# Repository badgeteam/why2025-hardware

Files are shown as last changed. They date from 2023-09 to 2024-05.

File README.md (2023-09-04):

# mch2025-hardware
Hardware design files for the MCH2025 badge

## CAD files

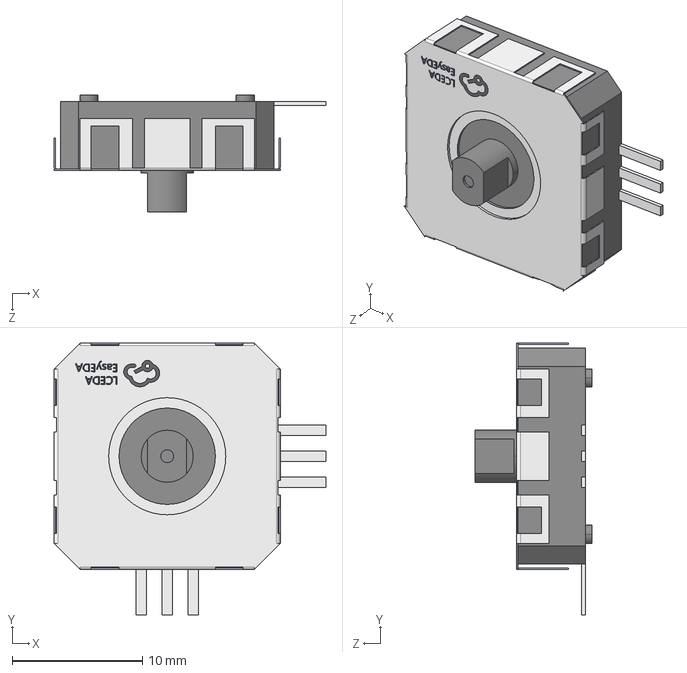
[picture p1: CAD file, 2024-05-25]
frontpanel/analog_joystick/SW-SMD_K1-1539SA-01.step
20.9 x 20.9 x 9.00 mm

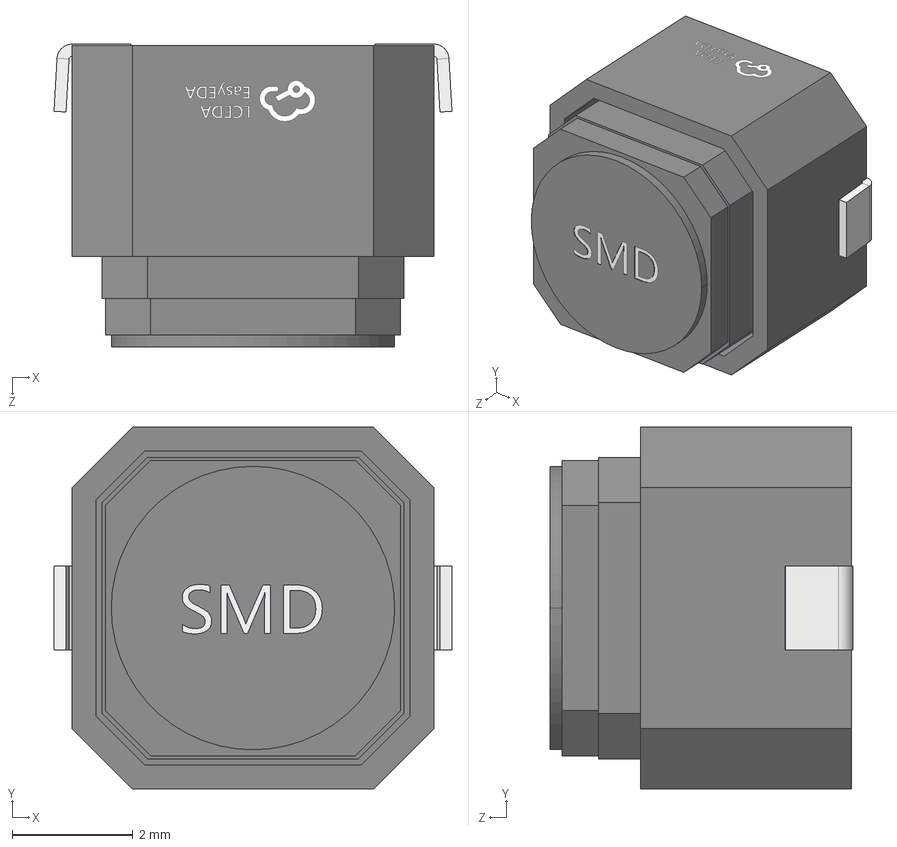
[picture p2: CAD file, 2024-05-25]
frontpanel/button_footprint/KEY-SMD_2P-L6.0-W6.0-H5.0-P6.00.step
6.60 x 6.00 x 5.02 mm

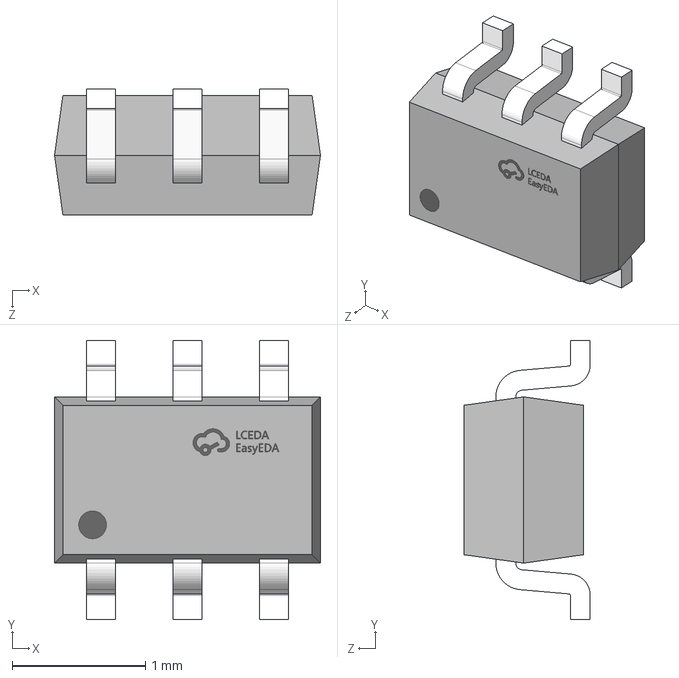
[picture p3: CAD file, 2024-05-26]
frontpanel/ideal_diode/SC-70-6_L2.0-W1.3-P0.65-LS2.1-BL.step
2.00 x 2.10 x 0.951 mm

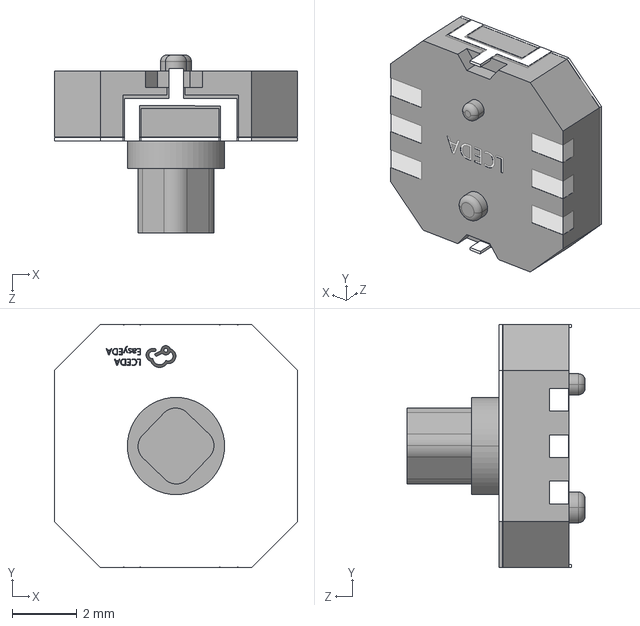
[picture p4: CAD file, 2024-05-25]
frontpanel/joystick_footprint/SW-SMD_SKRHABE010.step
7.50 x 7.50 x 5.50 mm

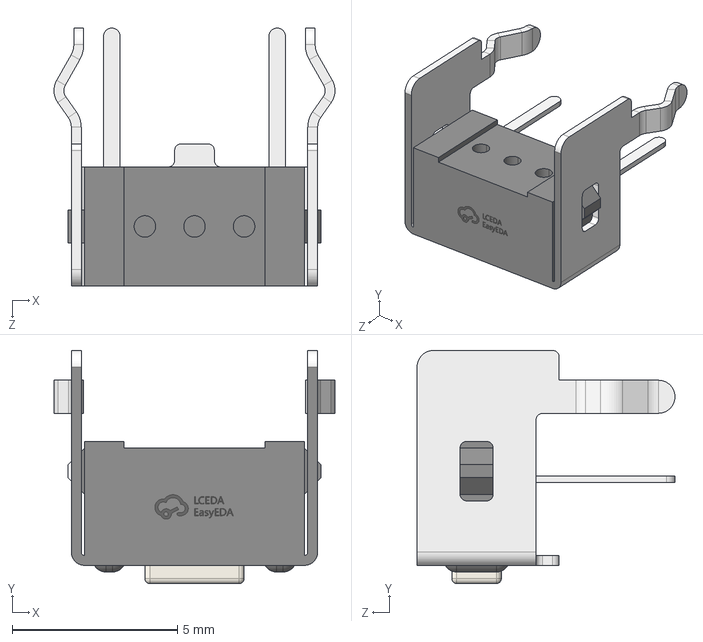
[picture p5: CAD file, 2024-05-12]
frontpanel/shoulderbutton/KEY-TH_4P-L7.5-W4.3-H4.3-LS7.0-P5.0.step
8.50 x 7.05 x 7.80 mm

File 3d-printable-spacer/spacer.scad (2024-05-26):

height = 2;

translate([0,0,height]) translate([0,0,height/2]) linear_extrude(height = height, center = true, convexity = 10, twist = 0, slices = 20, scale = 1.0, $fn = 16) import(file = "spacer.svg", center = true, dpi = 96);

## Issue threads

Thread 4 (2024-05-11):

P4 boot pins

renzenicolai, 2024-05-11:
- Add pullup resistors to GPIO 35 and 36
 - Add button to pull GPIO 35 to GND for entering boot mode

Closed 2024-06-15.

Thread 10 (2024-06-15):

USB device port problems

renzenicolai, 2024-06-15:
BQ25895 power negotiation is faulty and causes issues.

If we disable the power negotiation the vbus line of the usb port will always be 5v and thus it will be usable to power the usb hub directly.

- [x] Disconnect D+/D- from the BQ25895
- [x] Disconnect reset of USB hub from DSEL
- [x] Connect V5 pin of USB hub to USB_VBUS

ranzbak, 2024-07-27:
Put solder jumper in place, so the USB data lines are disconnected by default but can used when debugging.

renzenicolai, 2024-07-27:
In the end I just removed the USB port pins of the CH32. The usb serial converter idea of @ranzbak is much better so let's go with that.

Closed 2024-08-21.

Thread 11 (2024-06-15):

Power button

renzenicolai, 2024-06-15:
- [ ] Power button should pull the PWR_ON line to 3.3v, not GND

or

- [ ] Attach power button directly to QON (other side of transistor)
- [ ] Add high-resistance voltage divider to QON to feed back into CH32V203

renzenicolai, 2024-06-15:
Second solution is preferred

Closed 2024-08-21.

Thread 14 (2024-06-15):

Backlight dimming

renzenicolai, 2024-06-15:
Current approach with PWMing the enable signal isn't working great.

Research why, maybe find other methods for dimming backlight.

ranzbak, 2024-07-24:
- Suggestions: Make the connection to the 10uF capacitor thicker, to lower inductance.
- The PWM frequency is too high for the chip to follow?

They suggest something above 25kHz in the datasheet, but in the picture below it's up to 25kHz PWM.

So test with 25kHz PWM?

https://www.diodes.com/assets/Datasheets/AP3032.pdf page 10

Closed 2024-09-11.

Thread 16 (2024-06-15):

Fuses

renzenicolai, 2024-06-15:
The 2A fuses on both USB and on battery connector may need to be exchanged for a higher rated fuse as 2A is within normal operating conditions. Maybe use 3A fuses instead?

ranzbak, 2024-07-24:
I forgot what the problem was, the unrush current, or the fact that some devices can use more in general?

When the Fuses blowing results in a broken port, we might want to consider a poly fuse with a hold current of 2A.

https://www.lcsc.com/product-detail/Resettable-Fuses_BHFUSE-BSMD1206-200-6V_C883134.html

According to the datasheet the resistance is between 0.015 and 0.08Ω, which is 0.24V drop at 3A.

Closed 2024-08-21.

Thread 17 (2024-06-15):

Power switch for USB-A port and addressable LEDs

renzenicolai, 2024-06-15:
Add a power switch to turn off the USB-A port in standby mode. Disabling the booster in the PMIC does not result in 0 volt on the 5v pin of the USB connector but instead leaves VSYS on that line. It should be completely turned off.

Also a power switch would allow for setting a current limit.

ranzbak, 2024-07-24:
We can put in a p-channel FET, it'll be a small drop in voltage.

Something like this part ? https://www.lcsc.com/product-detail/MOSFETs_HXY-MOSFET-HXY2305AI_C3033391.html

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

Closed 2024-08-22.

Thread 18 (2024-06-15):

Connector of LCD

renzenicolai, 2024-06-15:
Current connector is too wide, replace with smaller replacement connector and adjust footprint.

Correct connector: DF37NB-24DS-0.4V(51)

https://www.digikey.nl/en/products/detail/hirose-electric-co-ltd/DF37NB-24DS-0-4V-51/2230603

ranzbak, 2024-07-22:
https://github.com/badgeteam/why2025-hardware/pull/32

renzenicolai, 2024-07-23:
To-do: verify that new connector is in the correct physical location.

ranzbak, 2024-07-23:
We need to do that with a real prototype I guess :-).

Closed 2024-07-27.

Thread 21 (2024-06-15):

Change footprint of P4 to match production version

renzenicolai, 2024-06-15:
Also make the pins accessible from the side of the chip, for fixing faulty connections by hand.

renzenicolai, 2024-07-14:
- [ ] Acquire up-to-date datasheet
- [ ] Acquire new chips (send to Allnet)

Closed 2024-08-21.

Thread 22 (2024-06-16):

Discuss and choose size of backplate screw holes

renzenicolai, 2024-06-16:
Prototype 1 has M2 holes in the mainboard. These could be replaced by 1.6mm holes to attach a base the same way as the frontpanel, we could look into using solderable nuts or we could find a way to allow for attaching a case from the front, screwing the M2 bolt into the plastic of the case.

This all needs more research.

Closed 2024-08-22.

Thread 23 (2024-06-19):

Speaker gets hot

renzenicolai, 2024-06-19:
Needs research.

One idea is that we may even be able to get away without the amplifier.

- [ ] Test how loud the speaker is when directly connected to the DAC.
- [ ] Test if HPCOM can be used to control speaker on/off.
- [ ] Test if transistor can be used to switch low side of speaker (add diode?).

ranzbak, 2024-07-15:
Please check out : https://github.com/badgeteam/why2025-hardware/pull/29

Closed 2024-08-21.

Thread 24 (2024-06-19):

Camera pinout mirrored

renzenicolai, 2024-06-19:
Currenct connector is bottom contact.

- [ ] Switch to top contact connector

ranzbak, 2024-07-14:
What you are trying to say is that the pins 1 -> 22 needs to be 22->1 ?

Closed 2024-07-27.

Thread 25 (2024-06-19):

Unstable power rail / USB device port connection

renzenicolai, 2024-06-19:
Needs some more testing and research, the VSYS rail seems very unstable.

renzenicolai, 2024-07-14:
Turns out you can configure the current taken from the usb device port on the PMIC. We did that and now it's stable.

ranzbak, 2024-07-22:
Close this one in that case?

renzenicolai, 2024-07-22:
Nah, needs some more playing around with. For example the USB-A port can still cause the P4 do go into brownout so there is more stuff wrong here. I think it's mainly to do with the voltage on the VSYS rail still. Maybe we should look for a DC-DC for the 3.3v rail that can handle lower input voltages.

renzenicolai, 2024-07-27:
Check that the DC-DC has a low enough minimum input voltage to be able to use the whole battery.

Closed 2024-08-21.

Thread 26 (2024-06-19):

Disconnect PMIC from D+ / D- of device port

renzenicolai, 2024-06-19:
Negotiation is bugged (see chip errata) and causes issues. Also if we don't connect this VBUS is always 5v, which is nice because then we can power the USB hub IC directly from VBUS.

renzenicolai, 2024-06-21:
Disconnected D+ and D- from PMIC, disconnected RESET of USB hub from PMIC and connected 5V pin of USB hub to VBUS.

Note: the USB hub has a built-in pull-up resistor on the RESET line.

Closed 2024-06-21.

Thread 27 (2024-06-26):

Battery

renzenicolai, 2024-06-26:
- Check if we can find an 18650 battery holder with a footprint that fits in the keyboard matrix area
 - Maybe move the keyboard matrix wiring to an inner layer, we don't need the 3.3v power layer on the lower half of the board anyway.

ranzbak, 2024-07-22:
The battery at the bottom, wouldn't that be more stable?
Also we might want to tape the battery to the prototype and see where it holds best.
Also with the battery at the bottom it might even stand up by it self. (bonus)

Closed 2024-08-22.

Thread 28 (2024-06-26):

Turn on backlight by default

renzenicolai, 2024-06-26:
When the CH32V203 isn't active the display backlight should be on at full brightness.

ranzbak, 2024-07-15:
Given that the pb3 will be high impedance after reset, pull the pin up using the 100k resistor to VCC?
@Renze, do you know if the pin is in high impedance after reset, or when the ch32v203cxt6 is disabled, I couldn't find in the datasheet.

ranzbak, 2024-07-27:
Done

Closed 2024-07-27.

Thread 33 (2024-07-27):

Check protection circuit

renzenicolai, 2024-07-27:

ranzbak, 2024-07-27:
The rail to in v-in is ~1.5V for the LM339, when supplied with 3.3V, the max is 1.8V that can be compared.
So a rail to rail sulution is needed.

LCSC nummer: C4944986
Not too expensive: https://www.lcsc.com/product-detail/Operational-Amplifier_UMW-Youtai-Semiconductor-Co-Ltd-LMV324IDR_C4944986.html
Datasheet: https://www.lcsc.com/datasheet/lcsc_datasheet_2312211124_UMW-Youtai-Semiconductor-Co---Ltd--LMV324IDR_C4944986.pdf

ranzbak, 2024-07-29:
The 1V reference was pulled down to 1V.
Looked at voltage references to provide the 1V, they are pretty expensive.
When looking into the problem further we are trying to solve, protecting the chips from over voltage limiting the voltage is enough.
Given that the p4 at max can deliver 100mA current, a Zener that clamps the voltage is sufficient to protect the IC's involved.

Long story short, replaced the VPSRAM, VMIPI, VFLASH rail protection with zener diodes.
VESPHP is unprotected as the voltage is set by a resistor devider, en de EN_DCDC P4 can already disable the U3 vcore regulator if it's unhappy.

ranzbak, 2024-07-29:
https://github.com/badgeteam/why2025-hardware/pull/39

Closed 2024-08-21.

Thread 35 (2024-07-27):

Add USB to serial converter for programming P4

renzenicolai, 2024-07-27:

renzenicolai, 2024-07-27:
Maybe also connect it to P4 reset & boot pins via the special circuit found on most ESP32 devboards (see P4 devkit schematic)

Closed 2024-08-21.

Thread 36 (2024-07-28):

Add Bosch sensors

renzenicolai, 2024-07-28:

JayVisschedijk, 2024-07-28:
Design symbol, footprint, test board for sponsored Bosch sensors

JayVisschedijk, 2024-07-28:
How many sensors are we talking about? And do we already know which ones specifically?

renzenicolai, 2024-07-28:
Position sensor BHI360 and gas sensor BME690 :smile:

JayVisschedijk, 2024-07-28:
For the BHI360 symbol and footprint:
https://www.snapeda.com/parts/BHI360/Bosch/view-part/

About the BME690 I can't find enough info on their site, did we receive inside information we can use to create a symbol and footprint?

renzenicolai, 2024-07-29:
BHI360 needs 1.8v IO voltage. That's a bit annoying because we'd need to add a regulator and a level shifter for the I2C bus.

Closed 2024-08-22.

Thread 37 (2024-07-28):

Hexpansion

renzenicolai, 2024-07-28:
Maybe we can fit this on there somewhere?

https://www.lcsc.com/product-detail/Card-Edge-Connectors_HCTL-HC-SFP-20P_C2897291.html

https://tildagon.badge.emfcamp.org/
https://tildagon.badge.emfcamp.org/hexpansions/creating-hexpansions/

renzenicolai, 2024-07-28:
Had a play with the two holes and SFP connnector on our board and I can't find any space to put it. Alternative could be to make a backplate that adds hexpansion ports, let's go with that.

Closed 2024-08-21.

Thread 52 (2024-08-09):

Move PMIC closer to battery terminal

renzenicolai, 2024-08-09:
VBAT on the PMIC drops too much.

Closed 2024-08-21.

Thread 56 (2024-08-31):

LED level shifter

renzenicolai, 2024-08-31:
Choose a different buffer, this one is just as much out of spec as the LEDs themselves.

renzenicolai, 2024-08-31:
https://www.lcsc.com/product-detail/Buffer-Driver-Transceiver_Nexperia-74LVC1G17GW-125_C426705.html

Pincompatible, but with correct voltages.

Closed 2024-09-11.

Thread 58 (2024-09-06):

Do we need changes to the spacer between the PCB's to account for the LORA antenna?

ranzbak, 2024-09-06:

renzenicolai, 2024-09-12:
The spacer will be (re)designed by Yvo to take into account all the little bits of metal in the way.

Closed 2024-09-12.

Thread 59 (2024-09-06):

VESPHP now is very close to 1.20V which is the max voltage, would 1,12 V be better?

ranzbak, 2024-09-06:
Replacing R40 with a 430K resistor would put the set voltage at 1,12V.

In the ESP32 P4 sheet (V0.4), page 62 bottom of the page for reference.

arturo182, 2024-09-08:
Surprisingly, the official Espressif EV Board also uses 2x499K:

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

From https://docs.espressif.com/projects/esp-dev-kits/en/latest/_static/esp32-p4-function-ev-board/schematics/esp32-p4-function-ev-board-schematics.pdf

This of course is:

$$0.6V * (1 + \frac{499K}{499K}) = 1.2V$$

My guess would be this is because the ESP32-P4 uses the `FB_DCDC` pin to adjust the voltage as needed so the default of 1.2V as a starting point is not a problem for them?

renzenicolai, 2024-09-11:
Yeah, I checked and the rev 0.1 version of the development board still has it like this in the schematic, let's copy what Espressif does 😄

Closed 2024-09-11.

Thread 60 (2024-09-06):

CH334R can operate without crystal, option ?

ranzbak, 2024-09-06:
In the datasheet, chapter 6.2:

6.2 Crystal-free Application, Bus-powered

renzenicolai, 2024-09-11:
I'm not sure the CH334R can be ran without crystal. However it is easy enough to test this by removing the crystal and shorting a specific signal pin to ground. I can try testing this on one of the non-working boards tomorrow.

renzenicolai, 2024-09-12:
Tested, doesn't work with the version of the CH334R we have.

arturo182, 2024-09-12:
The datasheet is a bit confusing on this, like it's a specially ordered version?
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

Closed 2024-09-12.

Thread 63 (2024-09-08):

Camera connector needs two gpios, not one.

renzenicolai, 2024-09-08:
https://www.raspberrypi.com/documentation/computers/raspberry-pi.html#raspberry-pi-zero
https://www.arducam.com/raspberry-pi-camera-pinout/

Closed 2024-09-11.

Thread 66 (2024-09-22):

Bringup of WHY2025 prototype 2

renzenicolai, 2024-09-22:
Power:
- [x] Check for short circuit on VBUS rail
- [x] Check for short circuit on 3.3v rail
- [x] Power device via USB without battery attached
- [x] Check 3.3v rail voltage
- [x] Check 2.5v standby rail voltage
- [x] Check VSYS rail voltage
- [x] Check 1.8v rail
- [x] Check battery connector voltage
- [x] Check powering badge from battery
- [x] Check charging of battery
- [x] Measure power usage

Basic device bringup:
- [x] Check that USB hub works
- [x] Check that C6 shows up via USB
- [x] Check that USB serial converter shows up via USB
- [x] Access P4 using esptool.py via the USB-serial chip (works after swapping rx/tx)
- [x] Flash firmware to P4 using esptool.py (via usb-serial)
- [x] Flash firmware to C6 using esptool.py (via native USB)

In- and output interfaces:
- [x] Check display
- [x] Check SD card reader
- [x] Check keyboard buttons
- [x] Check boot button
- [x] Check power button
- [ ] Check I3C functionality
- [x] Check powering USB-A connected device on USB power
- [x] Check powering USB-A connected device on battery power
- [x] Check USB-A host port
- [ ] Check that camera works
- [x] Test JTAG interface
- [x] Test GPIOs on external expansion header
- [x] Test GPIOs on internal expansion header
- [x] Check display backlight
- [x] Check keyboard backlight
- [x] Check PWM dimming of display backlight
- [x] Check PWM dimming of keyboard backlight

On-board communication:
- [x] Check SDIO communication between P4 and C6
- [x] Check that CH32V203 can be programmed by P4
- [x] Check I2C communication on internal I2C bus
- [x] Check i2C communication on power management I2C bus
- [x] Check power button press emulation for CH32V203

renzenicolai, 2024-10-06:
In need of firmware to test:
 - Camera (a simple camera to screen firmware would be super useful)
 - USB-A port (a simple USB host example would be super useful)

renzenicolai, 2024-11-01:
Unable to test camera port at this time, skipping test.

renzenicolai, 2024-11-01:
To be continued in https://github.com/badgeteam/why2025-hardware/issues/95

Closed 2024-11-01.

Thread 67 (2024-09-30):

esp32p4.kicad_sch lists wrong part number for U8

michaesc, 2024-09-30:
## Context

The schematic (and layout) claims that the LCSC part number C22387510 corresponds with a part labeled flash, probably the external storage used by the P4.

## Problem

The LCSC database has no entry for the part number C22387510, so this is possibly an error or a incorrect entry.

## Solution

If the part U8 is a real part sold by LCSC, then the correct part number should be recorded in the schematic.

michaesc, 2024-09-30:
The U8 is not really a flash storage part, and the LCSC part number is correct. The reason that LCSC fails to find it today is due to a early entry for the ESP32-P4 part that is not avialable yet.

Closed 2024-09-30.

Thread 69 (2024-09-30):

Add pull-up resistor to GPIO34

renzenicolai, 2024-09-30:
For using the JTAG interface GPIO34 (E2 on the internal expansion port) can be used to select between USB jtag and the JTAG pins on the external expansion port.

Add a pull-up resistor to E2 (GPIO34) to select USB jtag by default on boards where this fuse has been burned.

 - burn JTAG_SEL_ENABLE to 1
 - pull E2 (GPIO34) low
 - reset ESP32-P4

Maybe we could add a footprint for a 10-pin JTAG header too somewhere?

renzenicolai, 2024-09-30:
Extra ideas:
 - Add testpoint to P4 reset pin next to the RX and TX pins
 - Add solder jumper for shorting E2 to ground

ranzbak, 2024-10-04:
Pullup resistor 51K added to GPIO34.

Leaving the ticket open for a bit to see if there is space for a 10 pin JTAG header.

renzenicolai, 2024-10-06:
Continued in #82

Closed 2024-10-06.

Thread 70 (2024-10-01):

Trace under impedance resistors USB line move

ranzbak, 2024-10-01:
On the board, from the USB hub to the C6, the Lora int line runs under the two impedance match resistors.

R17 and R18.

The trace should be rerouted to around the USB signal.

This is needed because the signal being between the resistors and the ground plain, breaks the ground reference for the diff pair signal.

ranzbak, 2024-10-04:
C6 interrupt line moved.

Closed 2024-10-04.

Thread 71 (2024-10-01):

ESP32-C6 USB interface problems

renzenicolai, 2024-10-01:

renzenicolai, 2024-10-06:
Workaround: add 1.5k resistor between C6 EN pin and D+

renzenicolai, 2024-10-06:
Workaround implemented in board design.

ranzbak, 2024-11-01:
For now we leave the workaround resistor in, as the solution is stable.
If Espressif comes with the real solution we can implement that.

Closed 2024-11-01.

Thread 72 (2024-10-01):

Screwhole bottom center needs to be moved down a bit

renzenicolai, 2024-10-01:

renzenicolai, 2024-10-01:
2mm

ranzbak, 2024-10-04:
Done moved hole down 2 mm, 'Protype 2' silkscreen now does not fit anymore.

Moved it to the Prototype silkscreen to the right.

Closed 2024-10-04.

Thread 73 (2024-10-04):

VBUS to connect <-> pmic trace not wide enough

ranzbak, 2024-10-04:
Given that the badge needs to be powered from USB-C even when no battery is present, the 0.45mm from the USB-C connector to the PMIC is not wide enough.

Suggest 1.2mm(+?) wide track to the PMIC to keep the impedance and voltage drop as low as possible between the USB-C port and the PMIC.

After the PMIC the trace can continue narrower as the current will be lower in that segment.

ranzbak, 2024-10-04:
Lagest part of the USB-C connector to the PMIC is 1.2mm wide, which should result in a lower voltage drop.

Closed 2024-10-04.

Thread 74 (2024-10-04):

Add P4 reset to the expansion header

Orange-Murker, 2024-10-04:

ranzbak, 2024-10-04:
What pin do we disconnect from the expansion header to make space?

renzenicolai, 2024-10-05:
none, of we can add a 10 pin jtag header that would be amazing (like mentioned in #69)

if not then we could just add either a small extra header footprint or extend the side exp. header by two pins

renzenicolai, 2024-10-06:
Continued in #82

renzenicolai, 2024-10-06:
Might still be useful to add an extra 1x02 to the external expansion port, containing JTAG detect and P4 reset

renzenicolai, 2024-11-01:
Solved by assigning GPIO34 as SAO IO 2 to allow selecting JTAG mode and exposing the P4 reset on one of the PMOD power pins.

Closed 2024-11-01.

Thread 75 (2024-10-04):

Add extra capacitors to the backlight driver on VSYS

ranzbak, 2024-10-04:
On the V1 back light driver PWM cause display corruption.

Add extra capacitance to decouple the backlight driver from the VSYS bus.

ranzbak, 2024-10-04:
Added C89 10 u at the VSYS near to the backlight driver.

renzenicolai, 2024-10-16:
Closing this, continue in #84

Closed 2024-10-16.

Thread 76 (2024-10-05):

Swap camera GPIO and addressable LEDs between C6 and CH32

renzenicolai, 2024-10-05:
It makes much more sense to control the LEDs via the CH32.

Idea is to have the C6 control the camera GPIO and have the CH32 control the LEDs instead.

renzenicolai, 2024-10-06:
Two extra pins needed on CH32:
 - 1: swap LED_DATA on C6 and CAMERA on CH32
 - 2: attach LED_ENABLE to BOOT pin of C6 (which is attached to the CH32) and move the LORA_RESET to the C6 pin that was LED_ENABLE

Closed 2024-11-01.

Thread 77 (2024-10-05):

Add PMID SW diode for better stability and efficiency of the PMIC

ranzbak, 2024-10-05:
SW to PMID diode Help to improve the efficiency. Recommend for applications with greater than 2.4A boost mode ouput.

From this document : https://e2e.ti.com/cfs-file/__key/communityserver-discussions-components-files/196/BQ25895_5F00_SchematicChecklist-V1p1.pdf

Since we see VBatt / VSYS interactions, and have problems at high current, we might want to add this diode.

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

ranzbak, 2024-10-05:
In commit d410a64c0f7fcd8e44ddb87f60cdcf2cb8bcdb74 the Diode has been added, this should at least make the OTG power more reliable.

renzenicolai, 2024-10-06:
Seems fixed.

Closed 2024-10-06.

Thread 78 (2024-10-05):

SAO pinout mirrored

renzenicolai, 2024-10-05:
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

Somehow I always manage to screw this one up.

renzenicolai, 2024-10-06:
Fixed.

Closed 2024-10-06.

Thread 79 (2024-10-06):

CH334R does not have enough capacitance on 3v3

ranzbak, 2024-10-06:
The current schematic puts 100n + 1u on pin 13 of U4.

According to the datasheet page 27 this should be 100n + 10u

In the description below the schematic it's stated that in case of stability, this can be increased to 22uF.

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

ranzbak, 2024-10-06:
Change the 1u to 10u, add another unpopulated 10u footprint next to the crystal in case it's needed.

renzenicolai, 2024-10-06:
Changed to 10u, added another footprint for a 10u, also added an extra 1u on VSYS

renzenicolai, 2024-10-16:
Extra capacitors have been added, so this ticket can be closed.

Closed 2024-10-16.

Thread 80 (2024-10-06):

Last piece of the USB bus host to C6 is not routed correctly

ranzbak, 2024-10-06:
The lines between the resistors and the C6 should be routed like the rest of the diff pairs.

Not a low hanging could have.

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

renzenicolai, 2024-10-06:
Fixed.

Closed 2024-10-06.

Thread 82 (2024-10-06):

Add 10 pin JTAG connector

renzenicolai, 2024-10-06:
As per suggestions in

#69 #74

ranzbak, 2024-10-18:
Added 2 extra pins to the SAO/PMOD connector.

The two extra pins are do not populate, as this keeps the current SOA/PMOD connector clean.

ranzbak, 2024-11-01:
Solved by moving JTAG to the CATT header.

Closed 2024-11-01.

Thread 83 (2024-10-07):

Thermically decouple Bosh sensor with keep out zones

ranzbak, 2024-10-07:
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

On both sides a keep out zone can interrupt the copper layers.

ranzbak, 2024-10-18:
Fixed in last push, all floods now restricted to the area around the I2C bus, to minimize temperature coupling.

Closed 2024-10-18.

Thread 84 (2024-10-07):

Backlight driver pretty noisy on the power rail VSYS

ranzbak, 2024-10-07:
Thanks to Renze :

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

This basically happens when the backlight is dimmed using PWM on the controller pin.

Several things can be done all with their own downsides :

- Add more capacity close to the display backlight controller
- Add a ferrite core before the capacitors, to reject the noise there
- Determine if the noise is problematic, if not leave it as is
- The datasheet describes an alternate method for diming, investigate that.

ranzbak, 2024-10-18:
After using the scope to see if the difference in current drawn from the battery / USB power supply caused problematic rippling on the power rail voltage, we concluded, that the ripple (<70mV) is within the voltage ripple tolerance of the IC's used on the board.
So this is a no-fix.

Closed 2024-11-01.

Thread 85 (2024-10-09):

LORA SMA header too wide

ranzbak, 2024-10-09:
Testing an SMA connector at the SMA footprint, I found the current footprint to be too wide.

Replace the too wide footprint with the other narrower footprint.

ranzbak, 2024-10-10:
The footprint : Connector_Coaxial:SMA_Samtec_SMA-J-P-H-ST-EM1_EdgeMount

Fits the SMA connectors

7mm wide at the base.

ranzbak, 2024-10-10:
Commit pushed, footprint changed.

Closed 2024-10-10.

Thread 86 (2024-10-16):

Bosch environmental sensor: switch to BME688

renzenicolai, 2024-10-16:
Switch Bosch sensor to https://jlcpcb.com/partdetail/BoschSensortec-BME688/C3664478

ranzbak, 2024-10-18:
This IC does not have a Gyroscope/accelerometer, is this feature going to be dropped?

geekyjoyce72, 2024-10-18:
That would be the separate BHI360 chip

ranzbak, 2024-10-18:
Thanks, replace the BME680 with the BME688 on the design, pushed result, please close after verification.

renzenicolai, 2024-11-01:
Note: design has two Bosch sensors:

A BHI360 for position sensing

and the BME688 for environmental sensing. The BME680 is pin-compatible with the BME688.

Closed 2024-11-04.

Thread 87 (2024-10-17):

Voltage Buck/boost converter still needed?

ranzbak, 2024-10-17:
At this moment, there is a VSYS coming out of the PMIC that follows the battery voltage.

According to the datasheet, the PMIC can keep the VSYS at a configured voltage.

As it stands, we cannot enable this feature,  even when 3.75V is set the VSYS still follows the VBAT.

At this moment we 'fixed' this by using the TPS63020, which is $0.4221 for 100+ units on LCSC.

If we can get the VSYS minimal voltage working, we can switch to a buck converter like on prototype one :
TLV62595DMQR at a price of : $0.3604

Which would save given me make 4500 units: 277,65 euro

Worth it to spend time and effort, to get the PMIC configured?

ranzbak, 2024-10-18:
Had a short discussion with Renze about this.

Given :

- VSYS after many hours of configuring the PMIC still doesn't regulate correctly
- Dips in VSYS were observed in the Prototype 1 board, during connecting/disconnecting of USB devices

The statements above result in risk of instability in a buck only solution, and a commitment for more engineering hours to solve the VSYS problem.
The two reasons above are enough to just buy of the problem with a buck-boost converter at 277 euro.

Closed 2024-10-18.

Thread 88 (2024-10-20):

Swap E2 and SAO IO2

renzenicolai, 2024-10-20:
E2 (GPIO34) en SAO IO2 (GPIO0) omwisselen op de P4 zodat we krijgen: E2=GPIO0, SAO IO2=GPIO34

ranzbak, 2024-10-20:
Fixed in commit 5833a04e83a3e18b5ff4a887d21beb78078f4aec, Pin 13 of the connector can now double as P4 reset.

ranzbak, 2024-10-20:
Close when verified please.

Closed 2024-11-01.

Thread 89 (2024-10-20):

I2C bus lockup when enabling C6

renzenicolai, 2024-10-20:
Sometimes the coprocessor stops responding for a bit when enabling the C6, exact origin of the problem is unknown, logic analyzer testing needed.

ranzbak, 2024-10-27:
Coprocessor = ch32 I presume?

Is this during the startup sequence (In other words how is the problem reproduced)?

ranzbak, 2024-10-27:
Question :
bsp_platform_init:26
The maximum_speed is net set, could this be related?

renzenicolai, 2024-11-01:
Workaround: bus recovers quickly after C6 causes weird behaviour. Solved by allowing bus errors to occur and properly recovering from them.

Closed 2024-11-01.

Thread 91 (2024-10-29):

Battery connector current limit

renzenicolai, 2024-10-29:
Add polyfuse? 2A?
Maybe also add power switch with current limit to USB-A port, at 1A?

renzenicolai, 2024-10-29:
https://www.lcsc.com/product-detail/Power-Distribution-Switches_WCH-Jiangsu-Qin-Heng-CH217K_C7462749.html

Interesting chip, could also replace the power switch currently used for switching LED power

renzenicolai, 2024-10-29:
After discussion we reached the following conclusion:

- [ ] Limit output current on the USB-A port to 1A, that should be enough for any device except for big external harddisks and phones that try to charge
- [ ] Limit charge current setting range to 1A (this can easily be done in software), default charge current will be 500mA

renzenicolai, 2024-11-01:
https://github.com/badgeteam/why2025-hardware/issues/94

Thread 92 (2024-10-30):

Ch32 RTC pulse too short to wake up badge from sleep

ranzbak, 2024-10-30:
@renzenicolai managed to get the RTC (Real time clock) working, allowing from alarms to be set.
When the alarms trigger, the PC13 pin pulses, to wake up the badge, this pulse is 3 us.
Problem is that the PMIC needs ~2 seconds to wake up.

Make a solution to produce a PMIC wake up, long enough.

ranzbak, 2024-10-30:
Solution proposed:

Have an SR latch (Set reset latch)

Where the :
- Set is connected to the CH32 PC13 pin, that will set the latch when the badge is in sleep.
- Reset is connected to the 3v3 rail (because easy routing) and resets the latch when the power rail comes up.

In the situation that the PC13 triggers during the badge being awake, the latch will be in error condition for 30us, which is not long enough to switch the badge off or do anything, so this is a don't care condition.

The SR-latch is built using a dual NOR gate IC, and powered by the 2.5V rail that stays active when the badge is in deep sleep.

The implementation is placed at the bottom right of the 'Coprocessor' schematic.

Please close issue when reviewed.

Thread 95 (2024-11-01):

Bringup of WHY2025 prototype 3

renzenicolai, 2024-11-01:
- [ ] Test I3C
- [ ] Test camera
- [ ] Test RTC wakeup
- [ ] Test power consumption when off
- [ ] Test power consumption when on

Closed 2024-12-16.

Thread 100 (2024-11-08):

Space behind the screw holes for the extension board

ranzbak, 2024-11-08:
The two holes to connect the extension board left and right of the C6 need space in the spacer to hold the screws, are these spaces present in the design ?

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

renzenicolai, 2024-11-10:
There are nuts in the spacer for receiving a bolt attached through a housing from the back.

ranzbak, 2024-11-10:
Perfect, that closes this issue.

Closed 2024-11-10.

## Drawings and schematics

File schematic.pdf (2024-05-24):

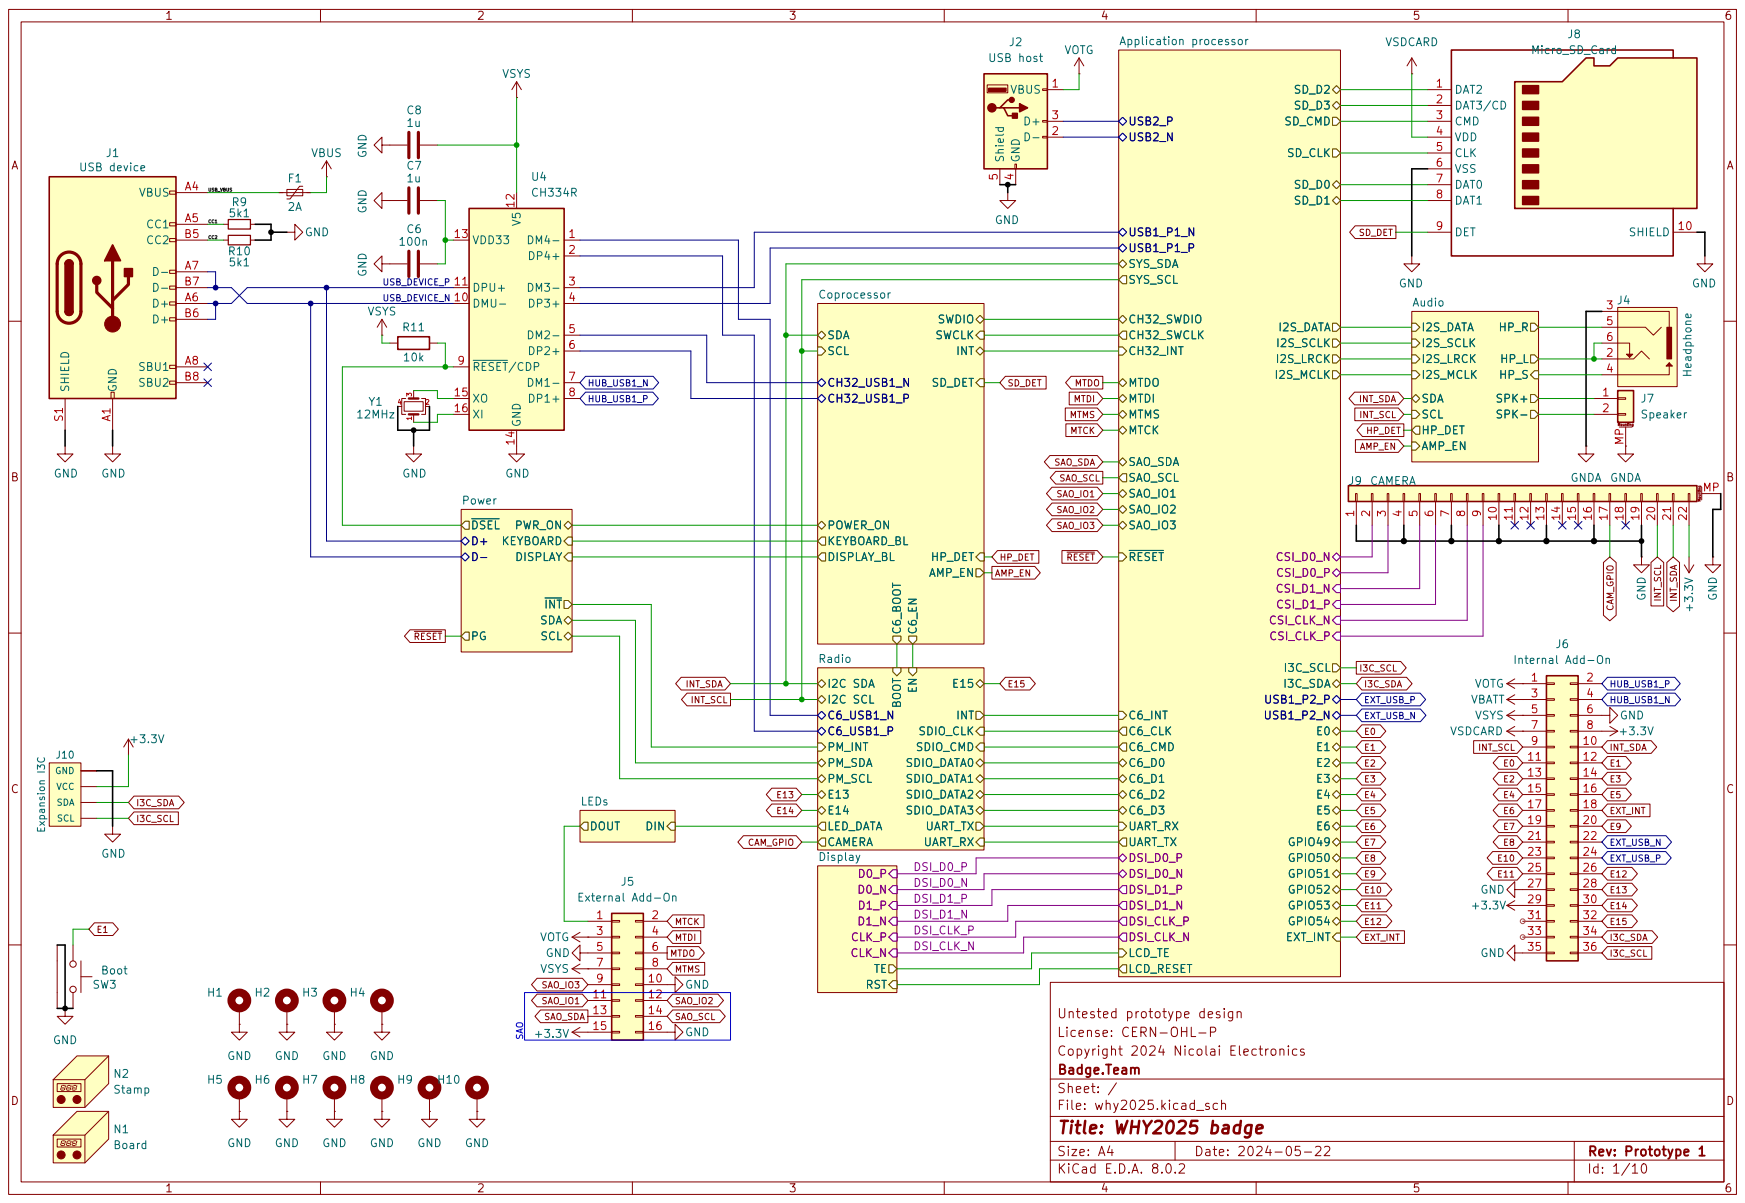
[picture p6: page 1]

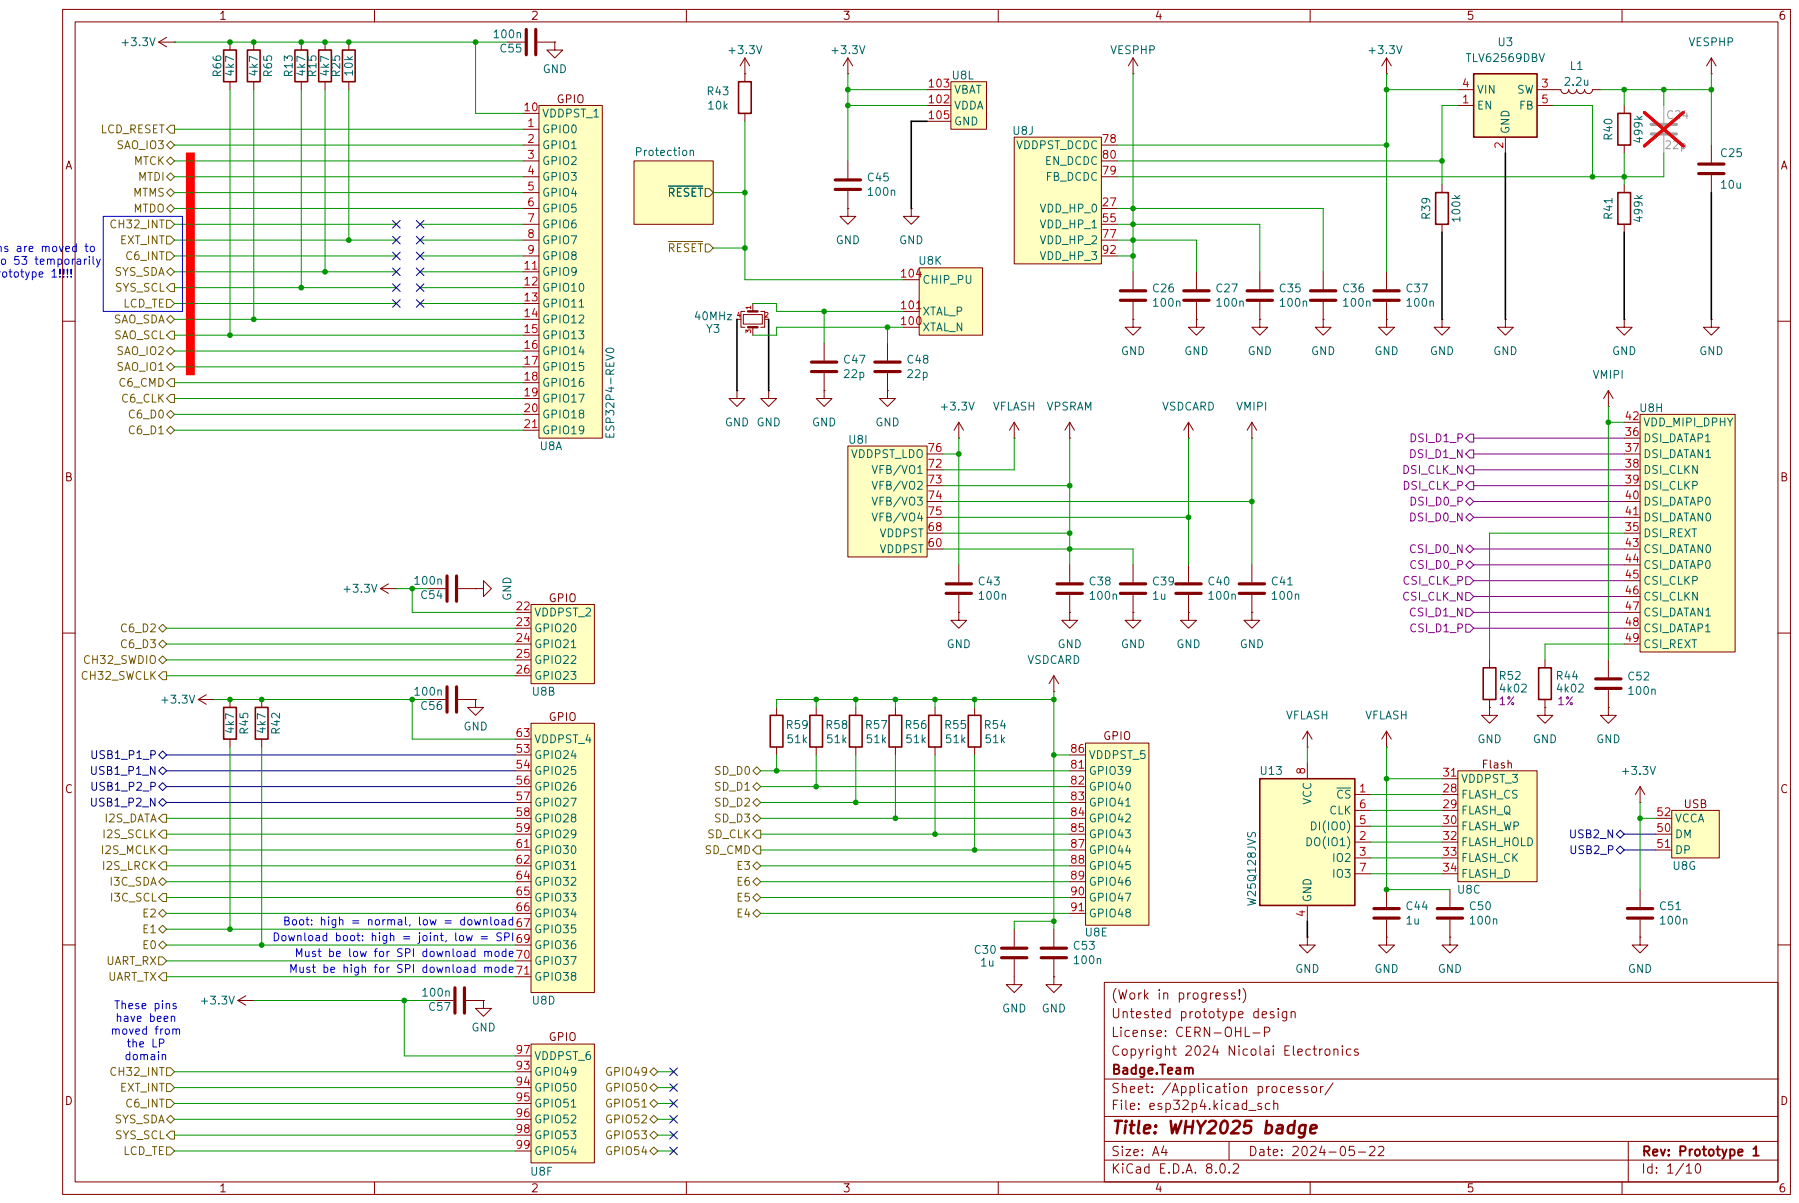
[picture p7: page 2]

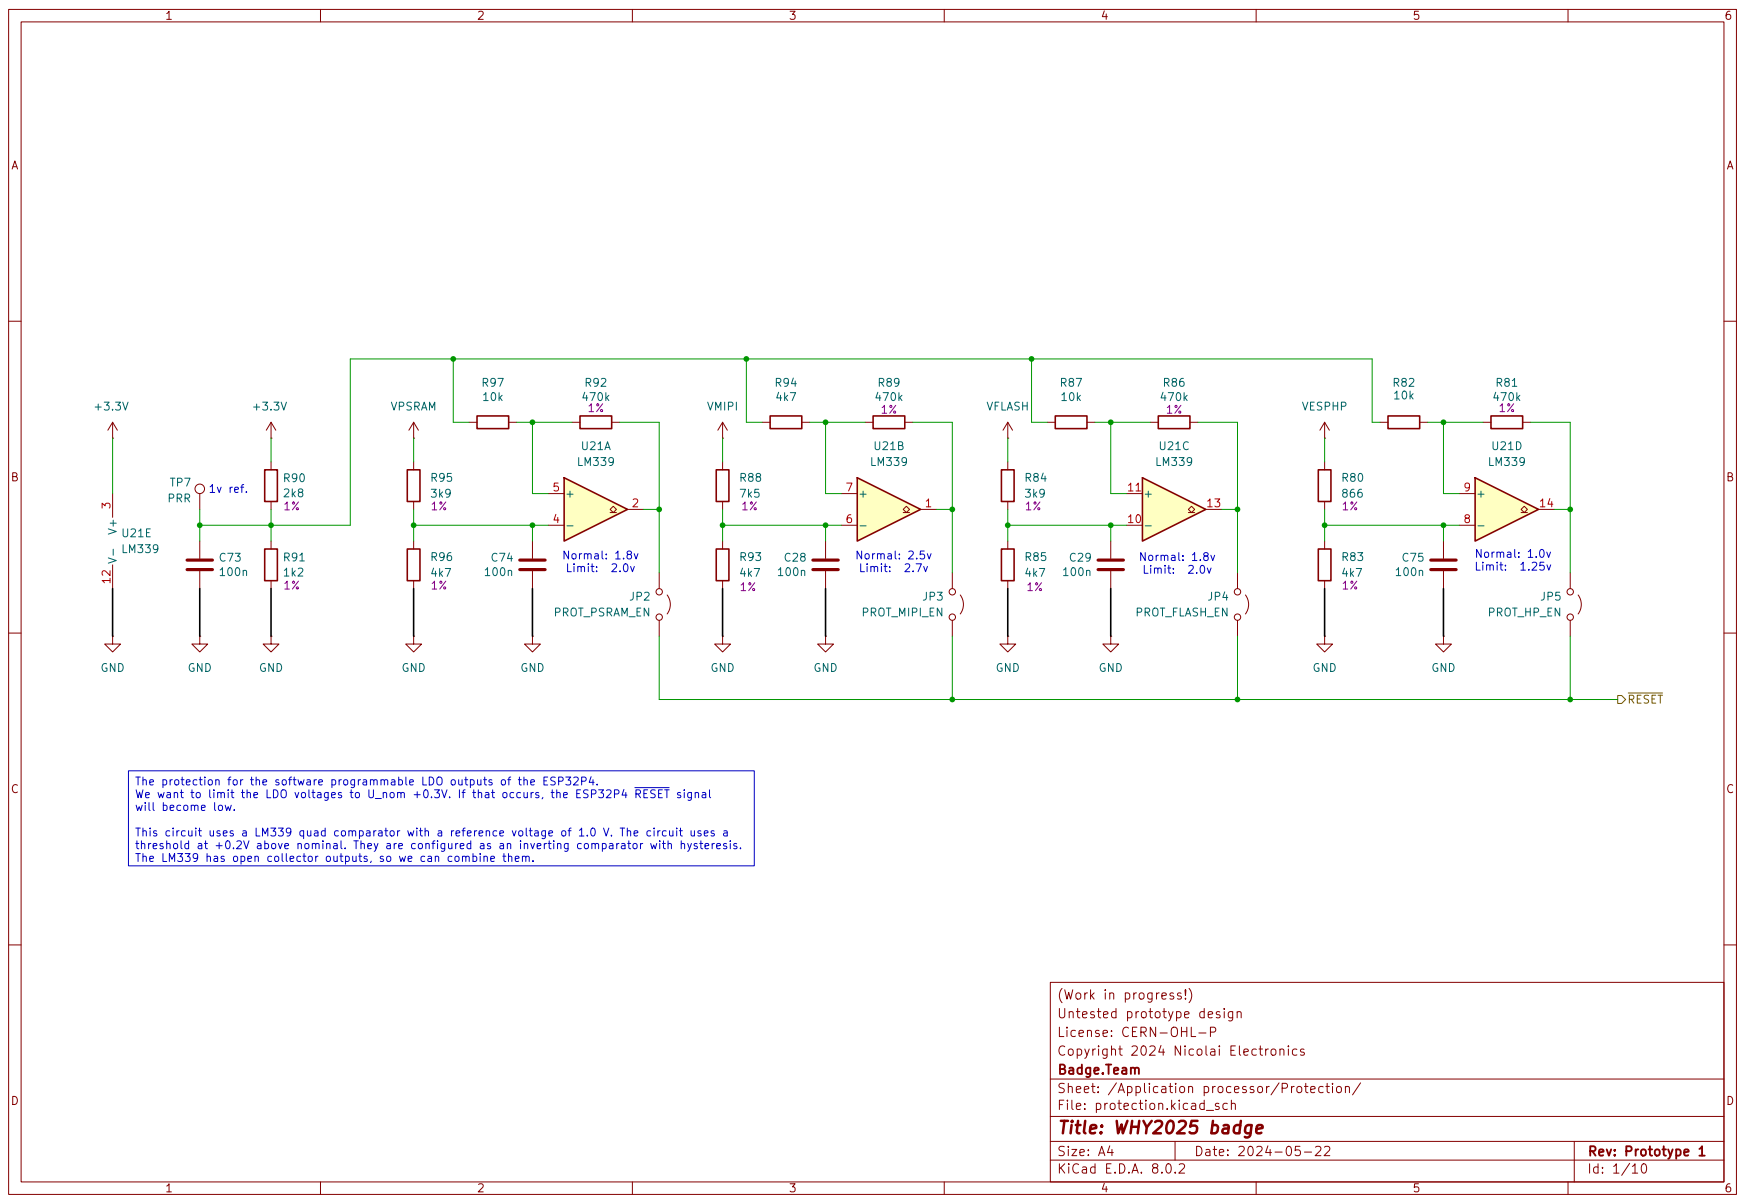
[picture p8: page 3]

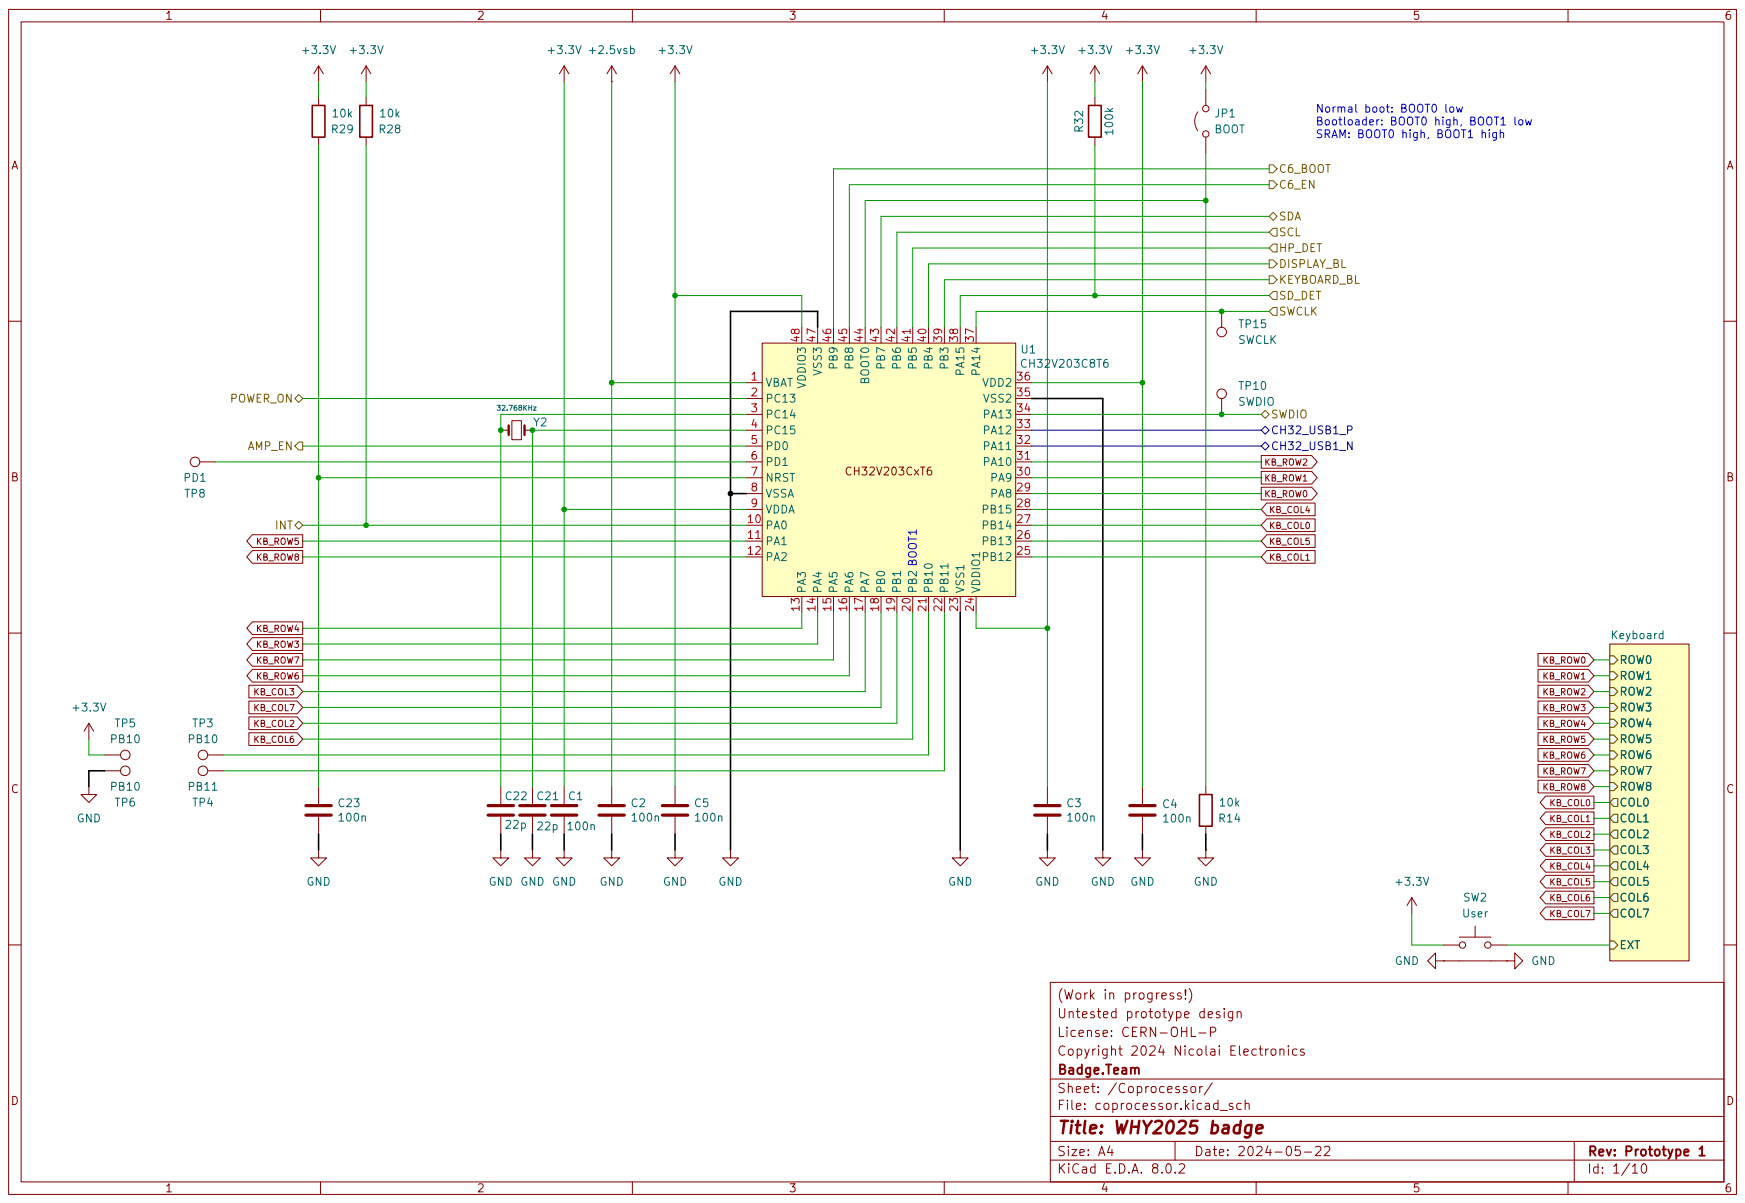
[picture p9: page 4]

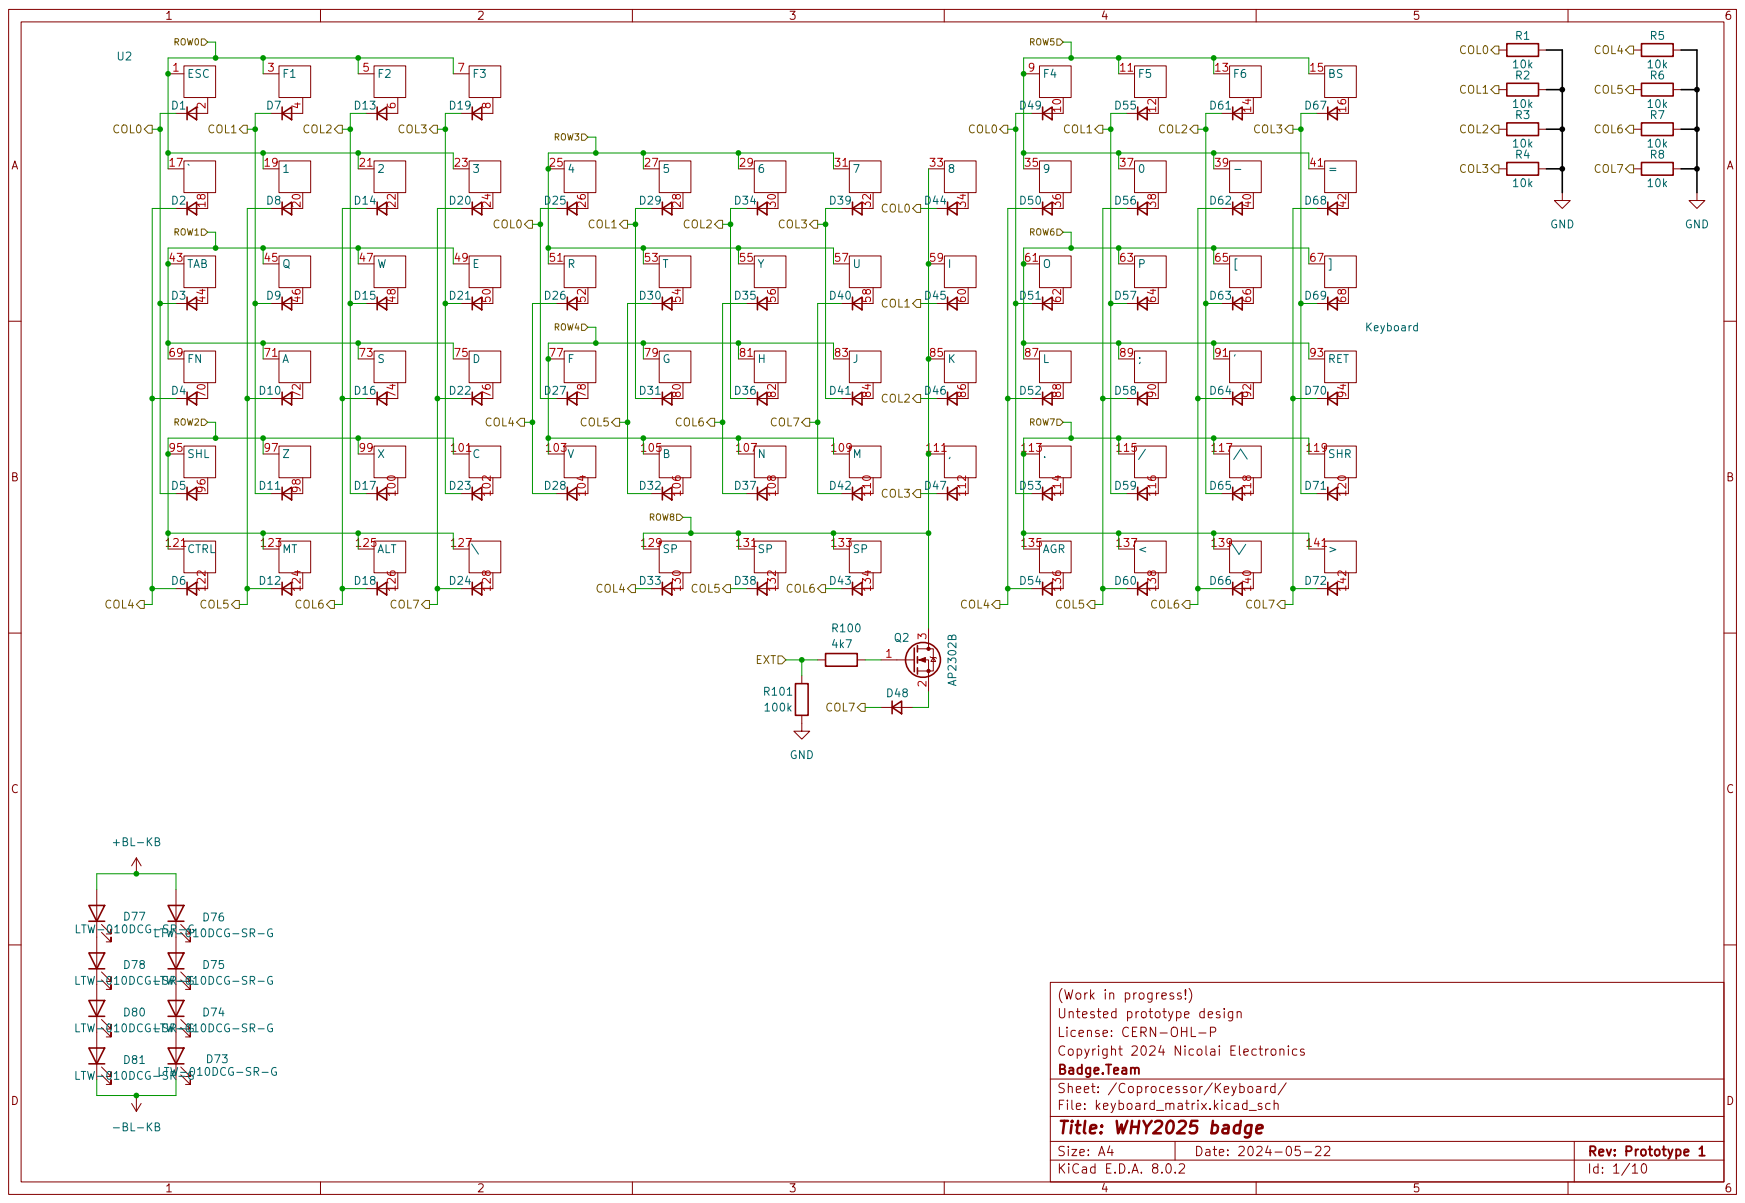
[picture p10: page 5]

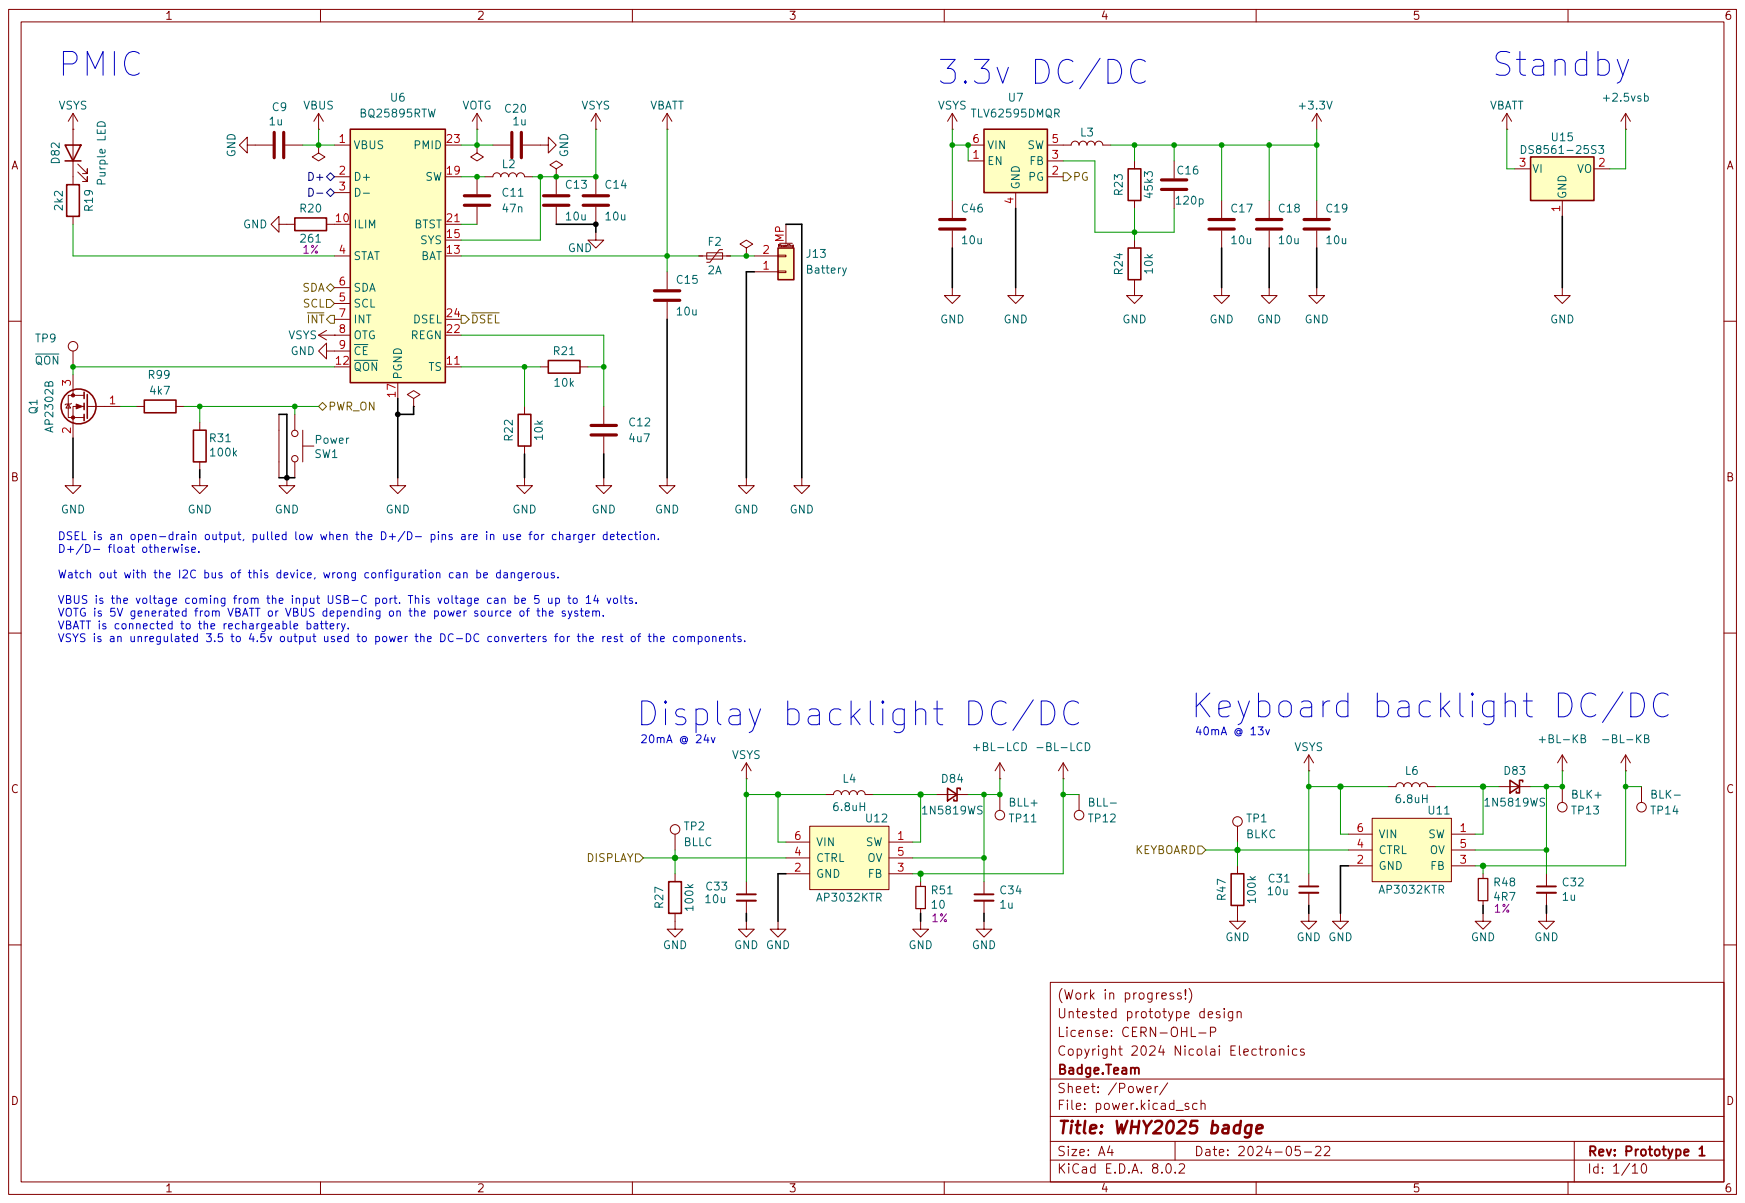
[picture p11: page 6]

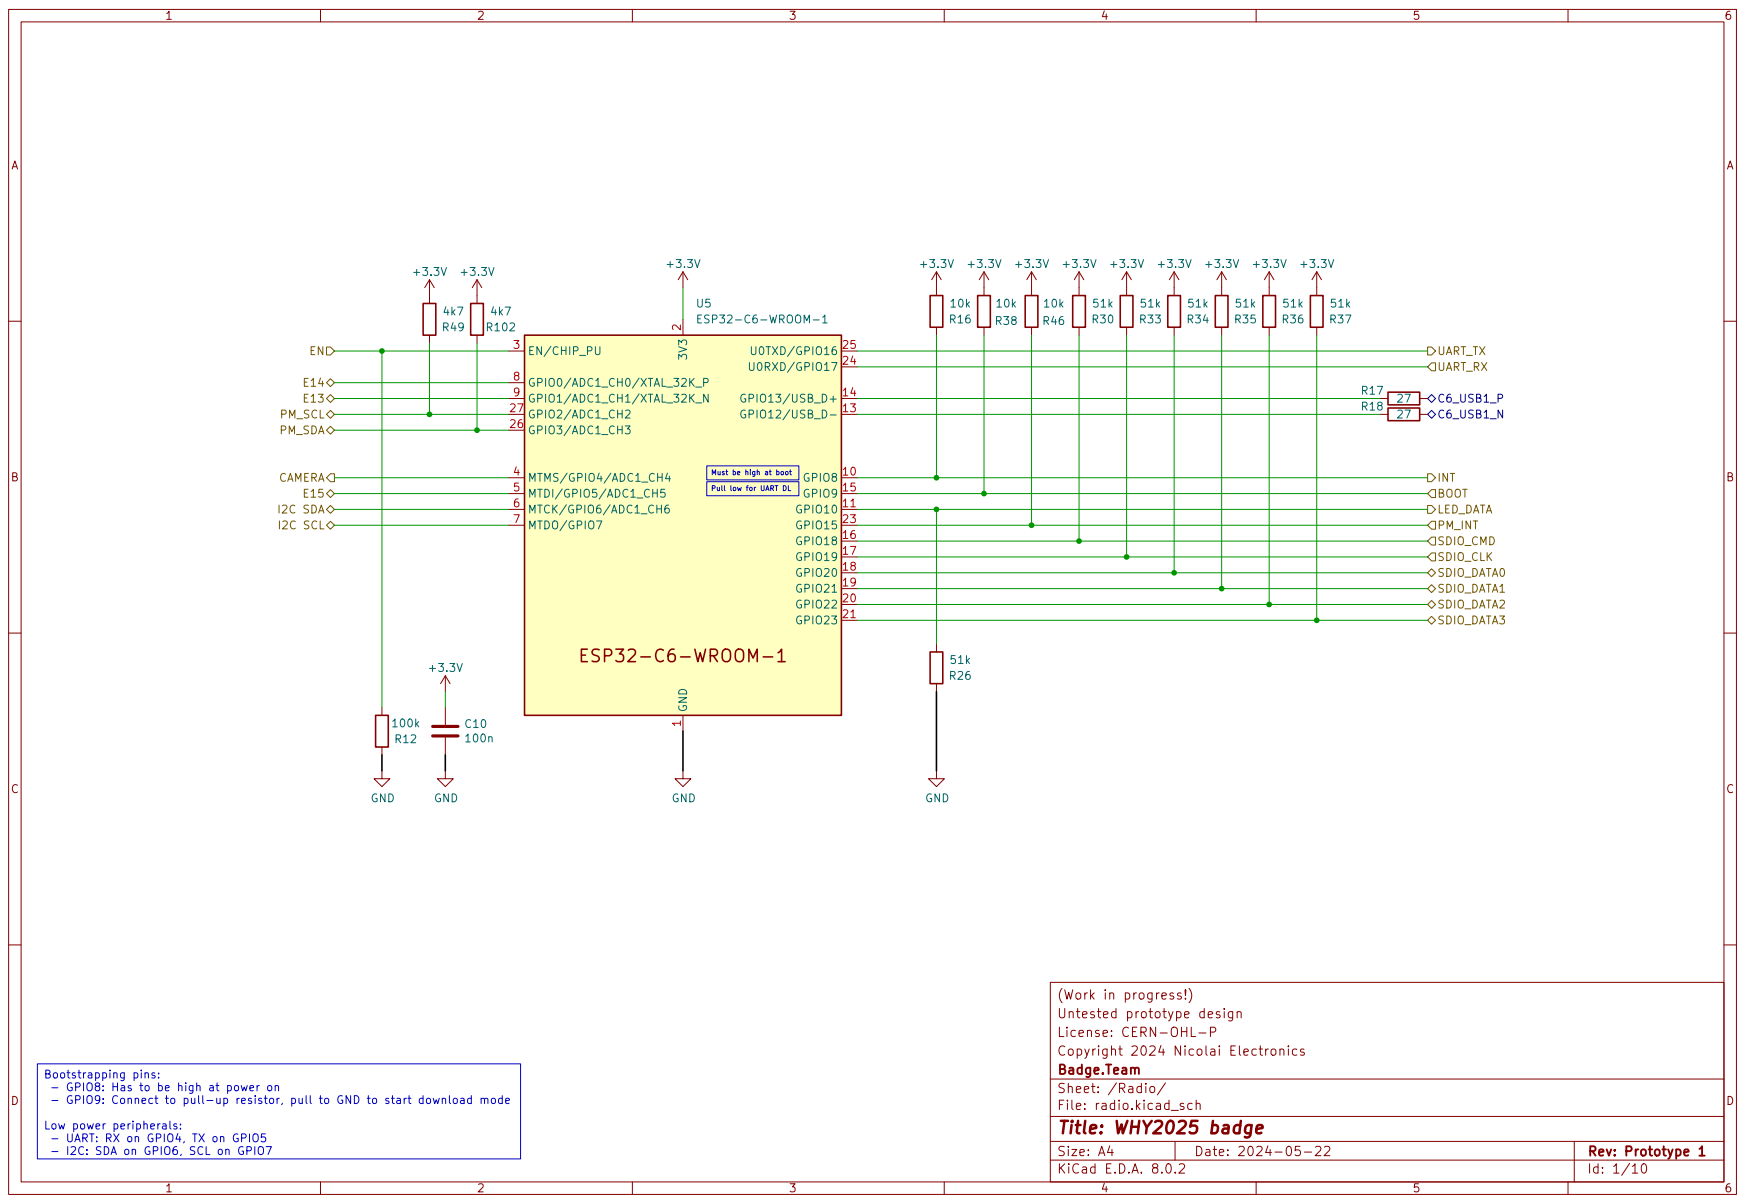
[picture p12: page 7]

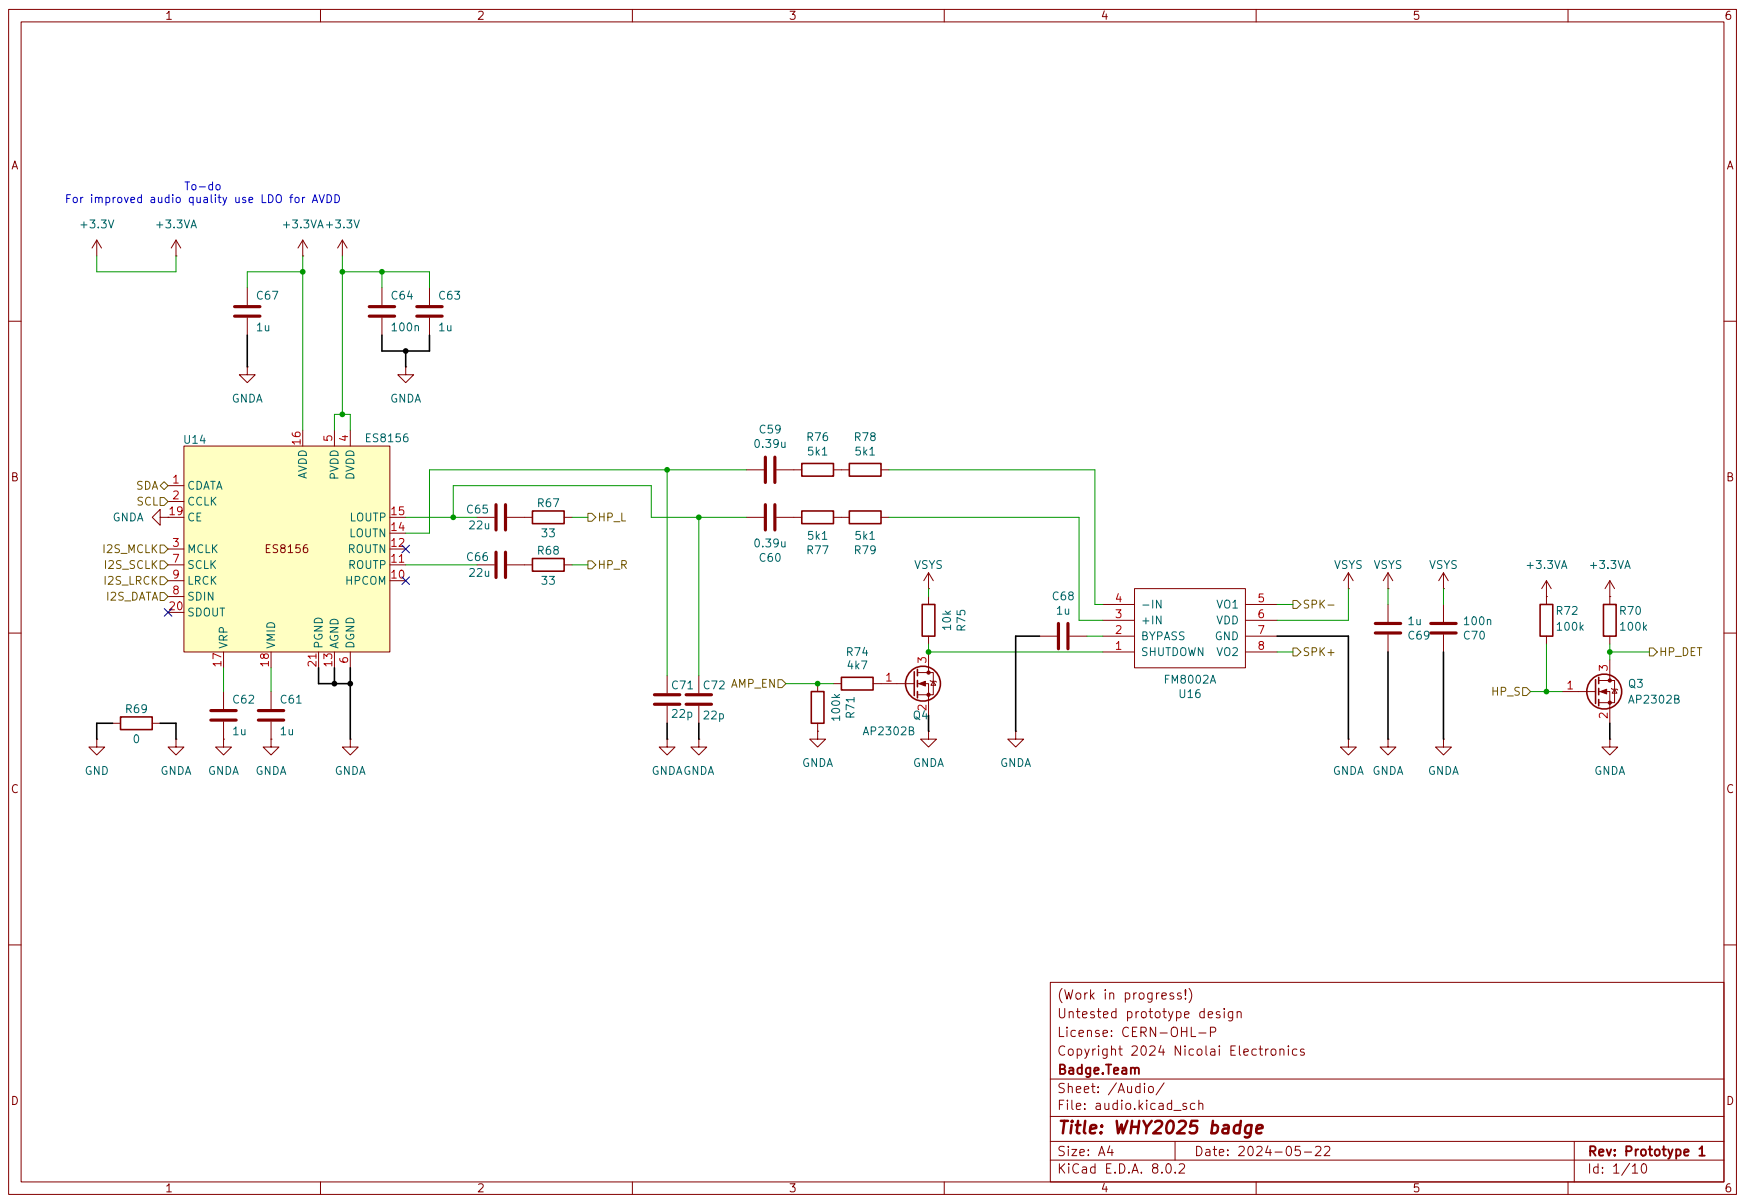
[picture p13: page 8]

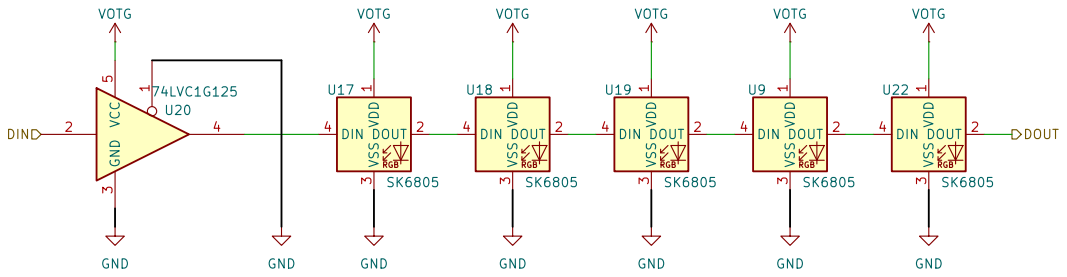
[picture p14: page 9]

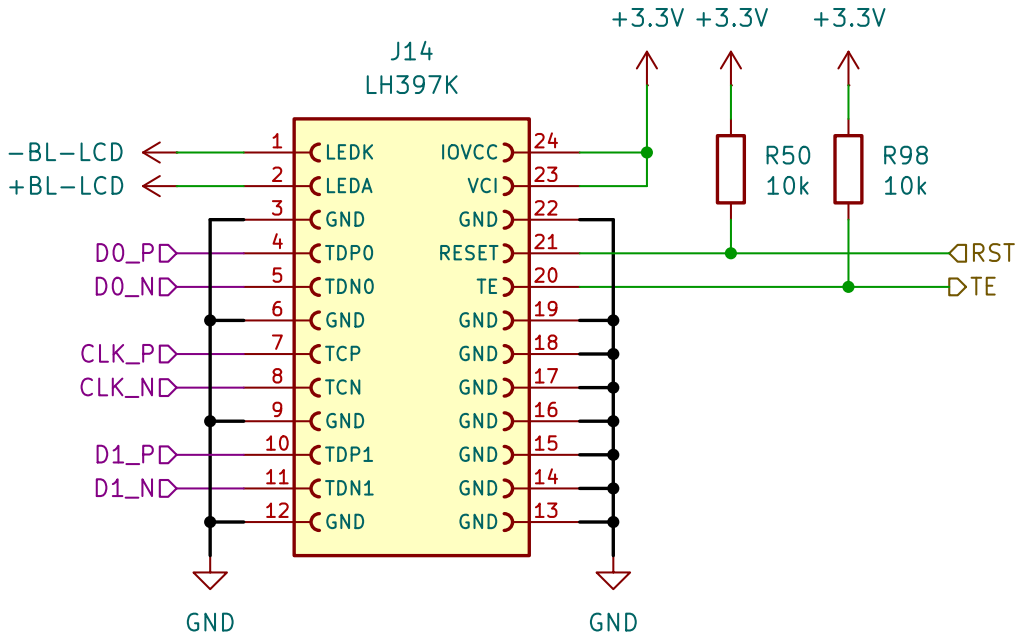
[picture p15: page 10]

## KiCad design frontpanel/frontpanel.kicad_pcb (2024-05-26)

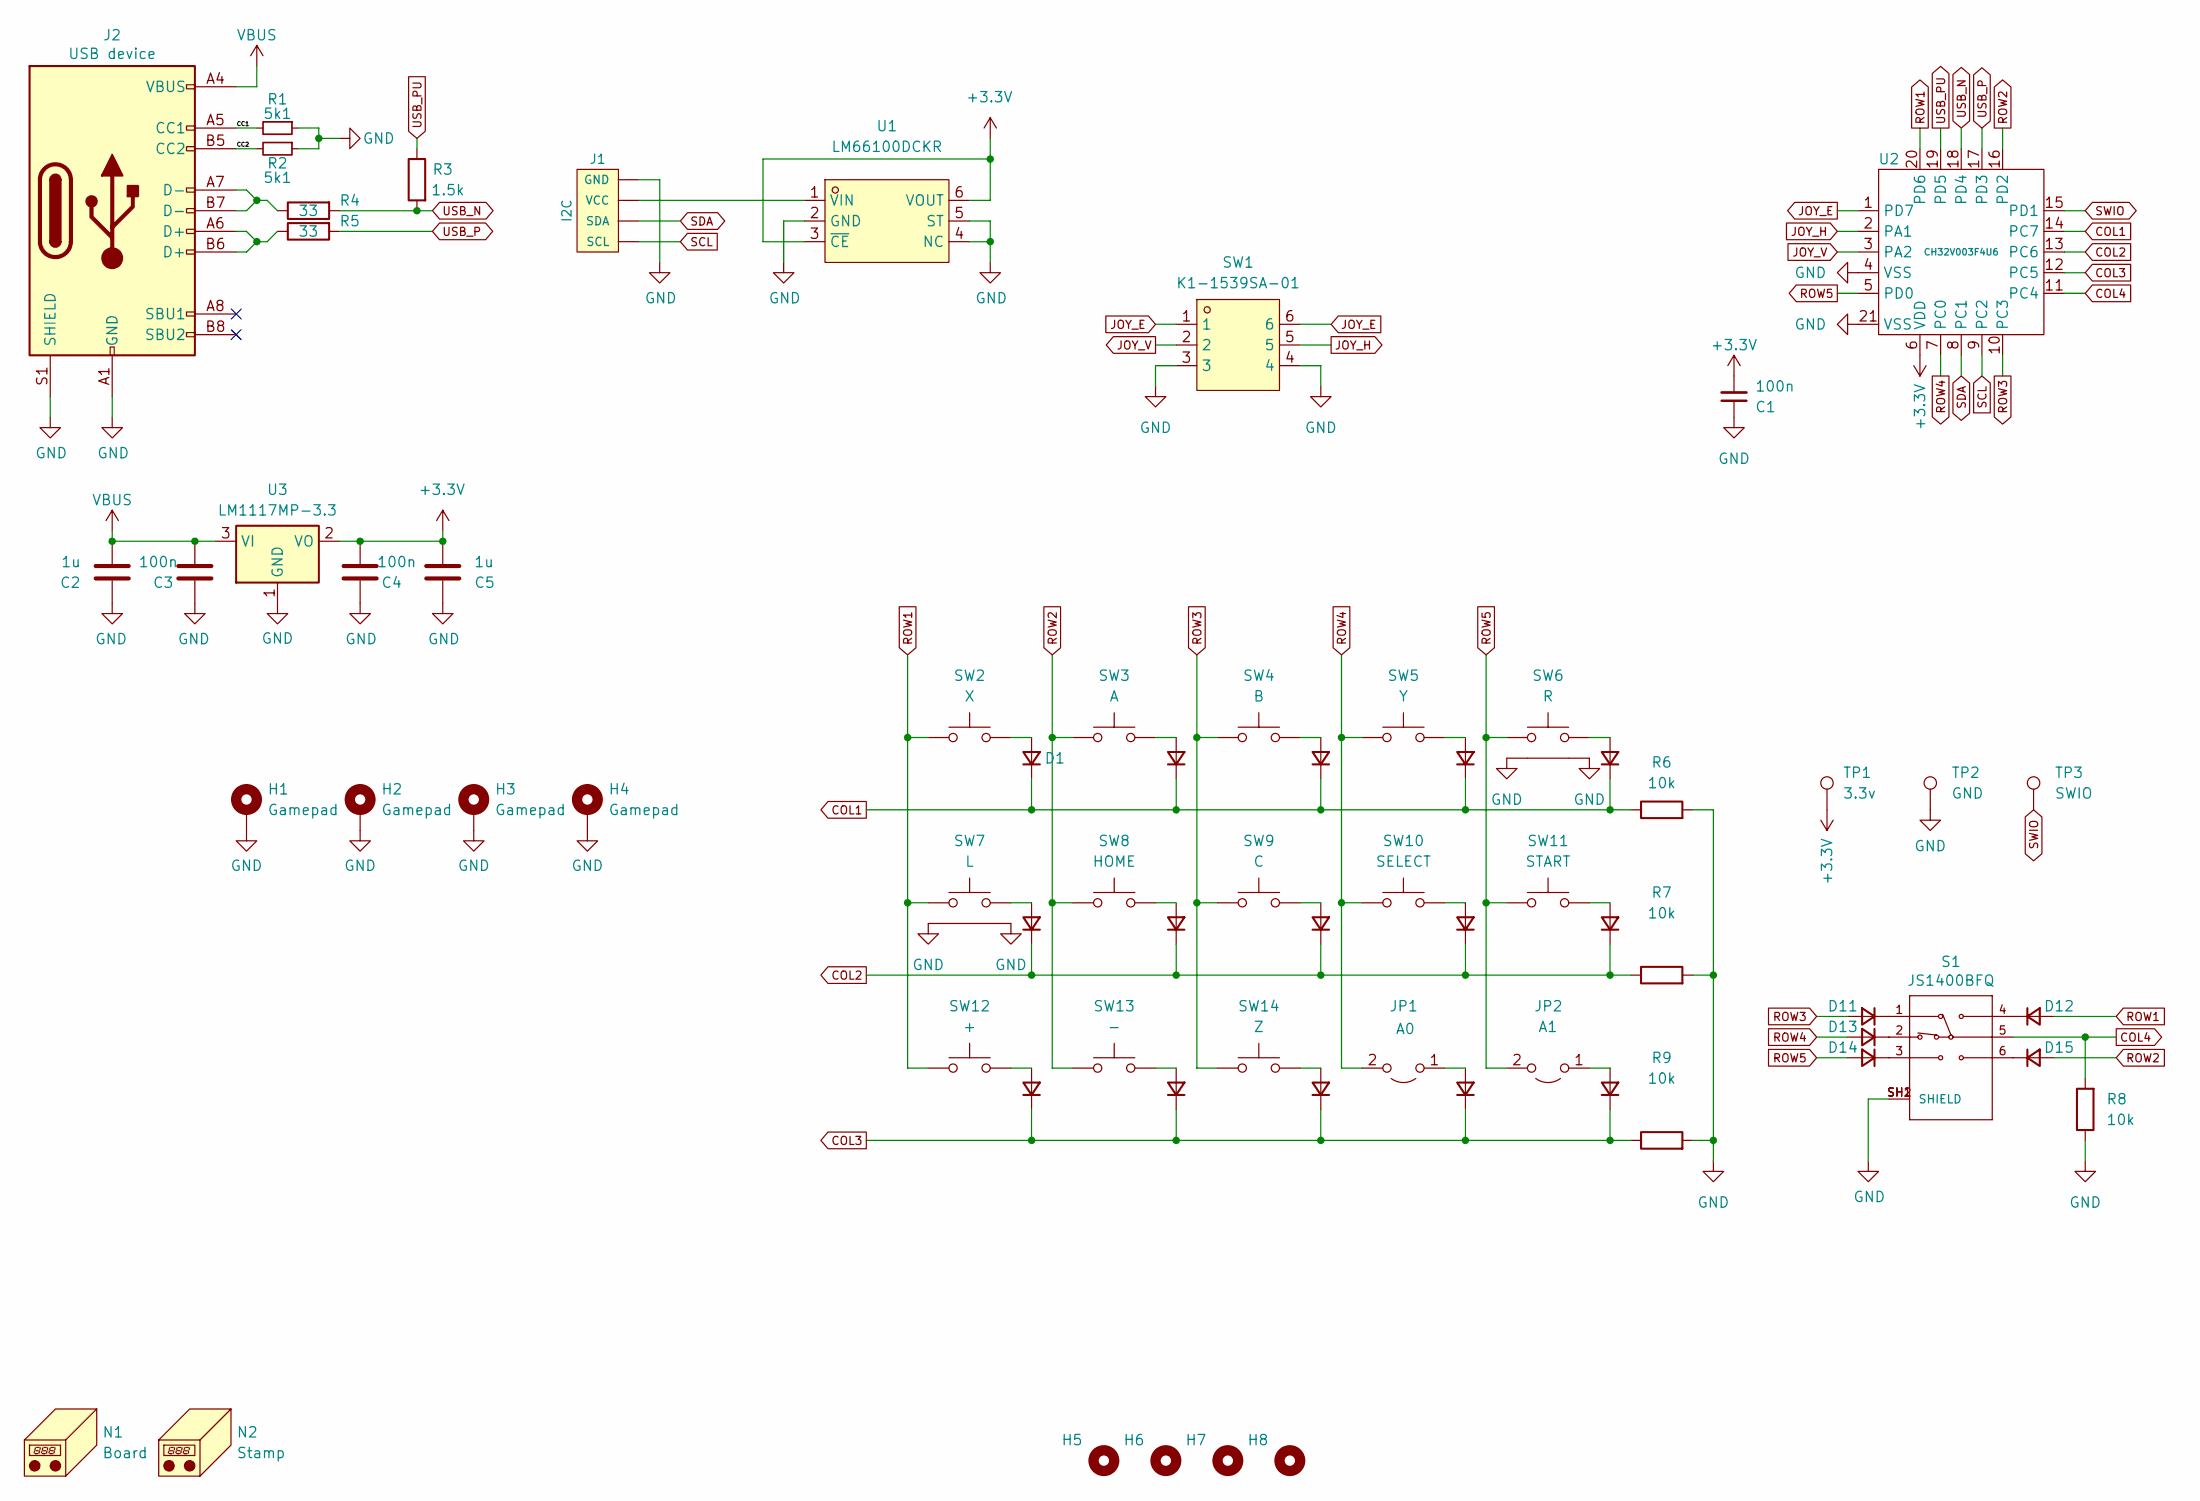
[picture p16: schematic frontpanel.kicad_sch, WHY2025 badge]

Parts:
C1, C3, C4: 100n; C_0402_1005Metric; LCSC C1525
C2, C5: 1u; C_0402_1005Metric; LCSC C88945
D1, D2, D3, D4, D5, D6, D7, D8, D9, D10, D11, D12, D13, D14, D15, D16, D17, D18, D19, D20: LL4148; D_SOD-323; LCSC C2843305
H1, H2, H3, H4: Gamepad; mountinghole_1.6mm
H5, H6, H7, H8: Mounting hole; MountingHole_2.1mm
J1: I2C; 1X04_1MM_RA_GND; LCSC C160404
J2: USB device; USB_C_Receptacle_HRO_TYPE-C-31-M-12; LCSC C165948
JP1: A0; SolderJumper-2_P1.3mm_Open_TrianglePad1.0x1.5mm
JP2: A1; SolderJumper-2_P1.3mm_Open_TrianglePad1.0x1.5mm
N1: Board; proto1_kicad_frontpanel
N2: Stamp; stamp
R1, R2: 5k1; R_0402_1005Metric; LCSC C25905
R3: 1.5k; R_0402_1005Metric; LCSC C25867
R4, R5: 33; R_0402_1005Metric; LCSC C25105
R6, R7, R8, R9: 10k; R_0402_1005Metric; LCSC C60490
S1: JS1400BFQ; SW_JS1400BFQ; LCSC C139794
SW1: K1-1539SA-01; SW-SMD_K1-1539SA-01; LCSC C128932
SW2: X; KEY-SMD_2P-L6.0-W6.0-P6.00; LCSC C115348
SW3: A; KEY-SMD_2P-L6.0-W6.0-P6.00; LCSC C115348
SW4: B; KEY-SMD_2P-L6.0-W6.0-P6.00; LCSC C115348
SW5: Y; KEY-SMD_2P-L6.0-W6.0-P6.00; LCSC C115348
SW6: R; KEY-TH_TC-1101V-C-A-W; LCSC C318992
SW7: L; KEY-TH_TC-1101V-C-A-W; LCSC C318992
SW8: HOME; KEY-SMD_2P-L6.0-W6.0-P6.00; LCSC C115348
SW9: C; KEY-SMD_2P-L6.0-W6.0-P6.00; LCSC C115348
SW10: SELECT; KEY-SMD_2P-L6.0-W6.0-P6.00; LCSC C115348
SW11: START; KEY-SMD_2P-L6.0-W6.0-P6.00; LCSC C115348
SW12: +; KEY-SMD_2P-L6.0-W6.0-P6.00; LCSC C115348
SW13: -; KEY-SMD_2P-L6.0-W6.0-P6.00; LCSC C115348
SW14: Z; KEY-SMD_2P-L6.0-W6.0-P6.00; LCSC C115348
TP1: 3.3v; TestPoint_Pad_D1.5mm
TP2: GND; TestPoint_Pad_D1.5mm
TP3: SWIO; TestPoint_Pad_D1.5mm
U1: LM66100DCKR; SC-70-6_L2.0-W1.3-P0.65-LS2.1-BL; LCSC Part C2869734
U2: CH32V003F4U6; QFN-20-1EP_3x3mm_P0.4mm_EP1.65x1.65mm; LCSC C5299908
U3: LM1117MP-3.3; SOT-223-3_TabPin2; LCSC C498153

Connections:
+3.3V: C1.2, C4.1, C5.1, TP1.1, U1.3 (~CE), U1.6 (VOUT), U2.6 (VDD), U3.2 (VO)
/CC1: J2.A5 (CC1), R1.2
/CC2: J2.B5 (CC2), R2.2
COL1: D1.1 (K), D2.1 (K), D3.1 (K), D4.1 (K), D5.1 (K), R6.1, U2.14 (PC7)
COL2: D6.1 (K), D7.1 (K), D8.1 (K), D9.1 (K), D10.1 (K), R7.1, U2.13 (PC6)
COL3: D16.1 (K), D17.1 (K), D18.1 (K), D19.1 (K), D20.1 (K), R9.1, U2.12 (PC5)
COL4: R8.2, S1.5, U2.11 (PC4)
GND: C1.1, C2.2, C3.2, C4.2, C5.2, H1.1, H2.1, H3.1, H4.1, J1.1 (GND), J1.5, J1.6, J2.A1 (GND), J2.A12 (GND), J2.B1 (GND), J2.B12 (GND), J2.S1 (SHIELD), R1.1, R2.1, R6.2, R7.2, R8.1, R9.2, S1.SH1 (SHIELD), S1.SH2 (SHIELD), SW1.3, SW1.4, SW6.3, SW6.4, SW7.3, SW7.4, TP2.1, U1.2 (GND), U1.4 (NC), U1.5 (ST), U2.4 (VSS), U2.21 (VSS), U3.1 (GND)
JOY_E: SW1.1, SW1.6, U2.1 (PD7)
JOY_H: SW1.5, U2.2 (PA1)
JOY_V: SW1.2, U2.3 (PA2)
unnamed: D1.2 (A), SW2.2
unnamed: D2.2 (A), SW3.2
unnamed: D3.2 (A), SW4.2
unnamed: D4.2 (A), SW5.2
unnamed: D5.2 (A), SW6.2
unnamed: D6.2 (A), SW7.2
unnamed: D7.2 (A), SW8.2
unnamed: D8.2 (A), SW9.2
unnamed: D9.2 (A), SW10.2
unnamed: D10.2 (A), SW11.2
unnamed: D11.1 (K), S1.1
unnamed: D12.1 (K), S1.4
unnamed: D13.1 (K), S1.2
unnamed: D14.1 (K), S1.3
unnamed: D15.1 (K), S1.6
unnamed: D16.2 (A), SW12.2
unnamed: D17.2 (A), SW13.2
unnamed: D18.2 (A), SW14.2
unnamed: D19.2 (A), JP1.1 (A)
unnamed: D20.2 (A), JP2.1 (A)
unnamed: J1.2 (VCC), U1.1 (VIN)
unnamed: J2.A6 (D+), J2.B6 (D+), R5.1
unnamed: J2.A7 (D-), J2.B7 (D-), R4.1
ROW1: D12.2 (A), SW2.1, SW7.1, SW12.1, U2.20 (PD6)
ROW2: D15.2 (A), SW3.1, SW8.1, SW13.1, U2.16 (PD2)
ROW3: D11.2 (A), SW4.1, SW9.1, SW14.1, U2.10 (PC3)
ROW4: D13.2 (A), JP1.2 (B), SW5.1, SW10.1, U2.7 (PC0)
ROW5: D14.2 (A), JP2.2 (B), SW6.1, SW11.1, U2.5 (PD0)
SCL: J1.4 (SCL), U2.9 (PC2)
SDA: J1.3 (SDA), U2.8 (PC1)
SWIO: TP3.1, U2.15 (PD1)
USB_N: R3.2, R4.2, U2.18 (PD4)
USB_P: R5.2, U2.17 (PD3)
USB_PU: R3.1, U2.19 (PD5)
VBUS: C2.1, C3.1, J2.A4 (VBUS), J2.A9 (VBUS), J2.B4 (VBUS), J2.B9 (VBUS), U3.3 (VI)

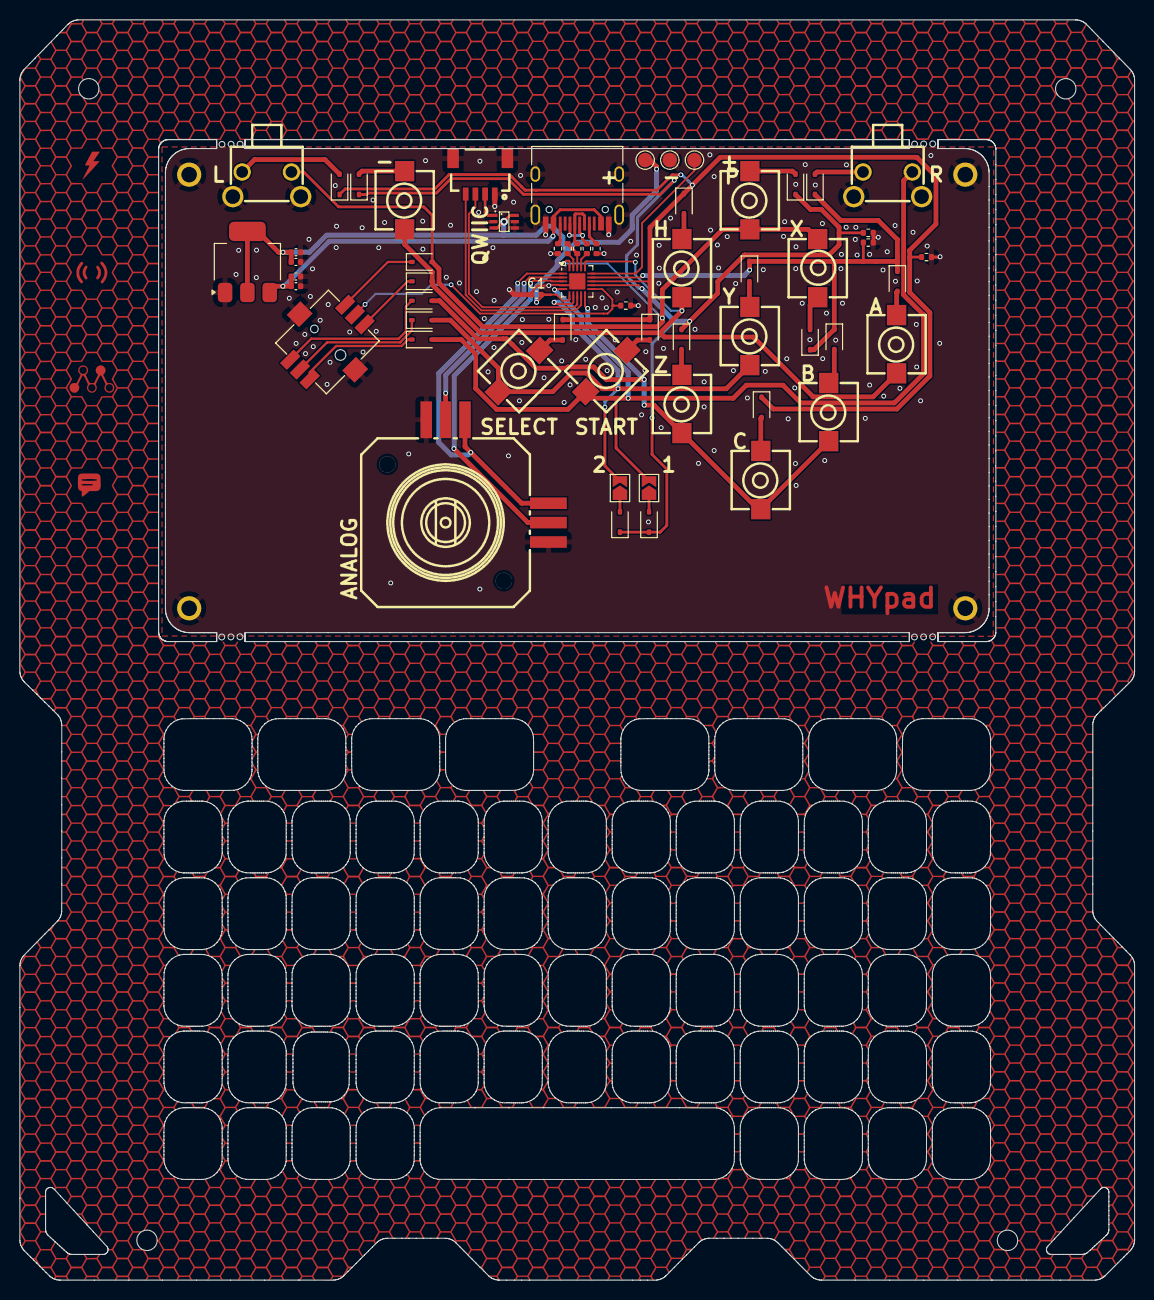
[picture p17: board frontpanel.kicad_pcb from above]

Board: 2 copper layers, 114.9 x 129.9 mm, 69 parts (1 on the bottom side), 46 nets.

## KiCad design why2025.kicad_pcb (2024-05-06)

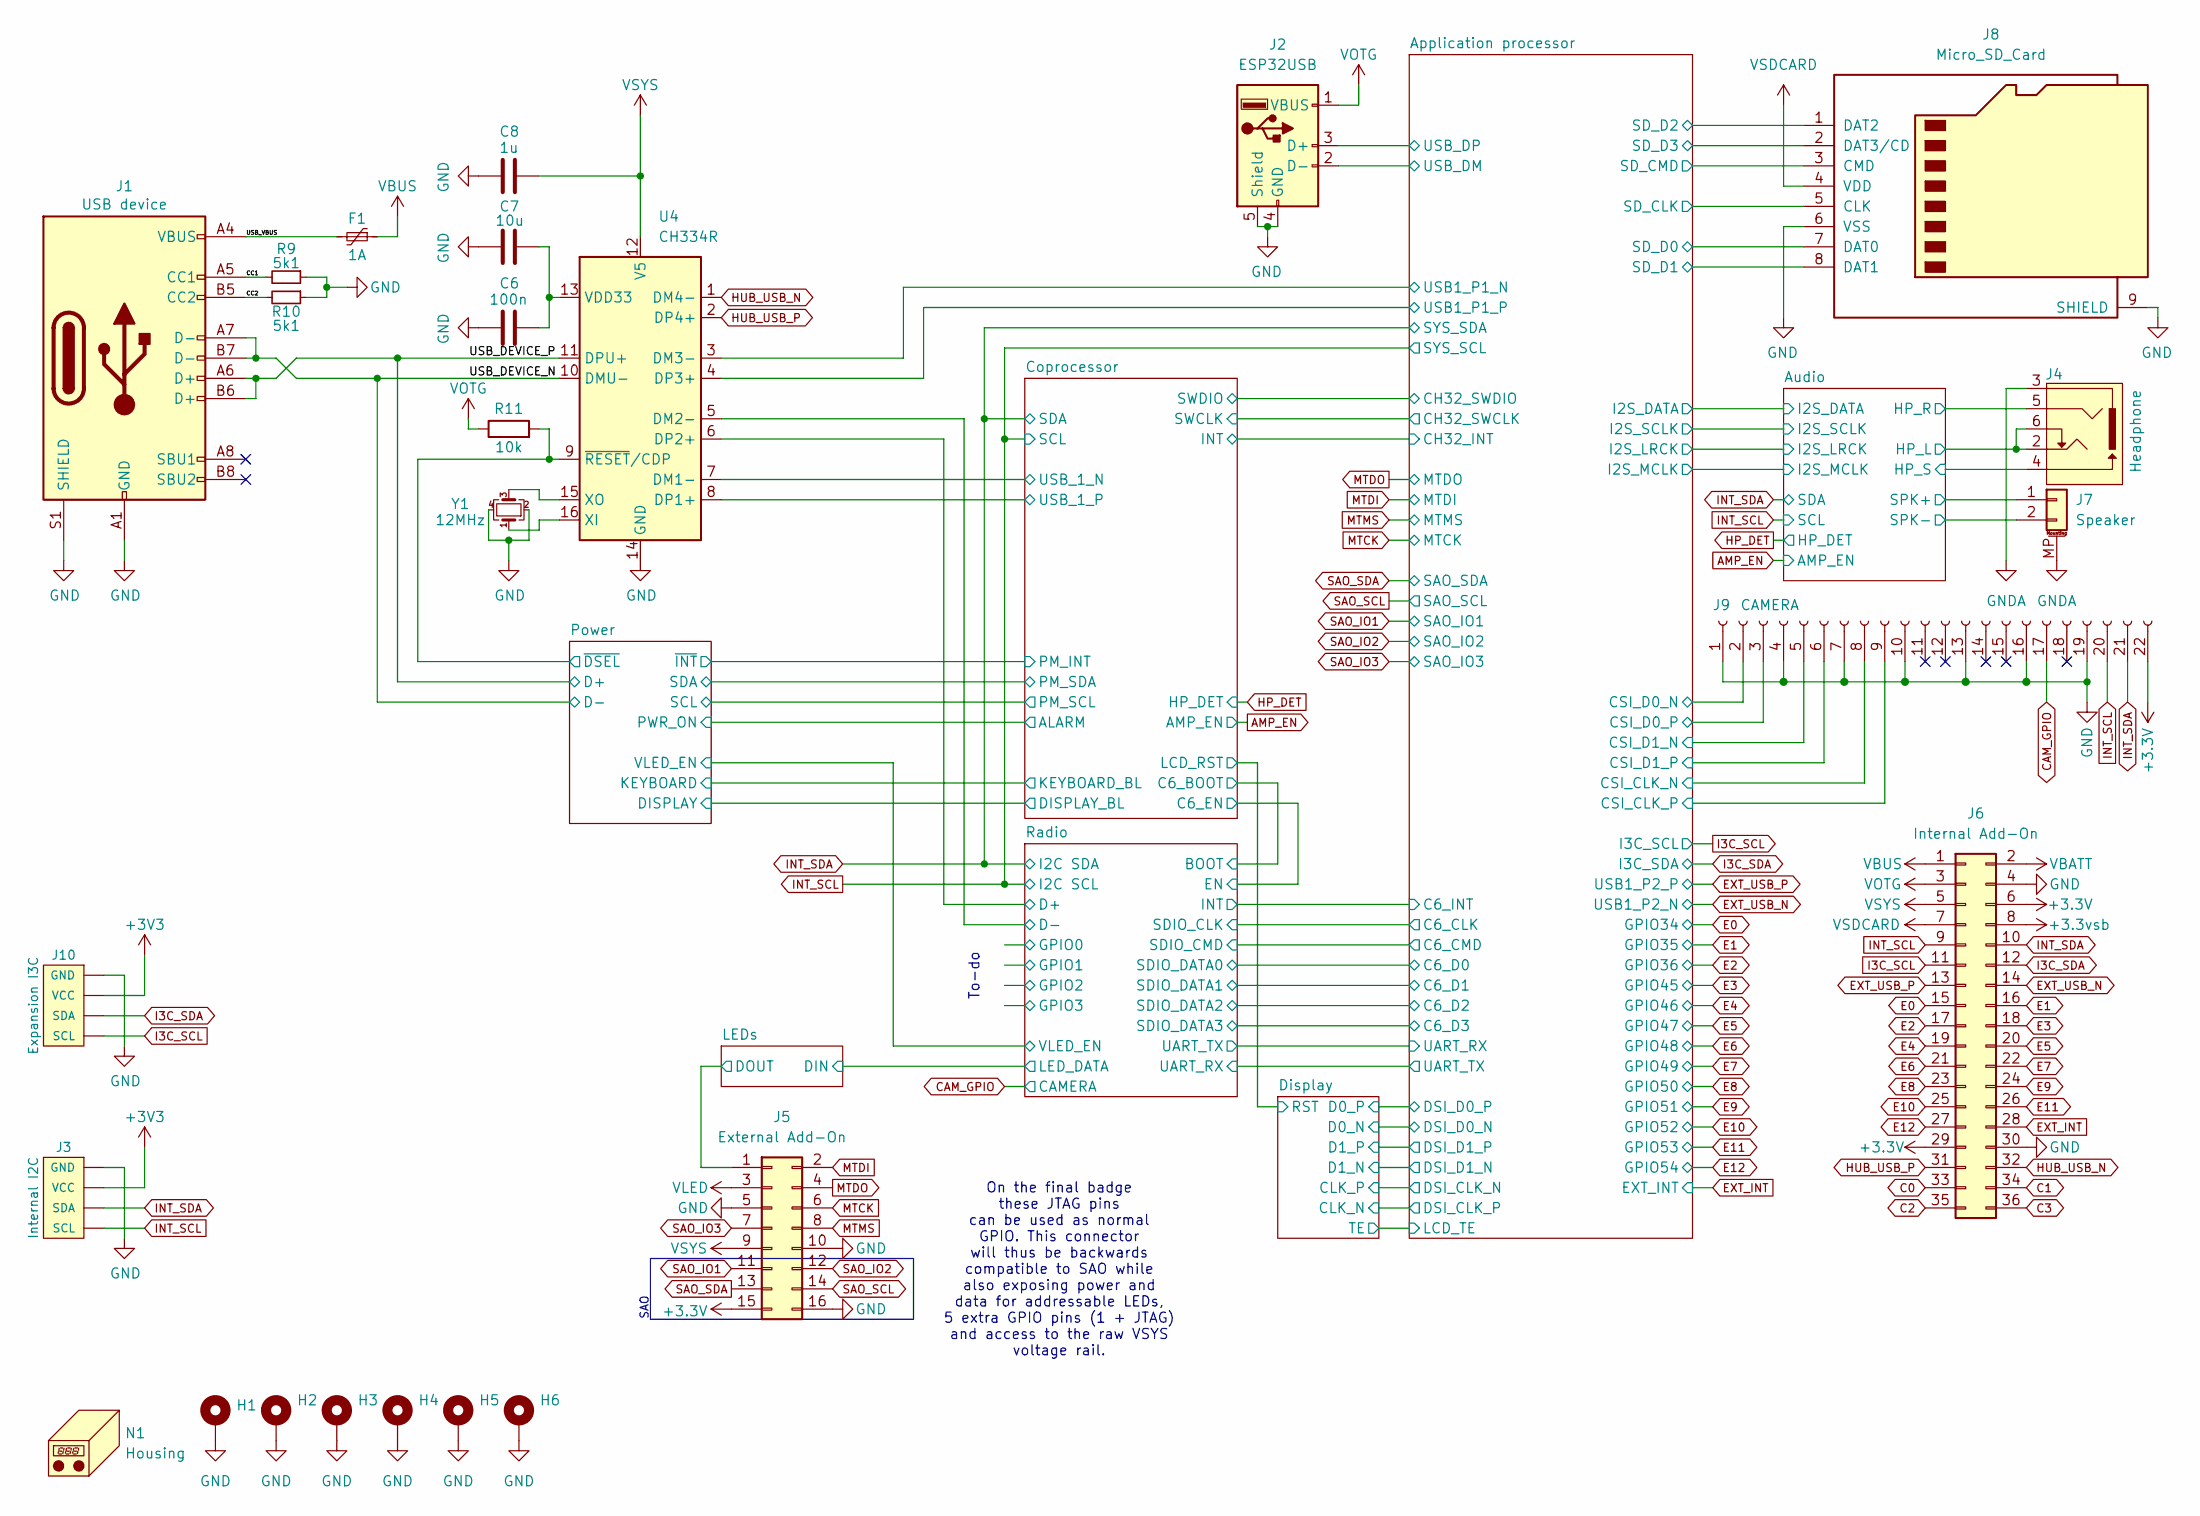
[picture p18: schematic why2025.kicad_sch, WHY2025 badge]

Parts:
C6: 100n; C_0402_1005Metric; Minimal voltage rating 10; Voltage rating 50; LCSC C307331
C7: 10u; C_1206_3216Metric
C8: 1u; C_0603_1608Metric
F1: 1A; Fuse_0805_2012Metric; LCSC C269107
H1, H2, H3, H4, H5, H6: MountingHole_2.2mm_M2_Pad_Via; LCSC C2928171
J1: USB device; USB_C_Receptacle_HRO_TYPE-C-31-M-12; LCSC C165948
J2: ESP32USB; USB-A-TH_JTJ-USB-A-F-10.0-010
J3: Internal I2C; 1X04_1MM_RA_GND; LCSC C160404
J4: Headphone
J5: External Add-On; PinSocket_2x08_P2.54mm_Horizontal
J6: Internal Add-On; PinSocket_2x18_P2.54mm_Vertical_SMD
J7: Speaker; Molex_PicoBlade_53261-0271_1x02-1MP_P1.25mm_Horizontal; LCSC C189700
J8: Micro_SD_Card; SD_Card-micro_socket_A
J9: CAMERA; Hirose_FH12-22S-0.5SH_1x22-1MP_P0.50mm_Horizontal; Part Description 22 Position FFC, FPC Connector Contacts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
J10: Expansion I3C; 1X04_1MM_RA_GND; LCSC C160404
N1: Housing; proto1_kicad
R9, R10: 5k1; R_0402_1005Metric; LCSC C25905
R11: 10k; R_0402_1005Metric
U4: CH334R; QSOP-16_3.9x4.9mm_P0.635mm; LCSC C4154405
Y1: 12MHz; Crystal_SMD_3225-4Pin_3.2x2.5mm; LCSC C133337

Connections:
+3.3V: J5.15, J6.6, J6.29, J9.22; also elsewhere on the board
+3.3vsb: J6.8
+3V3: J3.2 (VCC), J10.2 (VCC)
/Application processor/SD_CLK: J8.5 (CLK); also elsewhere on the board
/Application processor/SD_CMD: J8.3 (CMD); also elsewhere on the board
/Application processor/SD_D0: J8.7 (DAT0); also elsewhere on the board
/Application processor/SD_D1: J8.8 (DAT1); also elsewhere on the board
/Application processor/SD_D2: J8.1 (DAT2); also elsewhere on the board
/Application processor/SD_D3: J8.2 (DAT3/CD); also elsewhere on the board
/Application processor/USB1_P1_N: U4.3 (DM3-); also elsewhere on the board
/Application processor/USB1_P1_P: U4.4 (DP3+); also elsewhere on the board
/Application processor/USB_DM: J2.2 (D-); also elsewhere on the board
/Application processor/USB_DP: J2.3 (D+); also elsewhere on the board
/Audio/SPK+: J7.1; also elsewhere on the board
/Audio/SPK-: J7.2; also elsewhere on the board
/CC1: J1.A5 (CC1), R9.2
/CC2: J1.B5 (CC2), R10.2
/Coprocessor/USB_1_N: U4.7 (DM1-); also elsewhere on the board
/Coprocessor/USB_1_P: U4.8 (DP1+); also elsewhere on the board
/LEDs/DOUT: J5.1
/Power/~DSEL: R11.2, U4.9 (~RESET/CDP); also elsewhere on the board
/Radio/D+: U4.6 (DP2+); also elsewhere on the board
/Radio/D-: U4.5 (DM2-); also elsewhere on the board
/USB_DEVICE_N: J1.A7 (D-), J1.B7 (D-), U4.10 (DMU-); also elsewhere on the board
/USB_DEVICE_P: J1.A6 (D+), J1.B6 (D+), U4.11 (DPU+); also elsewhere on the board
/USB_VBUS: F1.2, J1.A4 (VBUS), J1.A9 (VBUS), J1.B4 (VBUS), J1.B9 (VBUS)
C0: J6.33
C1: J6.34
C2: J6.35
C3: J6.36
E0: J6.15; also elsewhere on the board
E1: J6.16; also elsewhere on the board
E2: J6.17; also elsewhere on the board
E3: J6.18; also elsewhere on the board
E4: J6.19; also elsewhere on the board
E5: J6.20; also elsewhere on the board
E6: J6.21; also elsewhere on the board
E7: J6.22; also elsewhere on the board
E8: J6.23; also elsewhere on the board
E11: J3.4 (SCL), J6.9, J6.26, J9.20; also elsewhere on the board
E12: J6.27; also elsewhere on the board
EXT_INT: J6.24, J6.28; also elsewhere on the board
EXT_USB_N: J6.14; also elsewhere on the board
EXT_USB_P: J6.13; also elsewhere on the board
GND: C6.2, C7.2, C8.2, H1.1, H2.1, H3.1, H4.1, H5.1, H6.1, J1.A1 (GND), J1.A12 (GND), J1.B1 (GND), J1.B12 (GND), J1.S1 (SHIELD), J2.4 (GND), J2.5 (Shield), J3.1 (GND), J3.5, J3.6, J5.5, J5.10, J5.16, J6.4, J6.30, J8.6 (VSS), J8.9 (SHIELD), J9.1, J9.4, J9.7, J9.10, J9.13, J9.16, J9.19, J10.1 (GND), J10.5, J10.6, R9.1, R10.1, U4.14 (GND), Y1.2, Y1.4; also elsewhere on the board
GNDA: J4.3, J7.MP (MountPin); also elsewhere on the board
HUB_USB_N: J6.32, U4.1 (DM4-)
HUB_USB_P: J6.31, U4.2 (DP4+)
I3C_SCL: J6.11, J10.4 (SCL); also elsewhere on the board
I3C_SDA: J6.12, J10.3 (SDA); also elsewhere on the board
INT_SDA: J3.3 (SDA), J6.10, J6.25, J9.21; also elsewhere on the board
MTCK: J5.6; also elsewhere on the board
MTDI: J5.2; also elsewhere on the board
MTDO: J5.4; also elsewhere on the board
MTMS: J5.8; also elsewhere on the board
unnamed: J4.2, J4.6
unnamed: C6.1, C7.1, U4.13 (VDD33)
unnamed: U4.16 (XI), Y1.1
unnamed: U4.15 (XO), Y1.3
SAO_IO1: J5.11; also elsewhere on the board
SAO_IO2: J5.12; also elsewhere on the board
SAO_IO3: J5.7; also elsewhere on the board
SAO_SCL: J5.14; also elsewhere on the board
SAO_SDA: J5.13; also elsewhere on the board
VBATT: J6.2; also elsewhere on the board
VBUS: F1.1, J6.1; also elsewhere on the board
VLED: J5.3; also elsewhere on the board
VOTG: J2.1 (VBUS), J6.3, R11.1; also elsewhere on the board
VSDCARD: J6.7, J8.4 (VDD); also elsewhere on the board
VSYS: C8.1, J5.9, J6.5, U4.12 (V5); also elsewhere on the board

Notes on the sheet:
On the final badge these JTAG pins can be used as normal GPIO. This connector will thus be backwards compatible to SAO while also exposing power and data for addressable LEDs, 5 extra GPIO pins (1 + JTAG) and access to the raw VSYS voltage rail.
SAO
To-do

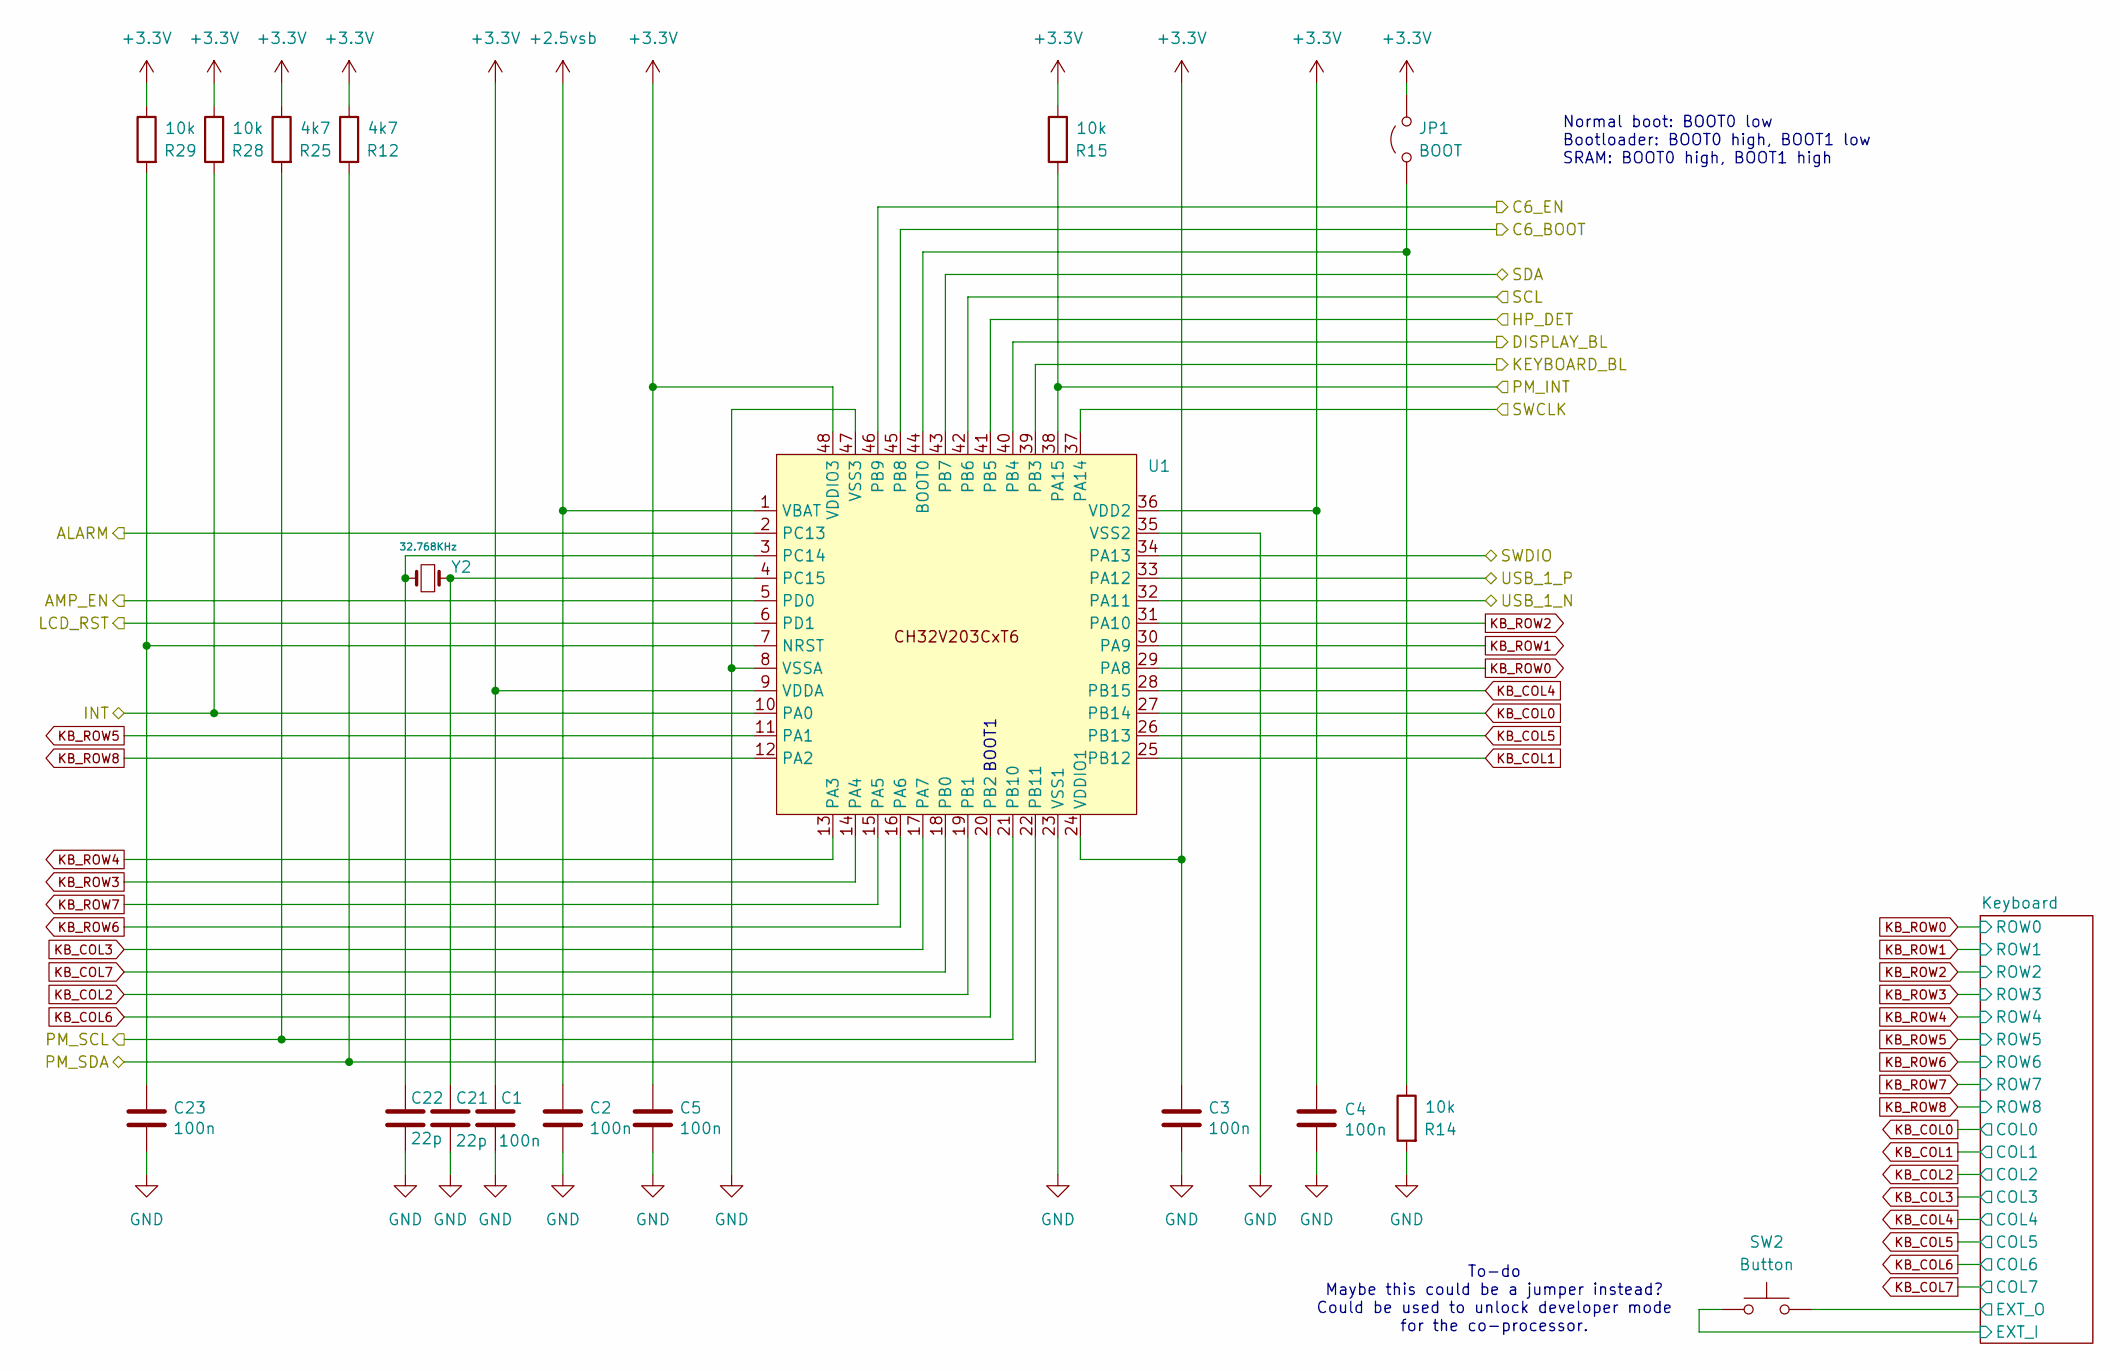
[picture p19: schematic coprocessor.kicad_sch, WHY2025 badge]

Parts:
C1, C2, C3, C4, C5, C23: 100n; C_0402_1005Metric; LCSC C307331
C21, C22: 22p; C_0402_1005Metric
JP1: BOOT; SolderJumper-2_P1.3mm_Open_RoundedPad1.0x1.5mm
R12, R25: 4k7; R_0402_1005Metric
R14, R15, R28, R29: 10k; R_0402_1005Metric; LCSC C25744
SW2: Button; SW_SPST_PTS645
U1: LQFP-48_7x7mm_P0.5mm
Y2: 32.768KHz; Crystal_SMD_3215-2Pin_3.2x1.5mm; LCSC C95361

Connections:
+2.5vsb: C2.1, U1.1 (VBAT); also elsewhere on the board
+3.3V: C1.1, C3.1, C4.1, C5.1, JP1.2 (B), R12.1, R15.1, R25.1, R28.1, R29.1, U1.9 (VDDA), U1.24 (VDDIO1), U1.36 (VDD2), U1.48 (VDDIO3); also elsewhere on the board
/Application processor/CH32_SWCLK: U1.37 (PA14); also elsewhere on the board
/Application processor/CH32_SWDIO: U1.34 (PA13); also elsewhere on the board
/Coprocessor/ALARM: U1.2 (PC13); also elsewhere on the board
/Coprocessor/C6_BOOT: U1.45 (PB8); also elsewhere on the board
/Coprocessor/C6_EN: U1.46 (PB9); also elsewhere on the board
/Coprocessor/DISPLAY_BL: U1.40 (PB4); also elsewhere on the board
/Coprocessor/KEYBOARD_BL: U1.39 (PB3); also elsewhere on the board
/Coprocessor/Keyboard/EXT_I: SW2.1; also elsewhere on the board
/Coprocessor/LCD_RST: U1.6 (PD1); also elsewhere on the board
/Coprocessor/PM_INT: R15.2, U1.38 (PA15); also elsewhere on the board
/Coprocessor/PM_SCL: R25.2, U1.21 (PB10); also elsewhere on the board
/Coprocessor/PM_SDA: R12.2, U1.22 (PB11); also elsewhere on the board
/Coprocessor/USB_1_N: U1.32 (PA11); also elsewhere on the board
/Coprocessor/USB_1_P: U1.33 (PA12); also elsewhere on the board
AMP_EN: U1.5 (PD0)
E7: R28.2, U1.10 (PA0); also elsewhere on the board
E11: U1.42 (PB6); also elsewhere on the board
GND: C1.2, C2.2, C3.2, C4.2, C5.2, C21.2, C22.2, C23.2, R14.2, U1.8 (VSSA), U1.23 (VSS1), U1.35 (VSS2), U1.47 (VSS3); also elsewhere on the board
HP_DET: U1.41 (PB5); also elsewhere on the board
INT_SDA: U1.43 (PB7); also elsewhere on the board
KB_COL0: U1.27 (PB14); also elsewhere on the board
KB_COL1: U1.25 (PB12); also elsewhere on the board
KB_COL2: U1.19 (PB1); also elsewhere on the board
KB_COL3: U1.17 (PA7); also elsewhere on the board
KB_COL4: U1.28 (PB15); also elsewhere on the board
KB_COL5: U1.26 (PB13); also elsewhere on the board
KB_COL6: U1.20 (PB2); also elsewhere on the board
KB_COL7: U1.18 (PB0); also elsewhere on the board
KB_ROW0: U1.29 (PA8); also elsewhere on the board
KB_ROW1: U1.30 (PA9); also elsewhere on the board
KB_ROW2: U1.31 (PA10); also elsewhere on the board
KB_ROW3: U1.14 (PA4); also elsewhere on the board
KB_ROW4: U1.13 (PA3); also elsewhere on the board
KB_ROW5: U1.11 (PA1); also elsewhere on the board
KB_ROW6: U1.16 (PA6); also elsewhere on the board
KB_ROW7: U1.15 (PA5); also elsewhere on the board
KB_ROW8: SW2.2, U1.12 (PA2); also elsewhere on the board
unnamed: JP1.1 (A), R14.1, U1.44 (BOOT0)
unnamed: C23.1, R29.2, U1.7 (NRST)
unnamed: C22.1, U1.3 (PC14), Y2.2
unnamed: C21.1, U1.4 (PC15), Y2.1

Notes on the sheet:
Normal boot: BOOT0 low Bootloader: BOOT0 high, BOOT1 low SRAM: BOOT0 high, BOOT1 high
BOOT1
To-do Maybe this could be a jumper instead? Could be used to unlock developer mode for the co-processor.

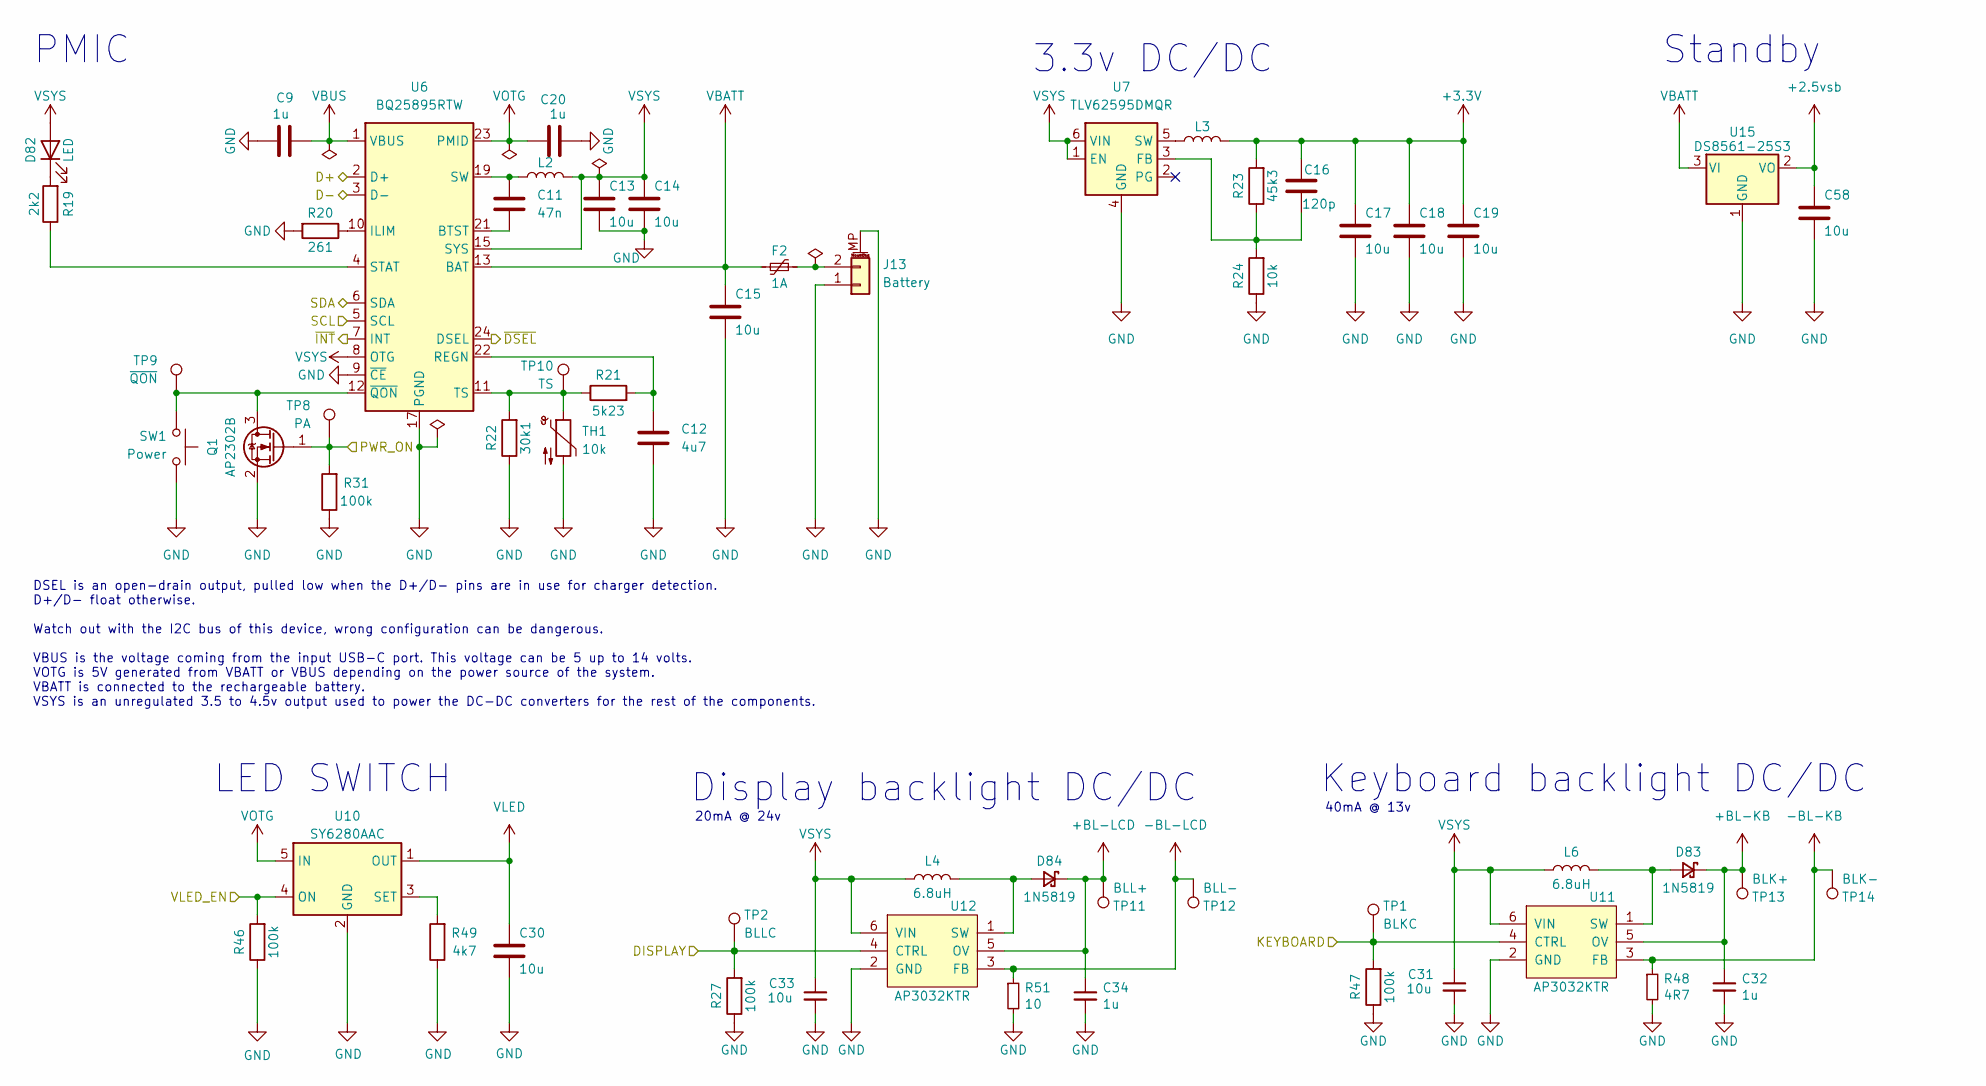
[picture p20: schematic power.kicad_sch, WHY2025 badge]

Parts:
C9, C20, C32, C34: 1u; C_0603_1608Metric
C11: 47n; C_0603_1608Metric
C12: 4u7; C_0603_1608Metric
C13, C14, C15, C17, C18, C19, C30, C31, C33, C58: 10u; C_1206_3216Metric
C16: 120p; C_0603_1608Metric
D82: LED; LED_0603_1608Metric
D83, D84: 1N5819; D_SOD-323; LCSC C369937
F2: 1A; Fuse_0805_2012Metric; LCSC C269107
J13: Battery; JST_S2B-ZR-SM4A-TF(LF)(SN); LCSC C265329
L2: YHNR4020-2R2M; L_Wurth_WE-LQSH-4020
L3: FTC252010SR47MBCA; L_Wurth_WE-LQSH-2512
L4, L6: 6.8uH; L_1008_2520Metric; LCSC C2041474
Q1: AP2302B; SOT-23; LCSC C406812
R19: 2k2; R_0402_1005Metric
R20: 261; R_0402_1005Metric
R21: 5k23; R_0402_1005Metric
R22: 30k1; R_0402_1005Metric
R23: 45k3; R_0402_1005Metric
R24: 10k; R_0402_1005Metric
R27, R46, R47: 100k; R_0402_1005Metric
R31: 100k; R_0402_1005Metric; LCSC C25741
R48: 4R7; R_0402_1005Metric
R49: 4k7; R_0402_1005Metric; LCSC C25900
R51: 10; R_0402_1005Metric
SW1: Power; SW_SPST_PTS645
TH1: 10k; R_0402_1005Metric
TP1: BLKC; TestPoint_Pad_D1.0mm
TP2: BLLC; TestPoint_Pad_D1.0mm
TP8: PA; TestPoint_Pad_D1.0mm
TP9: ~{QON}; TestPoint_Pad_D1.0mm
TP10: TS; TestPoint_Pad_D1.0mm
TP11: BLL+; TestPoint_Pad_D1.0mm
TP12: BLL-; TestPoint_Pad_D1.0mm
TP13: BLK+; TestPoint_Pad_D1.0mm
TP14: BLK-; TestPoint_Pad_D1.0mm
U6: BQ25895RTW; Texas_S-PWQFN-N24_EP2.7x2.7mm_ThermalVias
U7: TLV62595DMQR; Texas_VSON-HR-6_1.5x1.5mm_P0.5mm
U10: SY6280AAC; SOT-23-5; LCSC C55136
U11, U12: AP3032KTR; SOT-23-6; LCSC C264086
U15: DS8561-25S3; SOT-23; LCSC C5795630

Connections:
+2.5vsb: C58.1, U15.2 (VO); also elsewhere on the board
+3.3V: C16.1, C17.1, C18.1, C19.1, L3.2, R23.2; also elsewhere on the board
+BL-KB: C32.1, D83.1 (K), TP13.1, U11.5 (OV); also elsewhere on the board
+BL-LCD: C34.1, D84.1 (K), TP11.1, U12.5 (OV); also elsewhere on the board
-BL-KB: R48.1, TP14.1, U11.3 (FB); also elsewhere on the board
-BL-LCD: R51.1, TP12.1, U12.3 (FB); also elsewhere on the board
/Coprocessor/ALARM: Q1.1 (G), R31.2, TP8.1; also elsewhere on the board
/Coprocessor/DISPLAY_BL: R27.2, TP2.1, U12.4 (CTRL); also elsewhere on the board
/Coprocessor/KEYBOARD_BL: R47.2, TP1.1, U11.4 (CTRL); also elsewhere on the board
/Coprocessor/PM_INT: U6.7 (INT); also elsewhere on the board
/Coprocessor/PM_SCL: U6.5 (SCL); also elsewhere on the board
/Coprocessor/PM_SDA: U6.6 (SDA); also elsewhere on the board
/Power/VLED_EN: R46.2, U10.4 (ON); also elsewhere on the board
/Power/~DSEL: U6.24 (DSEL); also elsewhere on the board
/USB_DEVICE_N: U6.3 (D-); also elsewhere on the board
/USB_DEVICE_P: U6.2 (D+); also elsewhere on the board
GND: C9.2, C12.2, C13.2, C14.2, C15.2, C17.2, C18.2, C19.2, C20.2, C30.2, C31.2, C32.2, C33.2, C34.2, C58.2, J13.1, J13.MP (MountPin), Q1.2 (S), R20.2, R22.1, R24.1, R27.1, R31.1, R46.1, R47.1, R48.2, R49.1, R51.2, SW1.1, TH1.2, U6.9 (~CE), U6.17 (PGND), U6.18 (PGND), U6.25 (PGND), U7.4 (GND), U10.2 (GND), U11.2 (GND), U12.2 (GND), U15.1 (GND); also elsewhere on the board
unnamed: C11.1, L2.1, U6.19 (SW), U6.20 (SW)
unnamed: D82.1 (K), R19.2
unnamed: D83.2 (A), L6.2, U11.1 (SW)
unnamed: D84.2 (A), L4.2, U12.1 (SW)
unnamed: F2.1, J13.2
unnamed: Q1.3 (D), SW1.2, TP9.1, U6.12 (~QON)
unnamed: C11.2, U6.21 (BTST)
unnamed: R20.1, U6.10 (ILIM)
unnamed: C12.1, R21.2, U6.22 (REGN)
unnamed: R19.1, U6.4 (STAT)
unnamed: R21.1, R22.2, TH1.1, TP10.1, U6.11 (TS)
unnamed: C16.2, R23.1, R24.2, U7.3 (FB)
unnamed: L3.1, U7.5 (SW)
unnamed: R49.2, U10.3 (SET)
VBATT: C15.1, F2.2, U6.13 (BAT), U6.14 (BAT), U15.3 (VI); also elsewhere on the board
VBUS: C9.1, U6.1 (VBUS); also elsewhere on the board
VLED: C30.1, U10.1 (OUT); also elsewhere on the board
VOTG: C20.1, U6.23 (PMID), U10.5 (IN); also elsewhere on the board
VSYS: C13.1, C14.1, C31.1, C33.1, D82.2 (A), L2.2, L4.1, L6.1, U6.8 (OTG), U6.15 (SYS), U6.16 (SYS), U7.1 (EN), U7.6 (VIN), U11.6 (VIN), U12.6 (VIN); also elsewhere on the board

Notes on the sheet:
Standby
3.3v DC/DC
20mA @ 24v
PMIC
LED SWITCH
Display backlight DC/DC
Keyboard backlight DC/DC
40mA @ 13v
DSEL is an open-drain output, pulled low when the D+/D- pins are in use for charger detection. D+/D- float otherwise. Watch out with the I2C bus of this device, wrong configuration can be dangerous. VBUS is the voltage coming from the input USB-C port. This voltage can be 5 up to 14 volts. VOTG is 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

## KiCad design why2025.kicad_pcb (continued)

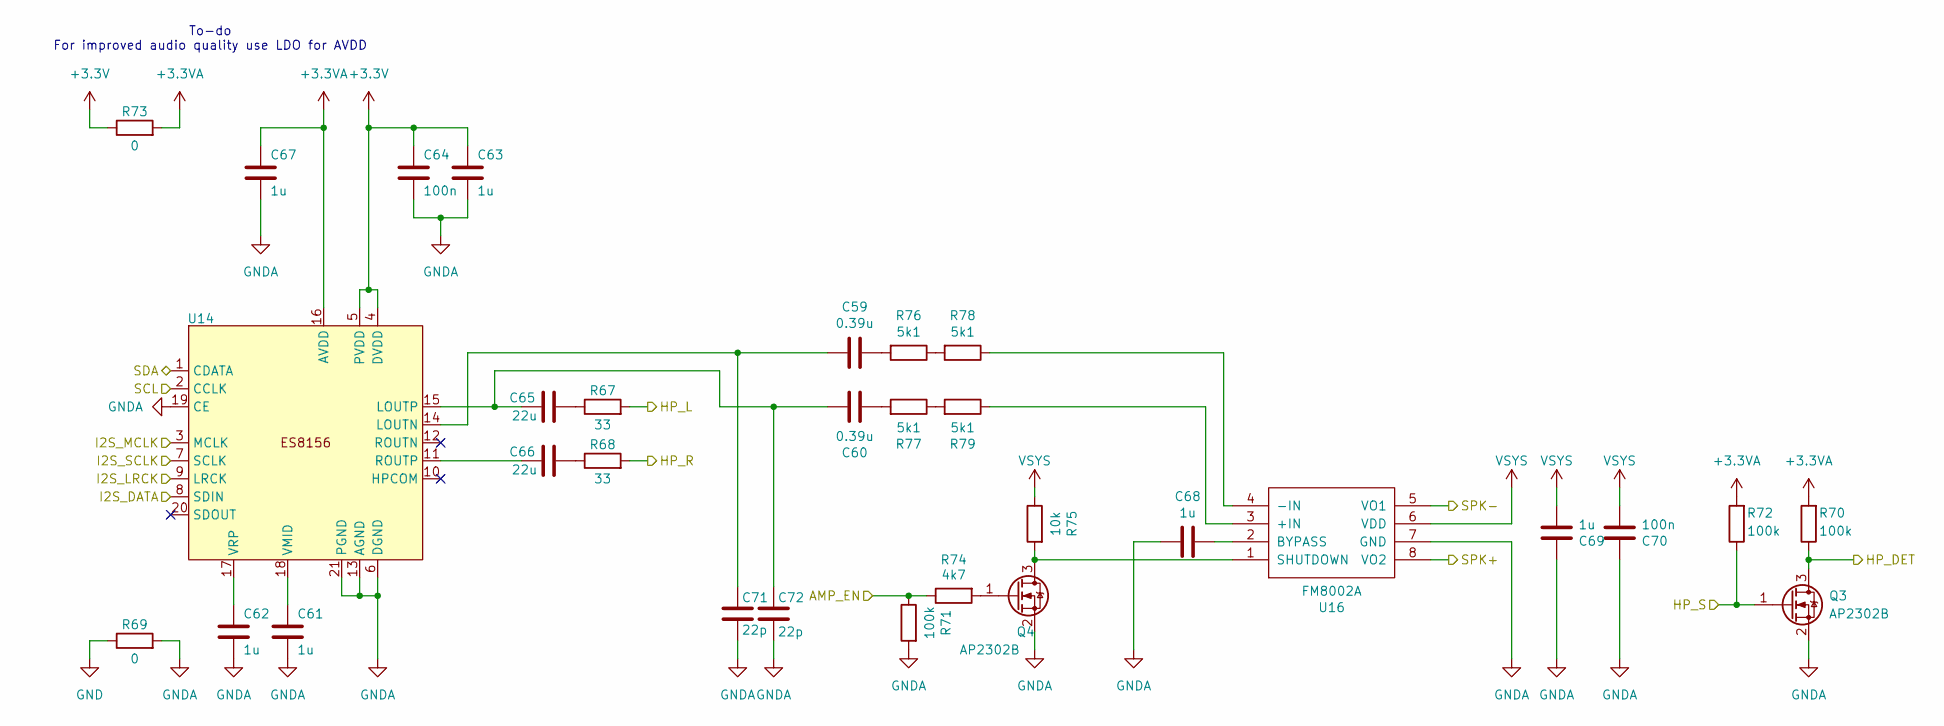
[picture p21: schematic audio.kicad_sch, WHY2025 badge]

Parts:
C59, C60: 0.39u; C_0603_1608Metric; LCSC C1623
C61, C62, C63, C67: 1u; C_0603_1608Metric
C64: 100n; C_0402_1005Metric
C65, C66: 22u; C_1206_3216Metric
C68, C69: 1u; C_0603_1608Metric; LCSC C107372
C70: 100n; C_0402_1005Metric; LCSC C307331
C71, C72: 22p; C_0402_1005Metric
Q3: AP2302B; SOT-23; LCSC C406812
Q4: AP2302B; SOT-23; MPN AP2302B; LCSC C406812
R67, R68: 33; R_0402_1005Metric
R69, R73: 0; R_0402_1005Metric
R70, R72: 100k; R_0402_1005Metric
R71: 100k; R_0402_1005Metric; LCSC C25741
R74: 4k7; R_0402_1005Metric; LCSC C25900
R75: 10k; R_0402_1005Metric; LCSC C25744
R76, R77, R78, R79: 5k1; R_0402_1005Metric; LCSC C25941
U14: VQFN-20-1EP_3x3mm_P0.4mm_EP1.7x1.7mm
U16: FM8002A; SSOP-8_3.9x5.05mm_P1.27mm; LCSC C94625

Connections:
+3.3V: C63.1, C64.1, R73.1, U14.4 (DVDD), U14.5 (PVDD); also elsewhere on the board
+3.3VA: C67.1, R70.2, R72.2, R73.2, U14.16 (AVDD)
/Application processor/I2S_DATA: U14.8 (SDIN); also elsewhere on the board
/Application processor/I2S_LRCK: U14.9 (LRCK); also elsewhere on the board
/Application processor/I2S_MCLK: U14.3 (MCLK); also elsewhere on the board
/Application processor/I2S_SCLK: U14.7 (SCLK); also elsewhere on the board
/Audio/HP_L: R67.2
/Audio/HP_R: R68.2
/Audio/HP_S: Q3.1 (G), R72.1
/Audio/SPK+: U16.8 (VO2); also elsewhere on the board
/Audio/SPK-: U16.5 (VO1); also elsewhere on the board
E11: U14.2 (CCLK); also elsewhere on the board
GND: R69.1; also elsewhere on the board
GNDA: C61.2, C62.2, C63.2, C64.2, C67.2, C68.1, C69.2, C70.2, C71.2, C72.2, Q3.2 (S), Q4.2 (S), R69.2, R71.2, U14.6 (DGND), U14.13 (AGND), U14.19 (CE), U14.21 (PGND), U16.7 (GND); also elsewhere on the board
HP_DET: Q3.3 (D), R70.1; also elsewhere on the board
INT_SDA: U14.1 (CDATA); also elsewhere on the board
unnamed: C59.1, R76.2
unnamed: C60.1, R77.2
unnamed: C65.2, R67.1
unnamed: C66.2, R68.1
unnamed: Q4.3 (D), R75.2, U16.1 (SHUTDOWN)
unnamed: Q4.1 (G), R74.2
unnamed: R71.1, R74.1
unnamed: R76.1, R78.2
unnamed: R77.1, R79.2
unnamed: C59.2, C71.1, U14.14 (LOUTN)
unnamed: C60.2, C65.1, C72.1, U14.15 (LOUTP)
unnamed: C66.1, U14.11 (ROUTP)
unnamed: C61.1, U14.18 (VMID)
unnamed: C62.1, U14.17 (VRP)
unnamed: R79.1, U16.3 (+IN)
unnamed: R78.1, U16.4 (-IN)
unnamed: C68.2, U16.2 (BYPASS)
VSYS: C69.1, C70.1, R75.1, U16.6 (VDD); also elsewhere on the board

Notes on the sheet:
To-do For improved audio quality use LDO for AVDD

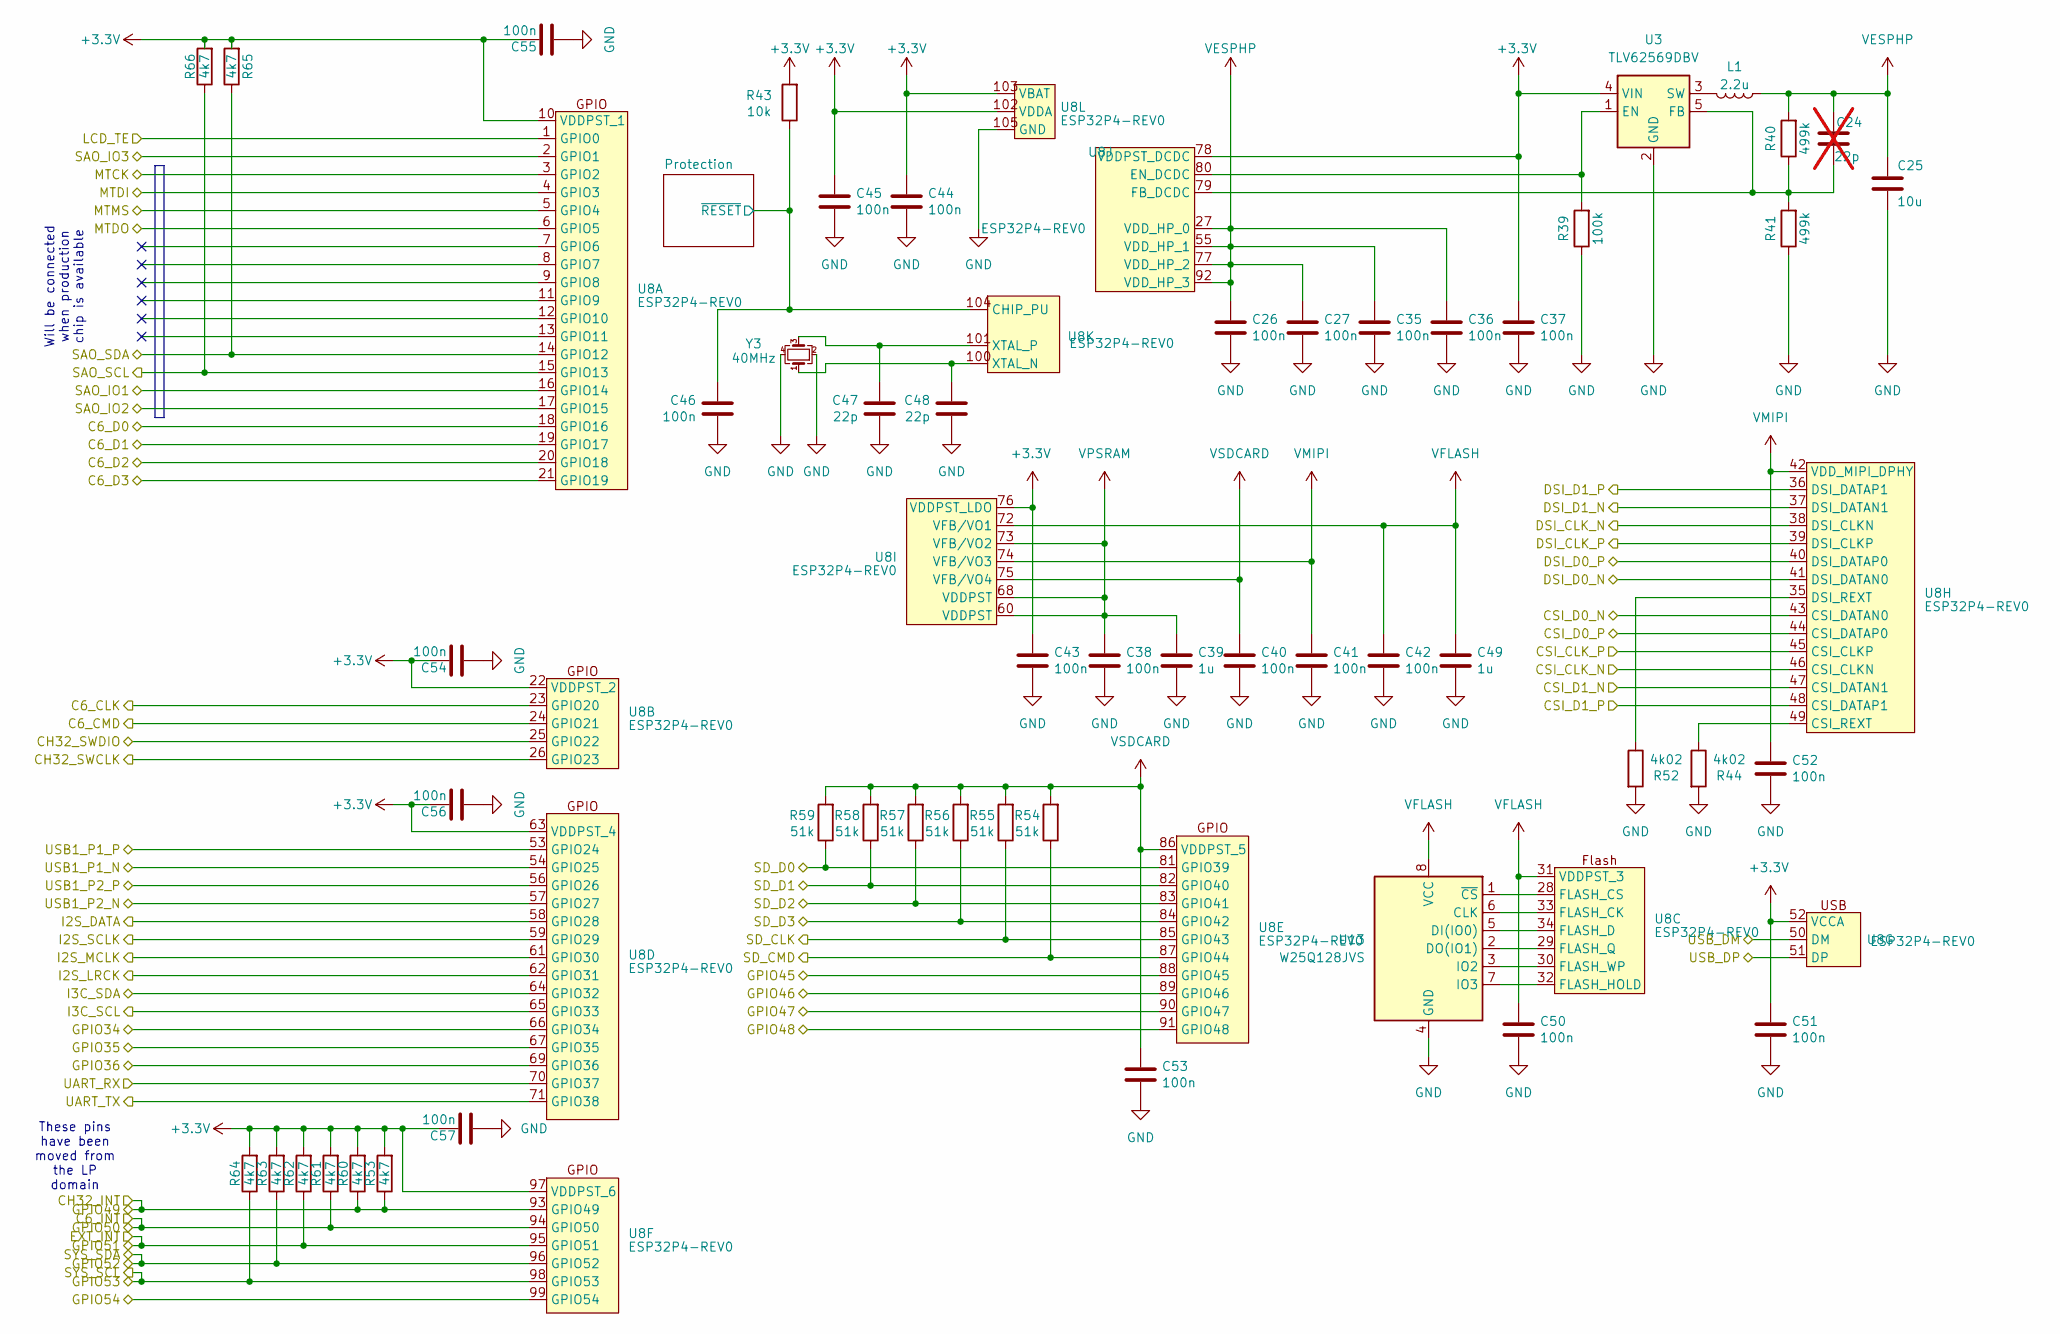
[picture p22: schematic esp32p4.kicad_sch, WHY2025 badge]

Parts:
C24: 22p; C_0402_1005Metric; not fitted
C25: 10u; C_1206_3216Metric
C26, C27, C35, C36, C37, C38, C40, C41, C42, C43, C44, C45, C46, C50, C51, C52, C53, C54, C55, C56, C57: 100n; C_0402_1005Metric; LCSC C307331
C39, C49: 1u; C_0603_1608Metric
C47, C48: 22p; C_0402_1005Metric
L1: 2.2u; Inductor_MSC20FC; LCSC C375944
R39: 100k; R_0402_1005Metric
R40, R41: 499k; R_0402_1005Metric
R43: 10k; R_0402_1005Metric
R44, R52: 4k02; R_0402_1005Metric
R53, R60, R61, R62, R63, R64, R65, R66: 4k7; R_0402_1005Metric
R54, R55, R56, R57, R58, R59: 51k; R_0402_1005Metric
U3: TLV62569DBV; SOT-23-5
U8: ESP32P4-REV0; esp32p4rev0
U13: W25Q128JVS; SOIC-8_5.23x5.23mm_P1.27mm
Y3: 40MHz; Crystal_SMD_3225-4Pin_3.2x2.5mm; LCSC C337678

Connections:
+3.3V: C37.1, C43.1, C44.1, C45.1, C51.1, C54.1, C55.1, C56.1, C57.1, R43.2, R53.2, R60.2, R61.2, R62.2, R63.2, R64.2, R65.2, R66.2, U3.4 (VIN), U8.10 (VDDPST_1), U8.22 (VDDPST_2), U8.52 (VCCA), U8.63 (VDDPST_4), U8.76 (VDDPST_LDO), U8.78 (VDDPST_DCDC), U8.97 (VDDPST_6), U8.102 (VDDA), U8.103 (VBAT); also elsewhere on the board
/Application processor/C6_CLK: U8.23 (GPIO20); also elsewhere on the board
/Application processor/C6_CMD: U8.24 (GPIO21); also elsewhere on the board
/Application processor/C6_D0: U8.18 (GPIO16); also elsewhere on the board
/Application processor/C6_D1: U8.19 (GPIO17); also elsewhere on the board
/Application processor/C6_D2: U8.20 (GPIO18); also elsewhere on the board
/Application processor/C6_D3: U8.21 (GPIO19); also elsewhere on the board
/Application processor/CH32_SWCLK: U8.26 (GPIO23); also elsewhere on the board
/Application processor/CH32_SWDIO: U8.25 (GPIO22); also elsewhere on the board
/Application processor/CSI_CLK_N: U8.46 (CSI_CLKN)
/Application processor/CSI_CLK_P: U8.45 (CSI_CLKP)
/Application processor/CSI_D0_N: U8.43 (CSI_DATAN0)
/Application processor/CSI_D0_P: U8.44 (CSI_DATAP0)
/Application processor/CSI_D1_N: U8.47 (CSI_DATAN1)
/Application processor/CSI_D1_P: U8.48 (CSI_DATAP1)
/Application processor/DSI_CLK_N: U8.38 (DSI_CLKN); also elsewhere on the board
/Application processor/DSI_CLK_P: U8.39 (DSI_CLKP); also elsewhere on the board
/Application processor/DSI_D0_N: U8.41 (DSI_DATAN0); also elsewhere on the board
/Application processor/DSI_D0_P: U8.40 (DSI_DATAP0); also elsewhere on the board
/Application processor/DSI_D1_N: U8.37 (DSI_DATAN1); also elsewhere on the board
/Application processor/DSI_D1_P: U8.36 (DSI_DATAP1); also elsewhere on the board
/Application processor/I2S_DATA: U8.58 (GPIO28); also elsewhere on the board
/Application processor/I2S_LRCK: U8.62 (GPIO31); also elsewhere on the board
/Application processor/I2S_MCLK: U8.61 (GPIO30); also elsewhere on the board
/Application processor/I2S_SCLK: U8.59 (GPIO29); also elsewhere on the board
/Application processor/LCD_TE: U8.1 (GPIO0); also elsewhere on the board
/Application processor/Protection/~RESET: C46.1, R43.1, U8.104 (CHIP_PU); also elsewhere on the board
/Application processor/SD_CLK: R55.1, U8.85 (GPIO43); also elsewhere on the board
/Application processor/SD_CMD: R54.1, U8.87 (GPIO44); also elsewhere on the board
/Application processor/SD_D0: R59.1, U8.81 (GPIO39); also elsewhere on the board
/Application processor/SD_D1: R58.1, U8.82 (GPIO40); also elsewhere on the board
/Application processor/SD_D2: R57.1, U8.83 (GPIO41); also elsewhere on the board
/Application processor/SD_D3: R56.1, U8.84 (GPIO42); also elsewhere on the board
/Application processor/UART_RX: U8.70 (GPIO37); also elsewhere on the board
/Application processor/UART_TX: U8.71 (GPIO38); also elsewhere on the board
/Application processor/USB1_P1_N: U8.54 (GPIO25); also elsewhere on the board
/Application processor/USB1_P1_P: U8.53 (GPIO24); also elsewhere on the board
/Application processor/USB_DM: U8.50 (DM); also elsewhere on the board
/Application processor/USB_DP: U8.51 (DP); also elsewhere on the board
E0: U8.66 (GPIO34); also elsewhere on the board
E1: U8.67 (GPIO35); also elsewhere on the board
E2: U8.69 (GPIO36); also elsewhere on the board
E3: U8.88 (GPIO45); also elsewhere on the board
E4: U8.89 (GPIO46); also elsewhere on the board
E5: U8.90 (GPIO47); also elsewhere on the board
E6: U8.91 (GPIO48); also elsewhere on the board
E7: R53.1, R60.1, U8.93 (GPIO49); also elsewhere on the board
E8: R61.1, U8.94 (GPIO50); also elsewhere on the board
E11: R64.1, U8.98 (GPIO53); also elsewhere on the board
E12: U8.99 (GPIO54); also elsewhere on the board
EXT_INT: R62.1, U8.95 (GPIO51); also elsewhere on the board
EXT_USB_N: U8.57 (GPIO27); also elsewhere on the board
EXT_USB_P: U8.56 (GPIO26); also elsewhere on the board
GND: C25.2, C26.2, C27.2, C35.2, C36.2, C37.2, C38.2, C39.2, C40.2, C41.2, C42.2, C43.2, C44.2, C45.2, C46.2, C47.2, C48.2, C49.2, C50.2, C51.2, C52.2, C53.2, C54.2, C55.2, C56.2, C57.2, R39.1, R41.1, R44.2, R52.2, U3.2 (GND), U8.105 (GND), U13.4 (GND), Y3.2, Y3.4; also elsewhere on the board
I3C_SCL: U8.65 (GPIO33); also elsewhere on the board
I3C_SDA: U8.64 (GPIO32); also elsewhere on the board
INT_SDA: R63.1, U8.96 (GPIO52); also elsewhere on the board
MTCK: U8.3 (GPIO2); also elsewhere on the board
MTDI: U8.4 (GPIO3); also elsewhere on the board
MTDO: U8.6 (GPIO5); also elsewhere on the board
MTMS: U8.5 (GPIO4); also elsewhere on the board
unnamed: R39.2, U3.1 (EN), U8.80 (EN_DCDC)
unnamed: C24.2, R40.1, R41.2, U3.5 (FB), U8.79 (FB_DCDC)
unnamed: L1.2, U3.3 (SW)
unnamed: R44.1, U8.49 (CSI_REXT)
unnamed: R52.1, U8.35 (DSI_REXT)
unnamed: C48.1, U8.100 (XTAL_N), Y3.1
unnamed: C47.1, U8.101 (XTAL_P), Y3.3
unnamed: U8.33 (FLASH_CK), U13.6 (CLK)
unnamed: U8.34 (FLASH_D), U13.5 (DI(IO0))
unnamed: U8.29 (FLASH_Q), U13.2 (DO(IO1))
unnamed: U8.30 (FLASH_WP), U13.3 (IO2)
unnamed: U8.32 (FLASH_HOLD), U13.7 (IO3)
unnamed: U8.28 (FLASH_CS), U13.1 (~CS)
SAO_IO1: U8.16 (GPIO14); also elsewhere on the board
SAO_IO2: U8.17 (GPIO15); also elsewhere on the board
SAO_IO3: U8.2 (GPIO1); also elsewhere on the board
SAO_SCL: R66.1, U8.15 (GPIO13); also elsewhere on the board
SAO_SDA: R65.1, U8.14 (GPIO12); also elsewhere on the board
VESPHP: C24.1, C25.1, C26.1, C27.1, C35.1, C36.1, L1.1, R40.2, U8.27 (VDD_HP_0), U8.55 (VDD_HP_1), U8.77 (VDD_HP_2), U8.92 (VDD_HP_3)
VFLASH: C42.1, C49.1, C50.1, U8.31 (VDDPST_3), U8.72 (VFB/VO1), U13.8 (VCC)
VMIPI: C41.1, C52.1, U8.42 (VDD_MIPI_DPHY), U8.74 (VFB/VO3)
VPSRAM: C38.1, C39.1, U8.60 (VDDPST), U8.68 (VDDPST), U8.73 (VFB/VO2)
VSDCARD: C40.1, C53.1, R54.2, R55.2, R56.2, R57.2, R58.2, R59.2, U8.75 (VFB/VO4), U8.86 (VDDPST_5); also elsewhere on the board

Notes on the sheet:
Will be connected when production chip is available
These pins have been moved from the LP domain

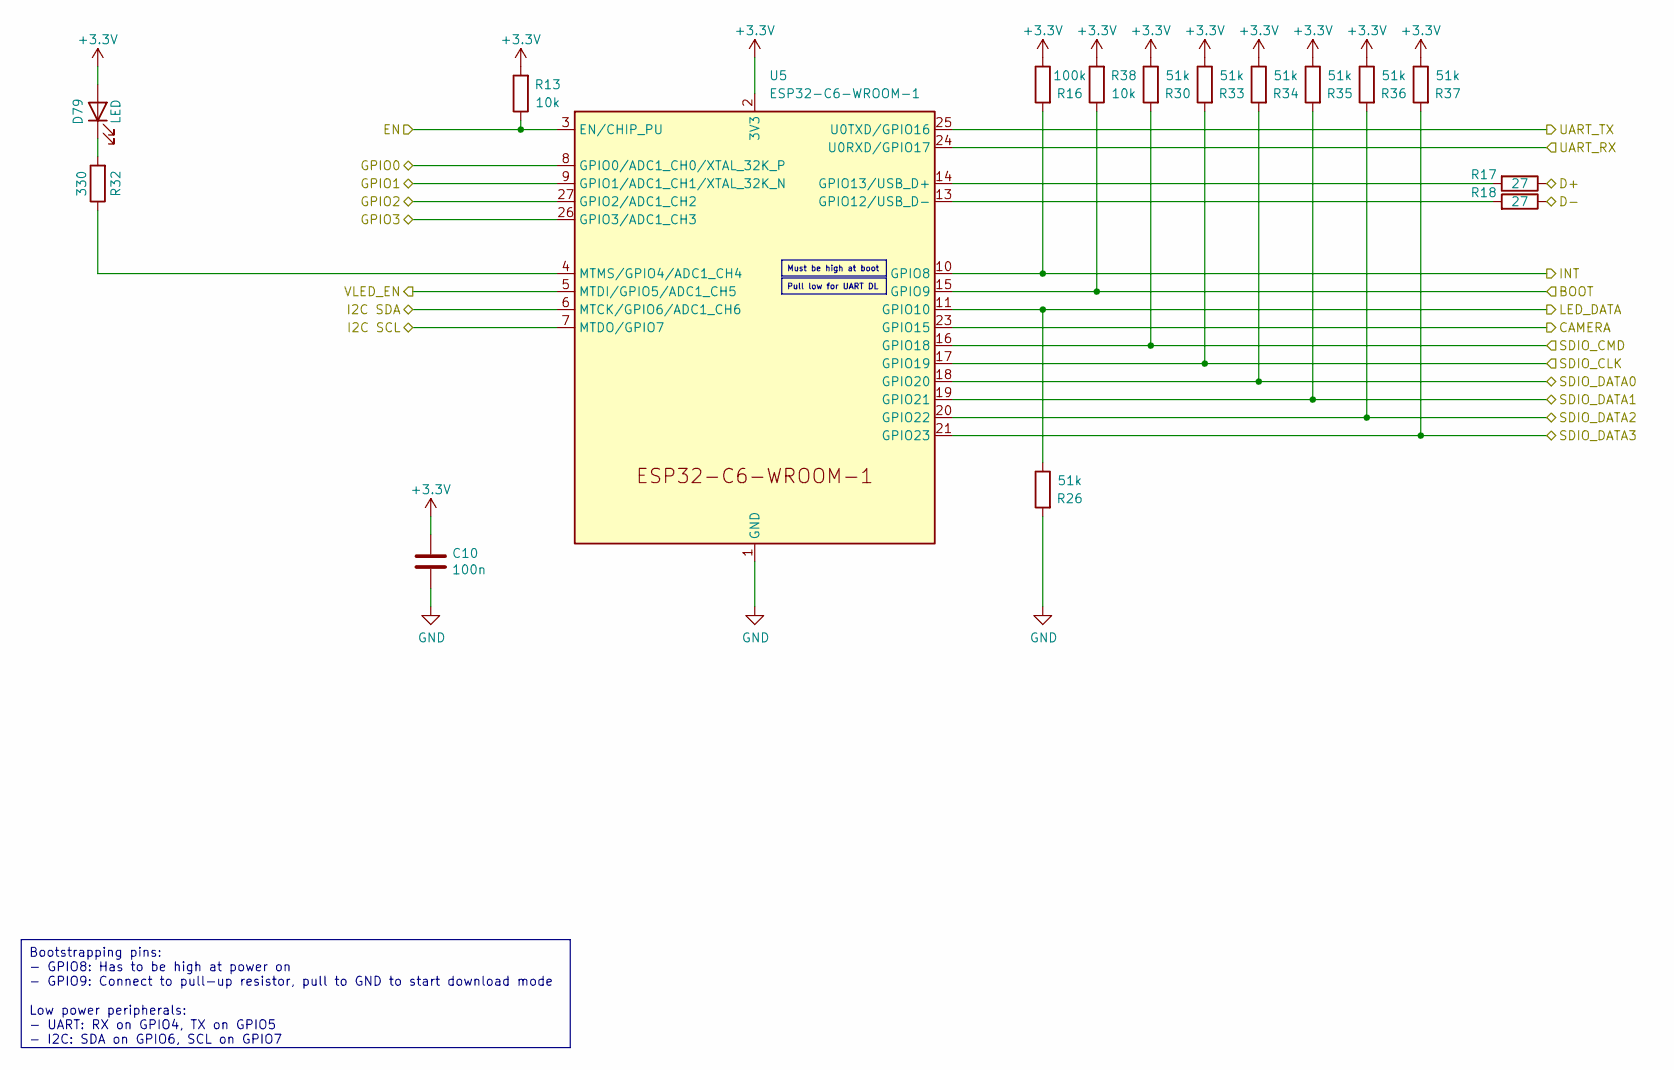
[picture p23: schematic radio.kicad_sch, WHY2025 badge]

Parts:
C10: 100n; C_0402_1005Metric; LCSC C307331
D79: LED; LED_0603_1608Metric
R13, R38: 10k; R_0402_1005Metric; LCSC C25744
R16: 100k; R_0402_1005Metric
R17, R18: 27; R_0402_1005Metric; LCSC C25156
R26, R30, R33, R34, R35, R36, R37: 51k; R_0402_1005Metric
R32: 330; R_0402_1005Metric
U5: ESP32-C6-WROOM-1

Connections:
+3.3V: C10.1, D79.2 (A), R13.2, R16.1, R30.1, R33.1, R34.1, R35.1, R36.1, R37.1, R38.2, U5.2 (3V3); also elsewhere on the board
/Application processor/C6_CLK: R33.2, U5.17 (GPIO19); also elsewhere on the board
/Application processor/C6_CMD: R30.2, U5.16 (GPIO18); also elsewhere on the board
/Application processor/C6_D0: R34.2, U5.18 (GPIO20); also elsewhere on the board
/Application processor/C6_D1: R35.2, U5.19 (GPIO21); also elsewhere on the board
/Application processor/C6_D2: R36.2, U5.20 (GPIO22); also elsewhere on the board
/Application processor/C6_D3: R37.2, U5.21 (GPIO23); also elsewhere on the board
/Application processor/UART_RX: U5.25 (U0TXD/GPIO16); also elsewhere on the board
/Application processor/UART_TX: U5.24 (U0RXD/GPIO17); also elsewhere on the board
/Coprocessor/C6_BOOT: R38.1, U5.15 (GPIO9); also elsewhere on the board
/Coprocessor/C6_EN: R13.1, U5.3 (EN/CHIP_PU); also elsewhere on the board
/LEDs/DIN: R26.1, U5.11 (GPIO10); also elsewhere on the board
/Power/VLED_EN: U5.5 (MTDI/GPIO5/ADC1_CH5); also elsewhere on the board
/Radio/D+: R17.1; also elsewhere on the board
/Radio/D-: R18.1; also elsewhere on the board
/Radio/GPIO0: U5.8 (GPIO0/ADC1_CH0/XTAL_32K_P)
/Radio/GPIO1: U5.9 (GPIO1/ADC1_CH1/XTAL_32K_N)
/Radio/GPIO2: U5.27 (GPIO2/ADC1_CH2)
/Radio/GPIO3: U5.26 (GPIO3/ADC1_CH3)
CAM_GPIO: U5.23 (GPIO15)
E8: R16.2, U5.10 (GPIO8); also elsewhere on the board
E11: U5.7 (MTDO/GPIO7); also elsewhere on the board
GND: C10.2, R26.2, U5.1 (GND), U5.12 (GPIO11), U5.28 (GND), U5.29 (GND); also elsewhere on the board
INT_SDA: U5.6 (MTCK/GPIO6/ADC1_CH6); also elsewhere on the board
unnamed: D79.1 (K), R32.2
unnamed: R18.2, U5.13 (GPIO12/USB_D-)
unnamed: R17.2, U5.14 (GPIO13/USB_D+)
unnamed: R32.1, U5.4 (MTMS/GPIO4/ADC1_CH4)

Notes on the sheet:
Pull low for UART DL
Must be high at boot
Bootstrapping pins: - GPIO8: Has to be high at power on - GPIO9: Connect to pull-up resistor, pull to GND to start download mode Low power peripherals: - UART: RX on GPIO4, TX on GPIO5 - I2C: SDA on GPIO6, SCL on GPIO7

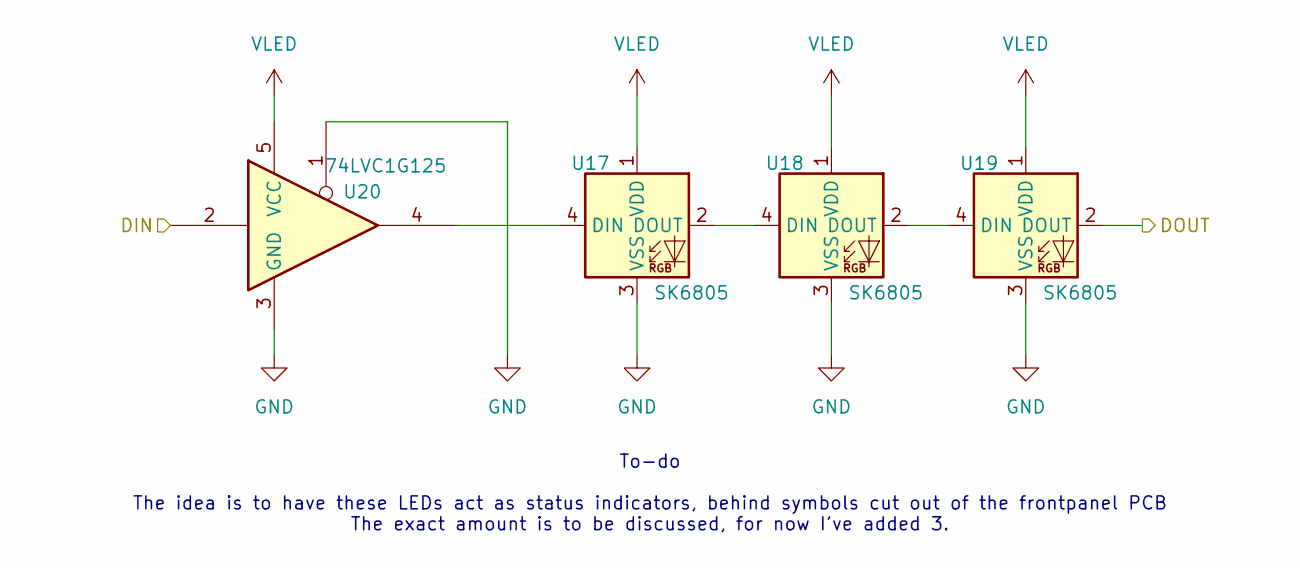
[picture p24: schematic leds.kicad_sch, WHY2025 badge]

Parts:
U17, U18, U19: SK6805; SK6805-EC20; LCSC C2890036
U20: 74LVC1G125; SOT-353_SC-70-5; LCSC C12519

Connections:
/LEDs/DIN: U20.2; also elsewhere on the board
GND: U17.3 (VSS), U18.3 (VSS), U19.3 (VSS), U20.1, U20.3 (GND); also elsewhere on the board
unnamed: U17.4 (DIN), U20.4
unnamed: U17.2 (DOUT), U18.4 (DIN)
unnamed: U18.2 (DOUT), U19.4 (DIN)
VLED: U17.1 (VDD), U18.1 (VDD), U19.1 (VDD), U20.5 (VCC); also elsewhere on the board

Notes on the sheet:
To-do The idea is to have these LEDs act as status indicators, behind symbols cut out of the frontpanel PCB The exact amount is to be discussed, for now I've added 3.

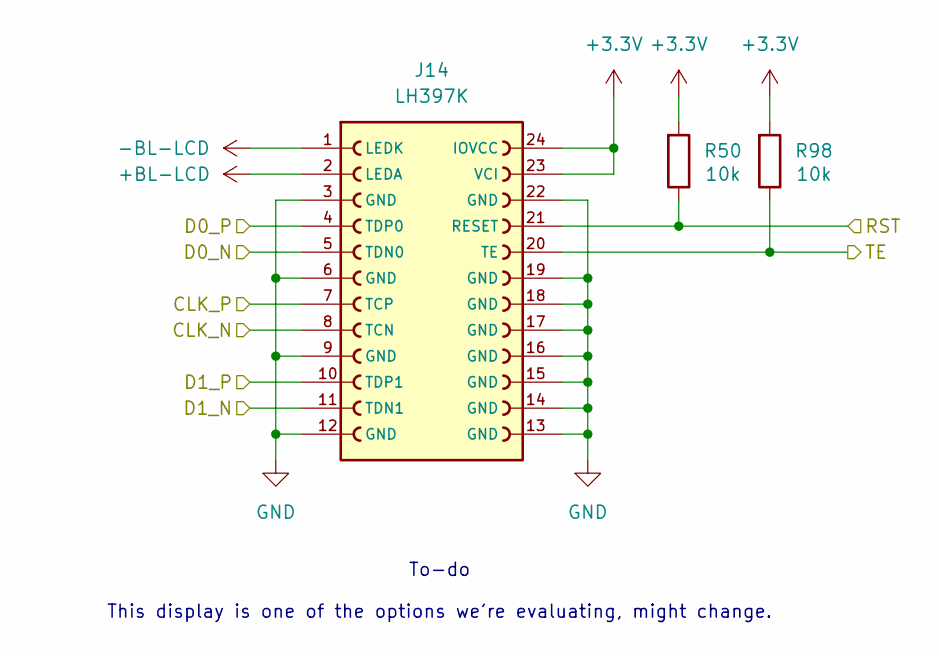
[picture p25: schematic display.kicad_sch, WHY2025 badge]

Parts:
J14: LH397K; LH397K-IC01
R50, R98: 10k; R_0402_1005Metric

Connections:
+3.3V: J14.23 (VCI), J14.24 (IOVCC), R50.2, R98.2; also elsewhere on the board
+BL-LCD: J14.2 (LEDA); also elsewhere on the board
-BL-LCD: J14.1 (LEDK); also elsewhere on the board
/Application processor/DSI_CLK_N: J14.7 (TCP); also elsewhere on the board
/Application processor/DSI_CLK_P: J14.8 (TCN); also elsewhere on the board
/Application processor/DSI_D0_N: J14.5 (TDN0); also elsewhere on the board
/Application processor/DSI_D0_P: J14.4 (TDP0); also elsewhere on the board
/Application processor/DSI_D1_N: J14.11 (TDN1); also elsewhere on the board
/Application processor/DSI_D1_P: J14.10 (TDP1); also elsewhere on the board
/Application processor/LCD_TE: J14.20 (TE), R98.1; also elsewhere on the board
/Coprocessor/LCD_RST: J14.21 (RESET), R50.1; also elsewhere on the board
GND: J14.3 (GND), J14.6 (GND), J14.9 (GND), J14.12 (GND), J14.13 (GND), J14.14 (GND), J14.15 (GND), J14.16 (GND), J14.17 (GND), J14.18 (GND), J14.19 (GND), J14.22 (GND); also elsewhere on the board

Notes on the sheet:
To-do This display is one of the options we're evaluating, might change.

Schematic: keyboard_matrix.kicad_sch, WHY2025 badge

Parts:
D1, D2, D3, D4, D5, D6, D7, D8, D9, D10, D11, D12, D13, D14, D15, D16, D17, D18, D19, D20, D21, D22, D23, D24, D25, D26, D27, D28, D29, D30, D31, D32, D33, D34, D35, D36, D37, D38, D39, D40, D41, D42, D43, D44, D45, D46, D47, D48, D49, D50, D51, D52, D53, D54, D55, D56, D57, D58, D59, D60, D61, D62, D63, D64, D65, D66, D67, D68, D69, D70, D71, D72: LL4148; D_SOD-323; LCSC C2891733
D73, D74, D75, D76, D77, D78, D80, D81: LED; LTW-010DCG-SR-G
R1, R2, R3, R4, R5, R6, R7, R8: 10k; R_0402_1005Metric; LCSC C60490
U2: keyboard_arturo182

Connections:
+BL-KB: D76.2 (A), D77.2 (A); also elsewhere on the board
-BL-KB: D73.1 (K), D81.1 (K); also elsewhere on the board
/Coprocessor/Keyboard/EXT_I: D48.2 (A); also elsewhere on the board
GND: R1.2, R2.2, R3.2, R4.2, R5.2, R6.2, R7.2, R8.2; also elsewhere on the board
KB_COL0: D1.1 (K), D3.1 (K), D5.1 (K), D25.1 (K), D27.1 (K), D44.1 (K), D49.1 (K), D51.1 (K), D53.1 (K), R1.1; also elsewhere on the board
KB_COL1: D7.1 (K), D9.1 (K), D11.1 (K), D29.1 (K), D31.1 (K), D45.1 (K), D55.1 (K), D57.1 (K), D59.1 (K), R2.1; also elsewhere on the board
KB_COL2: D13.1 (K), D15.1 (K), D17.1 (K), D34.1 (K), D36.1 (K), D46.1 (K), D61.1 (K), D63.1 (K), D65.1 (K), R3.1; also elsewhere on the board
KB_COL3: D19.1 (K), D21.1 (K), D23.1 (K), D39.1 (K), D41.1 (K), D47.1 (K), D67.1 (K), D69.1 (K), D71.1 (K), R4.1; also elsewhere on the board
KB_COL4: D2.1 (K), D4.1 (K), D6.1 (K), D26.1 (K), D28.1 (K), D33.1 (K), D50.1 (K), D52.1 (K), D54.1 (K), R5.1; also elsewhere on the board
KB_COL5: D8.1 (K), D10.1 (K), D12.1 (K), D30.1 (K), D32.1 (K), D38.1 (K), D56.1 (K), D58.1 (K), D60.1 (K), R6.1; also elsewhere on the board
KB_COL6: D14.1 (K), D16.1 (K), D18.1 (K), D35.1 (K), D37.1 (K), D43.1 (K), D62.1 (K), D64.1 (K), D66.1 (K), R7.1; also elsewhere on the board
KB_COL7: D20.1 (K), D22.1 (K), D24.1 (K), D40.1 (K), D42.1 (K), D48.1 (K), D68.1 (K), D70.1 (K), D72.1 (K), R8.1; also elsewhere on the board
KB_ROW0: U2.1 (ESC), U2.3 (F1), U2.5 (F2), U2.7 (F3), U2.17 (`), U2.19 (1), U2.21 (2), U2.23 (3); also elsewhere on the board
KB_ROW1: U2.43 (TAB), U2.45 (Q), U2.47 (W), U2.49 (E), U2.69 (FN), U2.71 (A), U2.73 (S), U2.75 (D); also elsewhere on the board
KB_ROW2: U2.95 (SHL), U2.97 (Z), U2.99 (X), U2.101 (C), U2.121 (CTRL), U2.123 (MT), U2.125 (ALT), U2.127 (\); also elsewhere on the board
KB_ROW3: U2.25 (4), U2.27 (5), U2.29 (6), U2.31 (7), U2.51 (R), U2.53 (T), U2.55 (Y), U2.57 (U); also elsewhere on the board
KB_ROW4: U2.77 (F), U2.79 (G), U2.81 (H), U2.83 (J), U2.103 (V), U2.105 (B), U2.107 (N), U2.109 (M); also elsewhere on the board
KB_ROW5: U2.9 (F4), U2.11 (F5), U2.13 (F6), U2.15 (BS), U2.35 (9), U2.37 (0), U2.39 (-), U2.41 (=); also elsewhere on the board
KB_ROW6: U2.61 (O), U2.63, U2.65 ([), U2.67 (]), U2.87 (L), U2.89 (;), U2.91 ('), U2.93 (RET); also elsewhere on the board
KB_ROW7: U2.113 (.), U2.115 (/), U2.117 (/\), U2.119 (SHR), U2.135 (AGR), U2.137 (<), U2.139 (\/), U2.141 (>); also elsewhere on the board
KB_ROW8: U2.33 (8), U2.59 (I), U2.85 (K), U2.111 (,), U2.129 (SP), U2.131 (SP), U2.133 (SP); also elsewhere on the board
unnamed: D1.2 (A), U2.2
unnamed: D2.2 (A), U2.18
unnamed: D3.2 (A), U2.44
unnamed: D4.2 (A), U2.70
unnamed: D5.2 (A), U2.96
unnamed: D6.2 (A), U2.122
unnamed: D7.2 (A), U2.4
unnamed: D8.2 (A), U2.20
unnamed: D9.2 (A), U2.46
unnamed: D10.2 (A), U2.72
unnamed: D11.2 (A), U2.98
unnamed: D12.2 (A), U2.124
unnamed: D13.2 (A), U2.6
unnamed: D14.2 (A), U2.22
unnamed: D15.2 (A), U2.48
unnamed: D16.2 (A), U2.74
unnamed: D17.2 (A), U2.100
unnamed: D18.2 (A), U2.126
unnamed: D19.2 (A), U2.8
unnamed: D20.2 (A), U2.24
unnamed: D21.2 (A), U2.50
unnamed: D22.2 (A), U2.76
unnamed: D23.2 (A), U2.102
unnamed: D24.2 (A), U2.128
unnamed: D25.2 (A), U2.26
unnamed: D26.2 (A), U2.52
unnamed: D27.2 (A), U2.78
unnamed: D28.2 (A), U2.104
unnamed: D29.2 (A), U2.28
unnamed: D30.2 (A), U2.54
unnamed: D31.2 (A), U2.80
unnamed: D32.2 (A), U2.106
unnamed: D33.2 (A), U2.130
unnamed: D34.2 (A), U2.30
unnamed: D35.2 (A), U2.56
unnamed: D36.2 (A), U2.82
unnamed: D37.2 (A), U2.108
unnamed: D38.2 (A), U2.132
unnamed: D39.2 (A), U2.32
unnamed: D40.2 (A), U2.58
unnamed: D41.2 (A), U2.84
unnamed: D42.2 (A), U2.110
unnamed: D43.2 (A), U2.134
unnamed: D44.2 (A), U2.34
unnamed: D45.2 (A), U2.60
unnamed: D46.2 (A), U2.86
unnamed: D47.2 (A), U2.112
unnamed: D49.2 (A), U2.10
unnamed: D50.2 (A), U2.36
unnamed: D51.2 (A), U2.62
unnamed: D52.2 (A), U2.88
unnamed: D53.2 (A), U2.114
unnamed: D54.2 (A), U2.136
unnamed: D55.2 (A), U2.12
unnamed: D56.2 (A), U2.38
unnamed: D57.2 (A), U2.64
unnamed: D58.2 (A), U2.90
unnamed: D59.2 (A), U2.116
unnamed: D60.2 (A), U2.138
unnamed: D61.2 (A), U2.14
unnamed: D62.2 (A), U2.40
unnamed: D63.2 (A), U2.66
unnamed: D64.2 (A), U2.92
unnamed: D65.2 (A), U2.118
unnamed: D66.2 (A), U2.140
unnamed: D67.2 (A), U2.16
unnamed: D68.2 (A), U2.42
unnamed: D69.2 (A), U2.68
unnamed: D70.2 (A), U2.94
unnamed: D71.2 (A), U2.120
unnamed: D72.2 (A), U2.142
unnamed: D73.2 (A), D74.1 (K)
unnamed: D74.2 (A), D75.1 (K)
unnamed: D75.2 (A), D76.1 (K)
unnamed: D77.1 (K), D78.2 (A)
unnamed: D78.1 (K), D80.2 (A)
unnamed: D80.1 (K), D81.2 (A)

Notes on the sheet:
Extra button can be connected between ROW8 and EXT

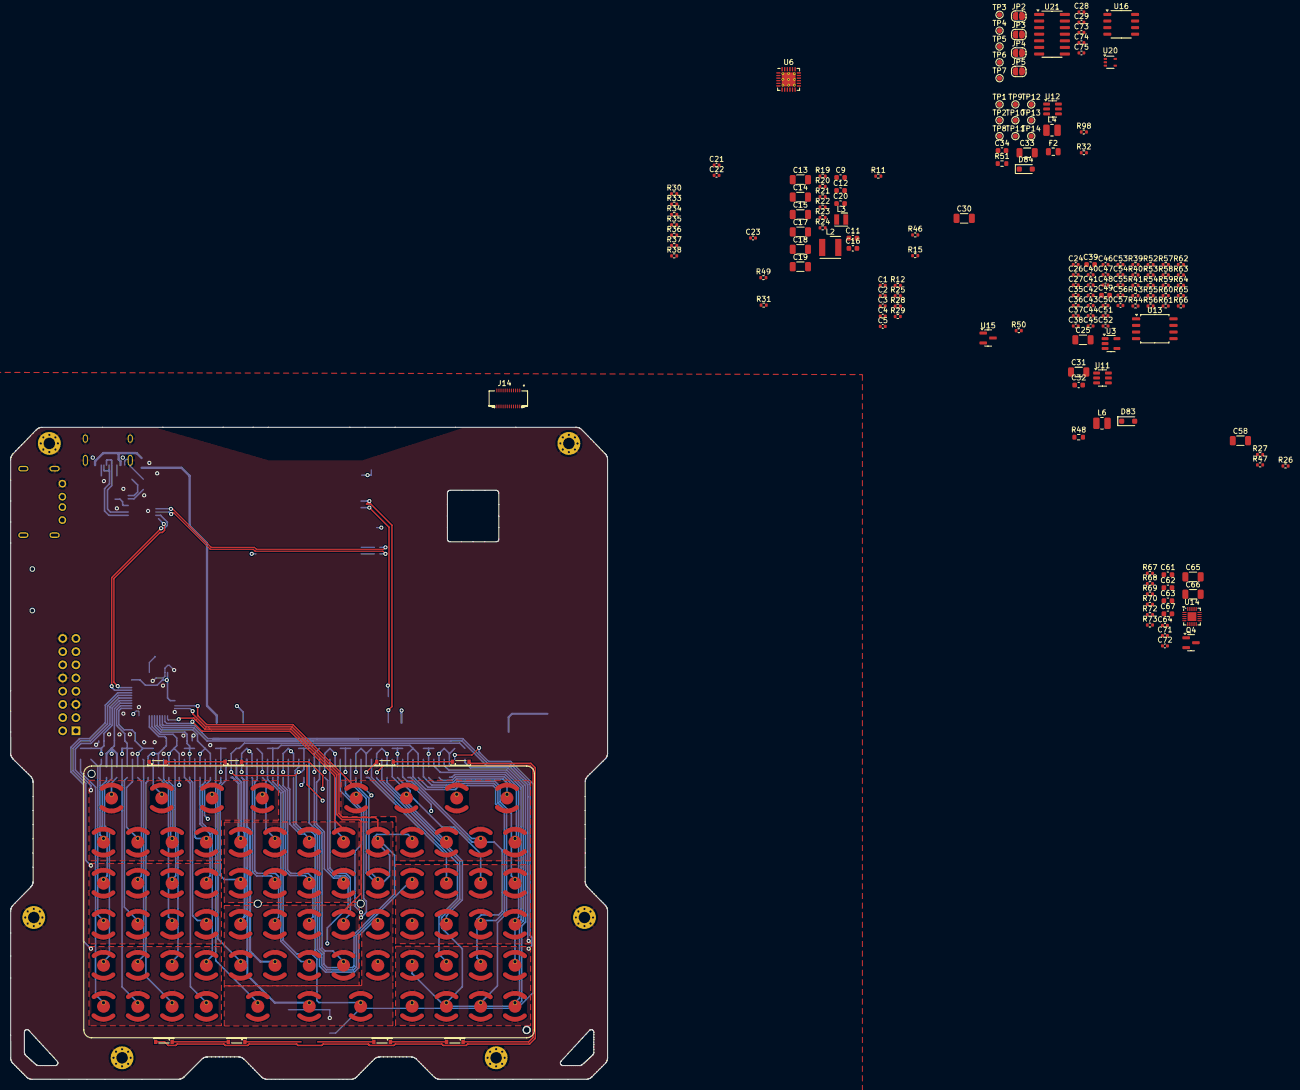
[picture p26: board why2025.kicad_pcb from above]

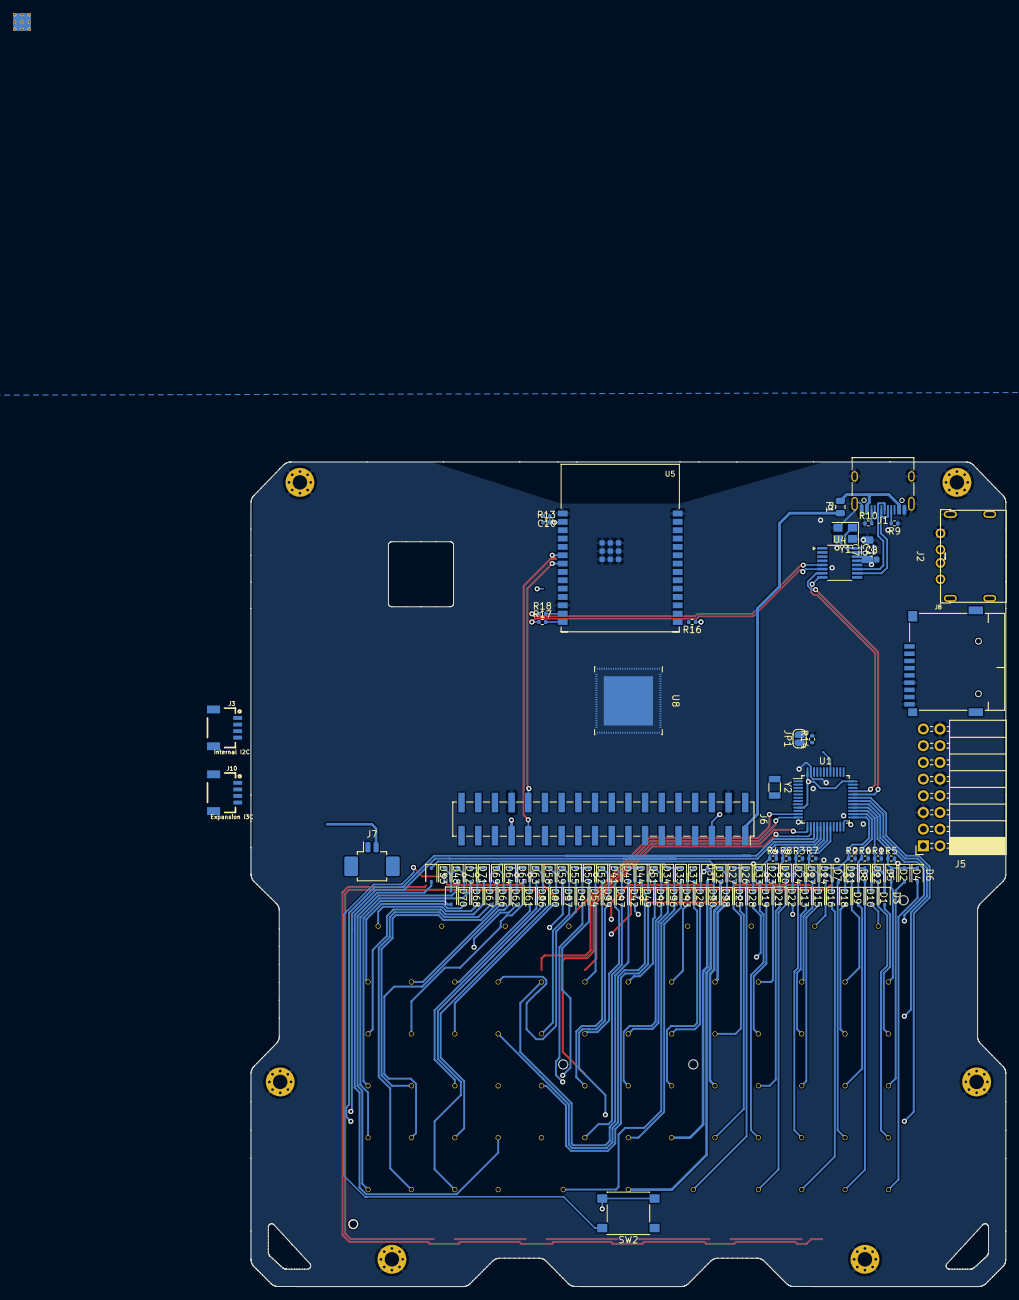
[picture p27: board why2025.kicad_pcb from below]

Board: 4 copper layers, 114.9 x 125.5 mm, 283 parts (108 on the bottom side), 248 nets.

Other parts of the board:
C28, C29, C73, C74, C75: 100n; C_0402_1005Metric
JP2, JP3, JP4, JP5: EN; SolderJumper-2_P1.3mm_Open_RoundedPad1.0x1.5mm
TP3: PR1; TestPoint_Pad_D1.0mm
TP4: PR2; TestPoint_Pad_D1.0mm
TP5: PR3; TestPoint_Pad_D1.0mm
TP6: PR4; TestPoint_Pad_D1.0mm
TP7: PRR; TestPoint_Pad_D1.0mm
U21: LM339; SOIC-14_3.9x8.7mm_P1.27mm

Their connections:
+3.3V: U21.3 (V+); also elsewhere on the board
/Application processor/Protection/~RESET: JP2.1 (A), JP3.1 (A), JP4.1 (A), JP5.1 (A); also elsewhere on the board
GND: C28.2, C29.2, C73.2, C74.2, C75.2, U21.12 (V-); also elsewhere on the board
unnamed: JP2.2 (B), TP3.1, U21.2
unnamed: JP3.2 (B), TP4.1, U21.1
unnamed: JP4.2 (B), TP5.1, U21.13
unnamed: JP5.2 (B), TP6.1, U21.14
unnamed: C74.1, U21.5 (+)
unnamed: C73.1, TP7.1, U21.4 (-), U21.6 (-), U21.8 (-), U21.10 (-)
unnamed: C28.1, U21.7 (+)
unnamed: C29.1, U21.11 (+)
unnamed: C75.1, U21.9 (+)

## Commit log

2024-03-13 Keyboard matrix
    [why2025.kicad_pcb, why2025.kicad_sch]
2024-03-13 Add library folder, add symbols, add footprint for keyboard by Jay
2024-03-15 Keyboard stuff, experiments
    [coprocessor.kicad_sch, frontpanel.kicad_pcb, frontpanel.kicad_sch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]
2024-03-16 Add radio, wire up more stuff
    [coprocessor.kicad_sch, power.kicad_sch, radio.kicad_sch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]
2024-03-17 Relabeling of ESP32-C6 GPIO, route signals to expansion header for testing
    [coprocessor.kicad_sch, keyboard_matrix.kicad_sch, radio.kicad_sch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]
2024-03-18 Boot pin, bit more routing
    [coprocessor.kicad_sch, why2025.kicad_pcb, why2025.kicad_sch]
2024-03-19 Added ESP32-p4 symbol + footprint
2024-03-21 added footprints for: PJ-327C-4A, SHOU HAN TF-CARD H1.8, USB-A: 908-371A1011D10100
2024-03-25 A bit of progress
    [audio.kicad_sch, why2025.kicad_pcb, why2025.kicad_sch]
2024-04-01 Work in progress
    [coprocessor.kicad_sch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]
2024-04-01 More work on power schematic
    [audio.kicad_sch, coprocessor.kicad_sch, keyboard_matrix.kicad_sch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]
2024-04-16 P4 stuff
    [esp32p4.kicad_sch, power.kicad_sch]
2024-04-17 Mostly power related stuff for the ESP32-P4
    [esp32p4.kicad_sch, power.kicad_sch, why2025.kicad_sch]
2024-04-23 More schematics
    [audio.kicad_sch, esp32p4.kicad_sch, power.kicad_sch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]
2024-04-28 More fixes, add display, update display backlight driver circuit, fix some of the footprint associations
    [coprocessor.kicad_sch, display.kicad_sch, esp32p4.kicad_sch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]
2024-05-05 More work on the schematic, add protection circuit, fix display pinout
    [audio.kicad_sch, coprocessor.kicad_sch, display.kicad_sch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]
2024-05-06 Assign footprints, create P4 footprint
    [audio.kicad_sch, coprocessor.kicad_sch, display.kicad_sch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]
2024-05-06 added PJ-327ST-SMT footprint
2024-05-07 Bill of materials part 1
    [audio.kicad_sch, coprocessor.kicad_sch, display.kicad_sch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]
2024-05-07 Bill of materials part 2
    [audio.kicad_sch, coprocessor.kicad_sch, esp32p4.kicad_sch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]
2024-05-09 Updated voltage regulator safety
    [audio.kicad_sch, coprocessor.kicad_sch, display.kicad_sch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]
2024-05-09 Extra text added to protection circuit page.
    [protection.kicad_sch]
2024-05-10 Updated dates on circuit diagrams.
    [audio.kicad_sch, coprocessor.kicad_sch, display.kicad_sch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]
2024-05-12 Small tweaks and fixes, update LCSC numbers on some components, change to new key type for power key
    [audio.kicad_sch, coprocessor.kicad_sch, esp32p4.kicad_sch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]
2024-05-13 Change side expansion header, add 3d models, move connectors and change board outline
    [why2025.kicad_sch]
2024-05-14 Route LED driver, sort PMIC components.
2024-05-14 Some more component placement
    [esp32p4.kicad_sch, leds.kicad_sch, why2025.kicad_sch]
2024-05-16 More routing, small fixes in schematic
    [esp32p4.kicad_sch, leds.kicad_sch, power.kicad_sch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]
2024-05-17 More routing and fixes
    [coprocessor.kicad_sch, esp32p4.kicad_sch, radio.kicad_sch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]
2024-05-17 Routed the USB and MIPI lines with the correct impedance.
    [why2025.kicad_sch]
2024-05-17 Some extra routing and fixes. +3.3V and +3v3 labels both used
    [why2025.kicad_sch]
2024-05-18 Extra routing. Changed diff pair clearenc, and track width.
2024-05-19 Routed more stuff.
    [protection.kicad_sch]
2024-05-19 More routing, move PM I2C to ESP32-C6 instead of CH32
    [coprocessor.kicad_sch, esp32p4.kicad_sch, power.kicad_sch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]
2024-05-19 More routing, moved some more signals
    [audio.kicad_sch, coprocessor.kicad_sch, esp32p4.kicad_sch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]
2024-05-20 All wires routed, lots of DRC errors to go
    [audio.kicad_sch, esp32p4.kicad_sch, keyboard_matrix.kicad_sch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]
2024-05-20 Fix 0nm secions in board outline DRC error
2024-05-21 Fix last errors, add speaker footprint
    [why2025.kicad_sch]
2024-05-22 Add more testpoints for CH32, add text, move addressable LEDs further apart
    [coprocessor.kicad_sch, why2025.kicad_sch]
2024-05-22 Add stamp, add spacer to silkscreen
    [why2025.kicad_sch]
2024-05-22 Remove some items from BOM, generate fabrication files
    [coprocessor.kicad_sch, leds.kicad_sch, power.kicad_sch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]
2024-05-22 More fabrication stuff for prototype 1
    [audio.kicad_sch, coprocessor.kicad_sch, esp32p4.kicad_sch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]
2024-05-24 Production version of prototype 1
    [audio.kicad_sch, coprocessor.kicad_sch, display.kicad_sch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]
2024-05-25 Frontpanel stuff
    [KEY-SMD_2P-L6.0-W6.0-H5.0-P6.00.step, KEY-TH_4P-L7.5-W4.3-H4.3-LS7.0-P5.0.step, SW-SMD_K1-1539SA-01.step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]
2024-05-26 Frontpanel :D
    [SC-70-6_L2.0-W1.3-P0.65-LS2.1-BL.step, audio.kicad_sch, esp32p4.kicad_sch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]
2024-05-26 Add 3d printable spacer files
    [spacer.scad]
2024-07-22 18-Add correct display connector
    [display.kicad_sch]
2024-07-27 Rerouting to get LORA chip fitted.
    [radio.kicad_sch, why2025.kicad_sch]
2024-07-27 Move LoRa capacitor
2024-07-28 Replaced voltage comparitor circuit with zener setup. Also changed couple of 0.2mm vias to 0.3
    [protection.kicad_sch]
2024-07-28 Move protection diode for VFLASH, solve DRC errors, clean up
    [protection.kicad_sch]
2024-07-29 Add the missing LCSC number to the Zener, add comment VESPHP is not related with a Zener.
    [protection.kicad_sch]
2024-07-29 add pullup for lora CS, SMA marked as dnp
    [radio.kicad_sch]
2024-07-29 Disconnect PG from reset of P4, connect to GPIO of CH32, fix warnings, make some vias bigger, add BHI360
    [coprocessor.kicad_sch, display.kicad_sch, esp32p4.kicad_sch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]
2024-07-29 Add protection for overvoltage vcore, via Opamp that pulls enable low on regulator when vcore > 1.2V
    [esp32p4.kicad_sch, protection.kicad_sch]
2024-07-30 Moved antenna more away from wifi, replaced more 0.2 with 0.3 mm vias.
    [display.kicad_sch]
2024-07-31 Resized all 0.2 mm hole vias to 0.3, cleaned up routing. 1 error 13 warnings remaining.
2024-08-01 Fix audio amplifier circuit
    [audio.kicad_sch]
2024-08-02 Proposal to add 6 mounting holes where users can screw battery boards or what ever to the badge, provide footprint + outline too if good idea?
    [why2025.kicad_sch]
2024-08-03 Remove vcore protection
    [audio.kicad_sch, coprocessor.kicad_sch, display.kicad_sch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]
2024-08-03 Clean up routing on the board, freeing up the second layer.
2024-08-04 Add 5 10uF capacitors at the USB A port.
    [power.kicad_sch]
2024-08-04 Add components to be able to use the bhi360 IC
    [sensors.kicad_sch, why2025.kicad_sch]
2024-08-04 PCB update.
2024-08-05 Standoffs, move connectors, bigger trace for vbatt
    [why2025.kicad_sch]
2024-08-06 Better copper between IC and L
    [power.kicad_sch]
2024-08-08 Add LEDs for artwork
    [leds.kicad_sch]

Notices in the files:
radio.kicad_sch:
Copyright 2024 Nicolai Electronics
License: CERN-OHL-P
